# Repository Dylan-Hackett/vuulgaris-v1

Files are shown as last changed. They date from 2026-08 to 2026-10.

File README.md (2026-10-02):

# Vuulgaris V1

A 4-channel sample-scrubbing instrument. Long capacitive copper pads on a PCB faceplate
represent the length of a waveform; dragging a finger along a pad scrubs through the sample.
Each track carries a swappable machine that is either a sampler or a synth, with Plaits as
the synth engine.

```
[ FACEPLATE PCB ]
  4x capacitive pads, ~216mm (length follows the inter-pad gap, Q17)
  MSP430FR2675TPTR (CapTIvate touch MCU) on the back side
        |
        |  UART (primary) or I2C (fallback), + IRQ, + BSL entry lines
        v
[ MAIN PCB ]
  Daisy Patch SM (STM32H750) - audio engine, sample playback, UI
  microSD socket
  2.42" SSD1309 OLED (SPI)
  Rotary encoder
  Stereo Buchla-style low pass gate (analog)
```

## Layout

| Folder | Contents |
|---|---|
| [`docs/`](docs/) | `design-state.md` (source of truth), ADRs, open questions, pin allocation, panel budget |
| [`mockups/`](mockups/) | Parametric comb pad generator, Salamis faceplate reference + dimensioned |
| [`datasheets/`](datasheets/) | Manifest, fetch script and the datasheet PDFs. |
| [`hardware/`](hardware/) | Faceplate and main PCB, gerbers, BOM spreadsheet |
| [`fw-daisy/`](fw-daisy/) | Daisy Patch SM firmware. libDaisy + DaisySP as submodules. |
| [`fw-touch/`](fw-touch/) | MSP430FR2675 firmware. CCS + CapTIvate Design Center. |

## Start here

1. **[docs/design-state.md](docs/design-state.md)** is authoritative. Everything else is
   derived from it.
2. **[docs/notes/next-steps.md](docs/notes/next-steps.md)** step 0 is the thing to do first,
   and it is deliberately cheap: one 2-layer board with **two pads in final tooth geometry**,
   roughly $50 and 2 weeks. It answers whether a moving finger reads and repeats cleanly, and
   the second pad settles the inter-pad gap, which sets the size of the whole instrument.
3. **[docs/pin-allocation.md](docs/pin-allocation.md)** is resolved and safe to lay out
   against. Zero spare bidirectional GPIO, so any addition means a removal.
4. **[docs/panel-budget.md](docs/panel-budget.md)** is **not** settled, and it hinges on one
   measurement. The Salamis composition locks `pad length = 12 x pad pitch`, so the inter-pad
   gap ([Q17](docs/notes/open-questions.md)) sets the size of the whole instrument: a 6mm gap
   gives a 298 x 154mm panel with 216mm pads, a 10mm gap gives 365 x 189mm with 264mm pads.
5. **[docs/notes/open-questions.md](docs/notes/open-questions.md)** lists what is still
   unverified. Only one is a real design risk: **Q1**, whether a moving finger on bare copper
   reads and repeats cleanly. **Q10, Q13, Q15, Q18** are bench or datasheet checks. **Q17**
   (inter-pad gap) sets the instrument size. **Q7** is a cash decision.

## Setup

```bash
# Firmware submodules
git -C fw-daisy submodule update --init --recursive
cd fw-daisy && make libs && make

# Datasheets are committed; this re-fetches any that are missing
cd datasheets && ./fetch-datasheets.sh
```

## The three facts that shape everything else

**The MCU is on the faceplate, not the main board.** TI's design guide says keep
MCU-to-electrode traces as short as possible and explicitly warns against routing capacitive
sensing lines through board-to-board connectors or cables. That is what forces the two-board
split, and only ~8-10 digital pins cross between them.

**Accuracy is not the requirement. Monotonicity and continuity are.** You scrub by listening
and adjusting, so the loop closes through your ears and absolute position error is inaudible.
A bent curve is a lookup table. What cannot be fixed downstream is a **momentary reversal**
(sample stutters backward) or a **dropout** (click). Scan rate and jitter at rest are both
settled, see [Q1](docs/notes/open-questions.md). This is where the Trautonium pivot changed
the requirements: there, position was pitch and a 2% error was a wrong note.

**Electrode order is generated first, then laid out.** `RX0->E00, RX1->E01, RX2->E02,
RX3->E03`, produced in Design Center **before** the PCB. A swapped pair gives garbage
interpolation on a board that passes every electrical check.

**Every pot past the eighth costs a bidirectional GPIO.** CV_1-CV_8 are input-only pins that
can do nothing else, so the first 8 are free. Pots 9-12, the envelope attack and release for
each stereo side, take A2, A3, D8 and D9, and that consumes all 16 bidirectional GPIO exactly.
A 13th is impossible.

**Patch SM has two USB ports, and only one of them is on the header.** DFU flashing and USB
MIDI run on the module's own onboard Micro USB (PA11/PA12). **A8/A9 are a separate USB host
port**, spent here on IO. The cost is that USB access means unscrewing the module from the
rack; firmware ships via SD card instead.

## Decisions already made

| # | Decision |
|---|---|
| [0001](docs/decisions/0001-pivot-to-capacitive-scrubbing.md) | Pivot from Trautonium analog to capacitive sample-scrubbing |
| [0002](docs/decisions/0002-msp430fr2675-for-touch.md) | MSP430FR2675 (CapTIvate) for touch sensing |
| [0003](docs/decisions/0003-comb-pad-rx0-wraparound.md) | Comb-tooth pads with RX0 wraparound |
| [0004](docs/decisions/0004-no-overlay-exposed-copper.md) | Exposed copper, no overlay, ENIG |
| [0005](docs/decisions/0005-bsl-over-daisy-uart.md) | Daisy flashes the MSP430 over BSL |
| [0006](docs/decisions/0006-ssd1309-oled.md) | 2.42" SSD1309 over SPI |
| [0007](docs/decisions/0007-buchla-lpg-over-serge-vcfq.md) | Buchla-style LPG, not Serge VCFQ |
| [0008](docs/decisions/0008-boot-sram-not-qspi.md) | BOOT_SRAM, QSPI reserved for samples |
| [0009](docs/decisions/0009-io-plan-12-adc.md) | IO plan: 12 ADC, no mux, 1-bit SD, no panel USB |

## Cost

**$162.40 at qty 1** per [the BOM](hardware/bom/vuulgaris-v1-bom.xlsx), of which **$48.76 is
confirmed** against real listings and the rest is estimated. Inside the $125-200 range in
design-state section 10.

**The enclosure is not in that number.** The prior design was CNC walnut. It is cost lever
number 3 and currently unbounded.

Stock warnings that matter: **MSP430FR2675 has 10 units at LCSC**, and the **SSD1309 has 27**.
Both are prototype quantities.

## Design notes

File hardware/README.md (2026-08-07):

# Hardware

```
faceplate/   Faceplate PCB: 4x capacitive pads + MSP430FR2675 on the back
main/        Main PCB: Patch SM, microSD, OLED, encoder, stereo LPG
gerbers/     Fab outputs, one dated subfolder per order
bom/         vuulgaris-v1-bom.xlsx
```

## Two boards, and why

The MSP430 lives on the **faceplate**, not the main board. This is not a packaging
preference. TI's design guide says keep MCU-to-electrode traces as short as possible, and
explicitly warns against routing capacitive sensing lines through board-to-board connectors
or cables, which are significant noise receptors. Only ~8-10 digital pins cross between
boards. See [ADR 0002](../docs/decisions/0002-msp430fr2675-for-touch.md).

## Before you draw anything

1. **Generate the slider electrode assignment in CapTIvate Design Center first**, then lay
   out the PCB to match. `RX0->E00, RX1->E01, RX2->E02, RX3->E03`. Swapped pins produce
   garbage interpolation and the board will look fine.
2. **Cross-check the pad geometry against SLAA891's OpenSCAD output** before committing copper.
3. **Verify the LCSC C2052972 footprint against the datasheet PT package drawing.**

Q2 and Q3 are closed. [../docs/pin-allocation.md](../docs/pin-allocation.md) is resolved and
safe to build against.

**UART and I2C do not share pins on the PT package**, so route both and select in software. Two
mappings are traps: **UCA1 UART (pins 30/29)** and **default UCB1 I2C (pins 38/39)** both land
on CapTIvate electrode pins, which are all in use.

## Faceplate rules that are easy to violate silently

- **Do not ground-pour under electrodes or their traces.** Parallel-plate capacitance to a
  nearby pour is the dominant parasitic contributor. Hatched ground at a distance if needed.
- **RX0 is one net.** Both end groups connected, return routed on the layer below, never
  under the electrodes.
- **MCU at the centre of the pad group** so trace lengths are equal across all four pads.
  Unequal lengths give unequal baselines.
- **No electrodes at PCB edges.** Weakens ground shielding.
- **Route digital lines away from electrodes**, ideally exiting the opposite edge.
- ESD parts and decoupling caps right at the MCU, low-impedance ground path.
- **Minimum copper 0.15mm, enforced.** Where a ramp would go thinner, drop the bar and give
  its height to the surviving bar. Never draw a sliver.

Suggested stackup: **L1 electrodes, L2 traces, L3 hatched ground, L4 MCU + components.**

## Fab notes

- **ENIG, not HASL.** HASL leaves uneven solder that feels wrong under a sliding finger and
  will not wear well. [ADR 0004](../docs/decisions/0004-no-overlay-exposed-copper.md)
- **Faceplate size is not settled, and it follows from one measurement.** The Salamis
  composition locks `pad length = 12 x pad pitch`, so the inter-pad gap sets the whole
  instrument: 6mm gives **298 x 154mm with 216mm pads**, 10mm gives 365 x 189mm with 264mm
  pads. Settle [Q17](../docs/notes/open-questions.md) before drawing an outline. See
  [../docs/panel-budget.md](../docs/panel-budget.md).
- Exposed copper on the pads: no soldermask over the electrodes. Decoration and instructions
  in silkscreen.
- JLCPCB **does not do overlay lamination**, which is fine given the no-overlay decision.
- microSD sockets need an **assembly fixture** at JLC for support during placement. Not a
  trivial placement, flag it on the order.

## Things to put on the board even though they seem optional

| Item | Why |
|---|---|
| **CAPTIVATE-PGMR connector** (faceplate) | Design Center cannot talk to an MSP-FET or eZ-FET. No PGMR means no live sensor data, which means no real tuning. DNP on production units. |
| **4 SBW test pads** (TEST, RST, 3V3, GND) | Free, and it is the recovery path. A $12 LaunchPad eZ-FET flashes through them. |
| **Both UART and I2C to the faceplate** | Separate pins on the PT package, so both are free to route. Populate one. |
| **Dividers on BSL RST/TEST** | Gate outs are 0-5V, MSP430 max is 3.6V. Four resistors. |
| **VREG decoupling cap, MSP430 pin 31** | CapTIvate regulator output, not a supply input. Easy to miss, and it will not work without it. |
| **Test points on all 4 inter-board signals** | When BSL does not work first time you want a scope probe point that is not an LQFP pin. |

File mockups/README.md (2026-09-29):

# Mockups

## comb-pad-generator.html

**Superseded as the source of the copper by `generate-faceplate.py` below**, which draws the
pads in place on the panel. Kept for single-pad experiments. Open in any browser, no build
step; live-checks against fab limits and exports SVG at true mm scale, one `<g>` per net.

**Its defaults are the old 175mm / 12mm pad.** The settled geometry (2026-09-27,
[ADR 0003](../docs/decisions/0003-comb-pad-rx0-wraparound.md)) is 216mm long, 10mm wide, 8mm
gap, 100 teeth; the `12 x pad pitch` length lock it was built around turned out to be an
artefact of the reference sketch.

> **Cross-check its output against TI's SLAA891 OpenSCAD scripts before committing copper.**
> Those generate TI's own validated pattern and export DXF. Two independent generators
> agreeing is worth the hour it costs.

## salamis-faceplate-reference.svg

**The agreed layout as supplied**, 2026-08-06. Full Salamis Tablet composition: an irregular
crack line dividing a five-rule control group above from four scrub pads below, vertical dividers, semicircles,
eleven tick divisions per pad with crosses at the third, sixth and ninth, Greek acrophonic
numerals in the left, right and bottom margins.

Measured proportions, which now drive the panel size:

| Element | Units | Ratio |
|---|---|---|
| Panel | 580 x 300 | 1.933 : 1 |
| Pad length | 420 | **12.0 x pad pitch** |
| Pad pitch | 35 | |

**`pad length = 12 x pad pitch` is the load-bearing relationship.** Pitch is 12mm of copper plus
the inter-pad gap, so the gap sets the size of the whole instrument. See
[../docs/panel-budget.md](../docs/panel-budget.md).

## generate-faceplate.py  <-  the one to use

**Parametric, true-scale faceplate generator.** Emits SVG in **real millimetres** (1 user unit
= 1mm), including the actual comb-tooth electrode geometry.

```bash
python3 generate-faceplate.py                          > faceplate-v1.svg
python3 generate-faceplate.py --fab                    > faceplate-v1-FAB.svg
python3 generate-faceplate.py --placement              > ../hardware/placement-panel-facing.txt
python3 generate-faceplate.py --check                  # verification report, no SVG
python3 generate-faceplate.py --set pad_length_mm=264  # one-off override
```

### How to change the layout

**Edit the `CFG` dict at the top of the file. That is the whole interface.** Every dimension,
every position and both placement flags live there. Nothing in the drawing code needs touching.

| Want to change | Edit |
|---|---|
| Panel width | `pad_length_mm` (panel derives from it) |
| Panel depth | `panel_top_extra_mm` / `panel_bottom_extra_mm` — pure extensions. **Not** `composition_h_mm`, which re-flows every panel part |
| Pad spacing | `pad_gap_mm` |
| Tick count, cross positions | `n_ticks`, `cross_at` |
| How far the scale stops inside the copper | `scale_inset_mm` (ink only: the copper never moves) |
| The gap between each pad and the gold face | `pad_frame_mm` (ADR 0013; the scale hangs from it) |
| The mask block's fillets | `mask_fillet_mm` (outer), `mask_fillet_inner_mm` (where the gaps meet the via patch) |
| Knob size or spacing | `knob_r_mm`, `knob_pitch_mm`, `offset_knob_r_mm` |
| Switch openings | `switch_w_mm`, `switch_h_mm` |
| Encoder position | `encoder_lower_right` (True = beside pads, False = upper strip) |
| Divider style | `straight_divider` (False restores the irregular crack) |
| Tooth density | `teeth_per_zone` |
| Inscription | `inscription`, `inscription_h_mm`, `salamis_marks` |

### Always run `--check` after a change

It re-derives and asserts **14 properties**, each of which has gone wrong at least once during
design:

```
  OK  pads centred on panel width          margins 41.143 / 41.143mm
  OK  centre tick == pad divider           149.143 vs 149.143
  OK  tick spacing even                    [17.0] mm
  OK  crosses on clean fractions of the scale [0.25, 0.5, 0.75]
  OK  scale inside the copper (endpoint trim) 6.00 / 6.00mm, scale 204.0mm
  OK  pad block fits lower region          75.0 in 75.2mm
  OK  min copper bar >= fab floor          0.2360 vs 0.15mm
  OK  every tooth pair sums to pad width   11.80mm
  OK  upper assembly centred               content 266.00, margins 16.14mm
  OK  encoder clears pads / centred / within OLED span
  OK  switch slots vertical
  OK  OLED inside panel
```

Exit code is non-zero on failure, so it can gate a build.

### The copper it generates

Per [ADR 0003](../docs/decisions/0003-comb-pad-rx0-wraparound.md): **100 teeth per pad**
(25 per zone x 4 zones), 2.16mm pitch, 1.95mm tooth width. Each tooth splits into a top and a
bottom bar whose heights ramp complementarily from the presence functions, so **total copper per
tooth is constant along the pad**.

Output is grouped **one `<g>` per net** (`RX0`, `RX1`, `RX2`, `RX3`) for import as separate
copper zones.

**Minimum bar drawn is 0.236mm against the 0.15mm fab floor**, so no sliver ever needs dropping
at 100 teeth. Sampling at tooth centres rather than edges is what avoids it.

### The Salamis inscription

**Plain single letters, left margin only, below the divider rule.**

```
T P X F H F A N G F C T X
```

Codes in `CFG["inscription"]`: `T` tau, `P` rho, `X` chi, `F` digamma-like, `H` eta,
`A` alpha, `N` pi, `G` gamma, `C` lunate sigma.

### Two wrong turns, recorded so they are not repeated

**First pass** read the photo correctly as plain letters but drew them alongside an invented
Χ/Η/Δ/Π/Ι denomination ladder and a row of compound glyphs along the bottom.

**Second pass over-reasoned.** It theorised the F-like and gamma-like shapes were **compound
Attic numerals**, a Π nesting a smaller Χ, Η or Δ. That produced visually busy glyphs that did
not match the photo. The theory was plausible from the numeral system, but the photo shows a
few clean incised strokes per character, not nested forms. **Direct observation should have
outranked the theory.**

**Current version returns to the plain letters** and draws them with fewer, cleaner strokes.

**Still uncertain:** the F-shapes could be digamma, heta or a damaged gamma. All are drawn the
same rather than inventing a distinction the scan cannot support. Worth checking against a
high-resolution photograph before copper. `CFG["inscription"]` is a plain string.

**Drawn as strokes, not typeset.** The Ancient Greek codepoints have unreliable font coverage
and this file goes to a fab, where font substitution is a real risk.

**Placement.** `inscription_left_only` suppresses the right column. `inscription_below_divider`
keeps every letter under the divider rule. Both asserted in `--check`.

### Departures from the reference

- **The divider rule is straight**, not the irregular crack of the original tablet.
  `straight_divider = False` restores it.
- **The pads are centred.** The reference had 90 units of left margin against 70 of right.
- **The encoder sits in the lower region**, right margin beside the pads, below the OLED.
- **The two switch openings are vertical** (9 x 20mm), crossing rules 2 to 4.
- **13 tick divisions**, crosses at 4/7/10 rather than 3/6/9 of 11. Numerals are **generated
  from `cross_at`** by `numeral_strokes(n)`, so labels cannot drift out of sync with marks.
- **Everything printed is strokes, not text** (2026-09-29): `scale_marks()` and `panel_art()`
  hold every printed mark, the numerals drawn as monoline Ι / Π / Δ rather than typeset. The
  SVG draws them, and the faceplate prints the same strokes in black soldermask on its gold
  face (`hardware/faceplate/design/mkface.py`, ADR 0013). Knob, button and screw outlines are
  drawings of parts, not art, and are not printed.

### What it is NOT, yet

**Do not send this to a fab as-is.** Three things stand between it and copper:

1. **Pad length is provisional** until [Q17](../docs/notes/open-questions.md) settles the gap.
2. **Cross-check against SLAA891.** TI's OpenSCAD scripts export DXF; two independent
   generators agreeing is the real validation.
3. **Electrode-to-pin assignment comes from Design Center first**, then the PCB is laid out to
   match. This file draws geometry, not net assignment.

No drill file, no board outline layer, no soldermask openings, no copper pour.

## salamis-faceplate-dimensioned.svg## salamis-faceplate-dimensioned.svg

**Schematic view**, pads drawn as plain bands rather than teeth. Easier to read for composition
review than the full generated file. Same 298 x 154mm working proposal.

**Control layout, decided 2026-08-06:** OLED at the right end, all 12 knobs grouped together
**standing on rules 2 and 4** of the five-rule group. The **vertical divider separates the 8
channel pots (left) from the 4 envelope pots (right)**, with the downward semicircle at its
foot as drawn.

Knobs on the rules is faithful rather than convenient: the Salamis Tablet is a counting board
and the rules are where the pebbles sat.

**Channel numerals I, II, III, IIII are printed above the four knob columns**, matching the
pad numerals in the margins. Channels run as columns in the knob block but as rows in the pad
group, so without the numerals the mapping is not legible.

## faceplate-mockup.html

Faceplate rendering: the **Salamis Tablet** layout, drawn at 219 x 110mm.

> **Superseded** by `salamis-faceplate-reference.svg` above. This one draws the 3-zone /
> no-wraparound electrode ramp and a 219 x 110mm board, neither of which is current.

Four parallel pads as the line group, with the tablet's vertical divider, semicircles,
crosses at divisions 3/6/9, and Greek acrophonic numerals in the margins. Above an irregular
crack line sits a five-rule group with a vertical divider and downward semicircle for the
screen, encoder and switches. Below, four scrub pads with a vertical divider crossing all
four, capped by an upward semicircle.

> **This is out of date and must not drive layout.** It still draws the **3-zone /
> no-wraparound** electrode ramp (E1->E4, 60 teeth). It needs the **4-zone RX0-wraparound**
> pattern from [ADR 0003](../docs/decisions/0003-comb-pad-rx0-wraparound.md) first.
> Tracked as step 5 in [next-steps.md](../docs/notes/next-steps.md).

**Note:** this file is an HTML *fragment* (a `<div>` with inline SVG), not a full document.
Browsers render it fine on open. Wrap it in `<html><body>` if you need it to validate.

## Superseded layout, for the record

Two pads each side, two diagonal one way and two the other, forming a separated triangle in
the middle of a rectangular enclosure. If it is ever revisited:

- A 216mm pad at 45 degrees needs **~153mm per axis**, so the enclosure would need roughly
  300mm in the diagonal-spanning direction.
- Convergence points create **worst-case crosstalk exactly where RX0 sits on both pads.**
  Keep closest approach >=10mm with a grounded strip between.

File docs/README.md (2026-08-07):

# Docs

- **[design-state.md](design-state.md)** - the handoff document. The single source of truth
  for the whole project. Everything else in this folder is derived from it.
- **[pin-allocation.md](pin-allocation.md)** - **resolved.** Safe to lay out against.
- **[panel-budget.md](panel-budget.md)** - faceplate area arithmetic. **Working, not decided.**
  The 219 x 110mm in design-state section 11 does not fit the current design.
- **[workflow.md](workflow.md)** - how the instrument is actually played: four synced loopers,
  resampled through the analog LPG. **Working, not decided.** Recorded because it constrains
  hardware still being locked.
- **[decisions/](decisions/)** - ADRs for choices already made and expensive to revisit.
- **[notes/](notes/)** - open questions and the worklist. Expected to change.

## How these relate

`design-state.md` is authoritative and should be updated as things change. The ADRs pull
the *decided* parts out of it into one-file-per-decision form so that a decision and its
reasoning can be cited from a schematic comment or a commit message. The notes pull the
*undecided* parts out into a worklist.

If a fact appears in both design-state.md and an ADR and they disagree, design-state.md
wins and the ADR needs updating.

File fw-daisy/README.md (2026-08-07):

# fw-daisy

Firmware for the Daisy Patch SM: audio engine, sample playback, UI, and the link to the
touch MCU on the faceplate.

## Setup

```bash
git clone --recurse-submodules <this repo>
# or, if already cloned:
git submodule update --init --recursive

make libs     # build libDaisy + DaisySP, once
make          # build the application
make program-dfu   # flash over USB DFU
```

Requires `arm-none-eabi-gcc` and `dfu-util`.

## Submodules

| Path | Repo | Pinned at |
|---|---|---|
| `libDaisy/` | electro-smith/libDaisy | `c02245d` |
| `DaisySP/` | electro-smith/DaisySP | see `git submodule status` |

Both are shallow clones. To move to a newer libDaisy:
`cd libDaisy && git fetch --unshallow && git checkout <ref>`, then commit the pointer.

## Build type is not the default

`APP_TYPE = BOOT_SRAM`, deliberately. `BOOT_QSPI` runs the program from QSPI and can grow
to ~7.75MB, which eats the sample space. SRAM execution is also faster, with a ceiling of
roughly 480-512KB using a custom linker script.

See [ADR 0008](../docs/decisions/0008-boot-sram-not-qspi.md).

## Memory model

| Tier | Size | Volatile | Use |
|---|---|---|---|
| SDRAM | 64MB | yes | **Playback buffer.** Scrubbing is arbitrary random access, so samples must be resident. |
| QSPI | 7936 KB | no | Firmware (256KB offset) + factory samples |
| SD | unlimited | no | User samples |

SDRAM buffers are declared with `DSY_SDRAM_BSS` at global scope and cannot have meaningful
constructors. They are plain static arrays in `src/main.cpp`.

## Rules that will bite you

- **Display refreshes stay out of the audio callback.** CV output timing is documented as
  degradable by OLED and MIDI activity. No full-frame redraws during timing-sensitive CV.
- **DMA buffers must be in the DMA memory section and at global scope.**
- **Do not use B9/B10 for the encoder.** They are Input Only, and libDaisy defaults `GateIn`
  to inverted because of the suggested BJT input circuit.
- **ADC_9-ADC_12 pots wire to 3V3 (A10), CV_1-CV_8 pots wire to 5V (A6).** Different groups,
  different reference.

## Findings from the submodule source

Two open questions from `docs/notes/open-questions.md` were closed by reading the pinned
source. Recorded here because the design state still carries the old concern.

### Q4: the bootloader uses 1-bit SD, not 4-bit

`DaisyBootloader/shared/bootloader.cpp:164` (HEAD `8b279a8`):

```cpp
SdmmcHandler::Config sd_cfg;
sd_cfg.Defaults();
sd_cfg.speed = SdmmcHandler::Speed::MEDIUM_SLOW;
sd_cfg.width = SdmmcHandler::BusWidth::BITS_1;
```

So SD-card firmware drops work on 3-pin wiring. The worry was backwards: it is `libDaisy`'s
`Config::Defaults()` that is 4-bit @ 50MHz, and the bootloader explicitly overrides it.
**Route all 6 pins anyway** and pick the width in software.

### Q9: the SSD130x DMA path is live

`libDaisy/src/dev/oled_ssd130x.h`. `Update()` branches on `useDma_` and calls
`TransferPageDma(0)`, which calls `transport_.SendDataDma(...)` at line 646 with
`SpiPageCompleteCallback` chaining page to page. The commented-out line at 650 is a leftover
debug variant, not the real call.

The design state's concern that `SendDataDma` "appears commented out" is stale for this
revision. At 1KB per frame it barely mattered either way.

## TODO

- Touch link over UART/I2C + IRQ, and the BSL flashing path over RST + TEST
- Sampler engine: interpolated read from SDRAM at the finger position
- Plaits synth machine
- Position smoothing, tuned against **measured** jitter, not guessed
- SSD1309 UI
- Sample loading from QSPI and SD into SDRAM at boot

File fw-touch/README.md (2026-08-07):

# fw-touch

Firmware for the **MSP430FR2675TPTR** on the faceplate. Reads four capacitive scrub pads and
reports position to the Daisy over UART (or I2C).

## Toolchain

| Tool | Version | Note |
|---|---|---|
| Code Composer Studio | current | The IDE and compiler |
| **CapTIvate Design Center** | **1.83.00.08 (May 2020)** | Generates the sensor config. Stale, and its release notes say to re-create projects made in earlier versions. |
| **CAPTIVATE-PGMR** | hardware | **Required.** Not optional, see below. |

### The PGMR is not optional

The Design Center **cannot talk to an MSP-FET or a LaunchPad eZ-FET.** The PGMR carries a
separate MSP430F5528 running HID Bridge firmware that streams live sensor data to the PC as
a USB HID device. That live view is the entire point: jitter, scan time, linearity, trim.

There is **no FR2675 dev board.** TI's own evaluation recommendation is
**CAPTIVATE-FR2676 + CAPTIVATE-PGMR**, plus **CAPTIVATE-BSWP** which is listed as required
for self-cap designs and gives a reference slider baseline. FR2676 is the same silicon for
touch purposes, just 64KB/8KB against the FR2675's 32KB/6KB. The FR2676 board has a 48-pin
sensor panel connector for plugging in your own test pad.

**Migration note:** Design Center projects target a specific device. Regenerate for
**FR2675 (PT/LQFP-48)** when moving to your own board. CAP pin *naming* carries over;
physical pins do not.

## Layout

```
ccs/vuulgaris-touch/   CCS project
design-center/         .captivate project files
captivate/generated/   Design Center output, REGENERATED not hand-edited
tuning/                Measurement logs: scan time, jitter, linearity, trim values
docs/                  pin-assignment.md, bsl-protocol.md
```

## Order of operations, and it matters

1. **Generate the slider electrode assignment in Design Center FIRST.**
2. **Then lay out the PCB to match.**

`RX0->E00, RX1->E01, RX2->E02, RX3->E03`. Swapped pins produce garbage interpolation on a
board that passes every electrical check. See [docs/pin-assignment.md](docs/pin-assignment.md).

## Sensor configuration

Four sliders, four electrodes each, 5 segments / 4 interpolation zones with **RX0 appearing
at both ends** as a single net. Full geometry in
[ADR 0003](../docs/decisions/0003-comb-pad-rx0-wraparound.md).

**No overlay.** Direct finger-to-copper contact, which is outside TI's design assumptions
since all their tuning guidance assumes 1.5-4mm of plastic. Expect a **larger signal delta**
than the reference designs and **retune for lower conversion counts.** That is a gain, not a
problem: it buys margin on latency and filtering. See SLAA843.

### What to measure first

| Measurement | Where | Why |
|---|---|---|
| **Scan time across 4 sliders** | Design Center reports it directly | 4 blocks x 4 pins means each slider's elements scan in parallel, but the four sliders scan in **four sequential cycles**. Effective per-pad rate is 1/4 of a single-slider design. No published number exists for this config. |
| **Jitter at rest, in counts** | Design Center live view | Usable resolution is `configured_resolution / jitter_counts`. Set 1000 and measure N; the answer is 1000/N. **This is the number that decides whether scrubbing sounds like an instrument.** |
| **Linearity** | drag a finger, log position | Validates the ratio-encoded comb geometry. |
| **Lower_Trim / Upper_Trim** | touch each end, observe | A finger's centroid does not align with the slider endpoint, so most layouts cannot reach 0 and max. Plan for a few dead millimetres at each end. |

Log results in `tuning/`, dated, with the board revision noted.

### Noise immunity is a trade, not a free win

Enabling it turns on frequency hopping, aggregating four conversion frequencies. That
multiplies scan time **x4 on top of** the four sequential sliders. It is the first knob to
trade if latency is tight, weighed against sitting next to switching supplies and audio
circuitry.

## Do not touch the security settings

BSL code is in secure ROM and cannot be overwritten. Even with JTAG disabled, the BSL still
works. **The one permanent brick is deliberately disabling BSL *and* locking JTAG.**

**Rule: leave JTAG/SBW unlocked and BSL enabled.**

The 4 SBW test pads on the faceplate (TEST, RST, 3V3, GND) are the recovery path. A $12
MSP430 LaunchPad's eZ-FET flashes through them.

See [docs/bsl-protocol.md](docs/bsl-protocol.md) and
[ADR 0005](../docs/decisions/0005-bsl-over-daisy-uart.md).

## Bench stand-in

A SoftPot is a bad product part (needs pressure, +/-3% linearity, $9-27 each, finite cycle
life) and a fine **development** stand-in. Use one to settle firmware and scrubbing feel on
the Daisy side before cap-touch hardware exists.

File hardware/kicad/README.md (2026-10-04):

# Vuulgaris V1 — KiCad project (main PCB)

**Migrated from EasyEDA 2026-08-16.** Schematic connectivity is generated from a
declarative netlist and verified against KiCad's own netlister. Requires KiCad 7.

```
vuulgaris.kicad_sch   69 components, 217 connections, 66 nets — VERIFIED 217/217
vuulgaris.kicad_pcb   284.3 x 125.0mm on Edge.Cuts
lib/                  symbols + footprints (see below)
tools/                the generator and the netlist it generates from
```

## Why this exists

The EasyEDA version was abandoned after its API repeatedly reported success for
writes it had not performed — `deleteBoard` returning true having deleted nothing,
`importChanges` returning true and doing nothing, wires created at exact pin
coordinates that the netlister then refused to bind. It produced a board where
**`P3V3_DAISY` was shorted to `I2C_SDA` across 9 pads** and both LDO outputs sat on
GND, and no ERC would flag any of it, because every one of those is an electrically
legal connection. It was only ever caught by diffing pad nets against an explicit
intended map.

KiCad's design is a text file. A write either happens or raises. That is the whole
reason for the move.

## The verification loop

This is the thing worth preserving. `tools/netmap.json` is the **intent**: every
pin that carries a net, taken from `docs/pin-allocation.md`. The check is:

```bash
python3 tools/mksch.py && python3 tools/netcheck.py
```

`mksch.py` is the drawing engine; the design it draws — which symbol each ref uses,
where it sits on the sheet, which footprint it gets — is `tools/design.py`. They were
one file until 2026-09-27, when the faceplate needed the same engine. The loop tools
(`mksch`, `netcheck`, `drc`, `boardcheck`, `ksym`) all take `--project faceplate`;
`tools/proj.py` says where each project keeps what.

`netcheck.py` exports the netlist with `kicad-cli` — KiCad's own code, not a
reimplementation — and diffs every `(ref, pin) -> net` both ways. The reverse
direction is the one that matters: a pin KiCad bound to a net that `netmap.json`
never asked for is exactly the `P3V3_DAISY`-shorted-to-`I2C_SDA` failure above,
and no ERC will ever flag it. **Re-run it after any change.**

Then, before plotting fab files:

```bash
python3 tools/place.py --check && python3 tools/gerbercheck.py
```

And the one that has the last word on clearance:

```
python3 tools/drc.py
```

`drc.py` runs **KiCad's own DRC** through `pcbnew.WriteDRCReport`, because
`kicad-cli` in 7.0.8 cannot. It fails on anything the project settings call an
ERROR and merely counts WARNINGs, of which this board has ~270 silkscreen ones
that JLC clips at plot time.

`boardcheck.py` is still worth running — it is fast and it checks parity
against `netmap.json`, which DRC knows nothing about — but it is no longer the
authority on clearance. It reimplemented the geometry and got the X-crossing
case wrong, so two tracks lying on top of each other on `/LPG_LED` and
`/LPG_LEDK` measured 0.6mm apart and it reported the board clean for days.
Pcbnew found them in a second.
```

## Libraries

| Library | Source | Notes |
|---|---|---|
| `lib/vuulgaris.kicad_sym` + `.pretty` | `easyeda2kicad` from LCSC part numbers | Same geometry as the EasyEDA parts, not a reinterpretation |
| `lib/daisy_es.kicad_sym` | [GregBurns/sm_kicad](https://github.com/GregBurns/sm_kicad) | Daisy Patch SM **plus** a Eurorack kit — jacks, toggles, pots, LEDs, power symbols |

Adding a part:

```bash
easyeda2kicad --full --output lib/vuulgaris --lcsc_id CXXXXXXX
```

**The Daisy symbol here has all 40 pins including A7 (GND).** The EasyEDA community
symbol was missing A7 entirely, which passes ERC silently — a pin that does not
exist cannot be reported unconnected. That defect does not exist in this project.

**Footprint format caveat:** easyeda2kicad writes the legacy `(module ...)` form.
KiCad converts it correctly when loading from the library, but it cannot be pasted
raw into a `.kicad_pcb`. Pull footprints in via Update PCB from Schematic, not by
editing the board file.

## Placement

Two kinds of position, governed differently:

| | Governed by | Move it in Pcbnew? |
|---|---|---|
| **Panel parts** (20) | the faceplate artwork | reverted, and reported — a knob has to come through its hole |
| **Free parts** (23) | you | kept. `place.py` re-reads them every run |

So: **drag the free parts around in Pcbnew, save, and they stay put.** Their
positions are recorded in `tools/free-placement.json` so the layout shows up in a
diff. A part missing from that file is new — it just arrived via F8 — and gets
seeded once from `FREE_SEED`, then the board owns it. `--reset` throws away free
moves and goes back to the seed.

Panel-facing parts are **derived, not chosen** — their coordinates come from
`hardware/placement-panel-facing.txt`, itself generated by
`mockups/generate-faceplate.py --placement`. KiCad PCB space is Y-down and native
millimetres, the same convention as that file, so the only transform is the origin
shift:

```
pcb_mm = panel_mm - (6.995, 7.000)
```

**Footprint origin is not the shaft.** What must line up with a faceplate hole is
the shaft axis, and for three of these parts that sits away from the origin:

| Part | Footprint | Shaft / centre at | Evidence |
|---|---|---|---|
| ENC1-ENC10 | `SW-TH_EC12EXXXX` | `(0, -3.75)` | silk body centre **and** both mounting lugs |
| ENC0 | `SW-TH_ALPS_EC11L1525G01` | `(0, -0.20)` | bushing circle r 4.00 |
| RV1-RV6 | `RES-ADJ-TH_RK09L1240A12` (dual-gang, Alpha `RD902F` fitted) | `(0, -5.00)` — but **placed** at `(0, -4.83)`, see `place.py` | on the tab-slot line: the ALPS RK09L and Alpha RD902F drawings |
| SW4-SW9 | `KEY-TH_4P-L12.0-W12.0-P5.00-LS12.5` (12x12 tactile) | `(0, 0)` | pads symmetric about the origin |
| DS1 | `LCD-TH_HS242L01W4S01` | header, mid of the left edge | (folded into `PANEL`) |

Placing those by origin puts the knob 4-5mm off its hole, which nothing downstream
would flag. `ORIGIN_OFFSET` in `place.py` carries the correction.

**Only ENC0 and the pots have a bushing circle to key off.** The EC12 has none —
its only circles are four r=0.9 pad drill markers, and treating the largest of
those as a shaft puts the part 4.1 x 5.1mm out. Infer the shaft from the largest
circle *above r 1.5*, the silk body centre, and the largest pad, and accept the
part if **any** of them lands on the hole. That is what `place.py` does.

Because `ORIGIN_OFFSET` is an input, checking board positions back against the
panel file cannot validate it -- both sides use the same table, so a wrong value
passes in both directions. `place.py` therefore re-derives each shaft from the
footprint's own geometry and reports disagreement. That check is what caught
ENC1-ENC10 sitting 3.75mm high after they had already been committed and pushed.

`place.py` also reports **footprint overlaps**, bounding each part by its own pad
and outline geometry. No ERC or DRC catches a part sitting on another at this
stage, and it already caught U5 landing on ENC6.

## Editing protocol

> **This has now cost real work four times.** Pcbnew's in-memory snapshot has
> overwritten placement twice, the whole headphone block once, and -- worst --
> silently restored a **damaged board outline** after it had been repaired on
> disk. Close it.

KiCad holds the design in memory and both **F8 and Save read from that snapshot,
not from disk.** An Eeschema window left open while these tools run will silently
overwrite them on its next save, and F8 from a stale window reports "no changes"
for edits that are sitting on disk. **Close Eeschema and Pcbnew between hand-offs.**

### pose.py -- F8 does not remember which SIDE a part is on

`place.py` owns X/Y. It does **not** own layer or rotation, because those live only
in the board file. So every F8 that re-imports a footprint drops it back on `F.Cu`
at 0 degrees, and the work of flipping a block to the back is gone. **This has
happened three times:** the bypass caps, then the entire headphone block, twice.

`pose.py` is the other half. It snapshots layer+rotation for all 295 parts (160 of
which are not `F.Cu`/0) and puts them back:

```
python3 tools/pose.py --save     snapshot what the board currently is
python3 tools/pose.py --check    report what drifted, write nothing
python3 tools/pose.py            put it back
```

**Order after an F8:** `place.py` -> `pose.py` -> `place.py --check`.

A pad's angle in the file is **absolute** -- the footprint rotation is already
folded in -- so turning a footprint means rewriting every pad angle. `pose.py`
recovers the relative angle from the board's own current pose rather than from the
library, because the library lookup is keyed on pad coordinates that do not always
match, and a miss there invents a rotation out of nothing. That is what put 270 on
J9's oval pads, which carry none. Verified by clobbering all 160 posed parts to
`F.Cu`/0 and restoring: byte-identical except for the silkscreen note below.

> **That silkscreen note was the tip of a real bug.** Back-side text missing
> `(justify mirror)` turned out to correlate perfectly with footprints that had
> been moved to `B.Cu` by rewriting layer names and nothing else. See below.

## A B.Cu footprint has to be MIRRORED, not just relabelled

**KiCad applies no implicit mirror.** Proven 2026-09-09 with `kicad-cli pcb export
svg`: a pad at footprint-local `(0, +3)` plots to the *same absolute place* whether
its footprint sits on `F.Cu` or `B.Cu`. Front and back render identically.

So the flip has to be **baked into the stored coordinates**. A part on the back
carries negated local Y; a part whose coordinates still match the library is not
flipped, it is the **front land pattern printed on the back layer** -- pin 1 where
pin 8 belongs, chip soldered mirror-image.

**Thirteen parts were in that state**, and they were not minor ones:

`Q1`, `Q2`, `U101`, `U102`, `U103`, `U104`, `U106`, `U201`, `U202`, `U203`,
`U204`, `U206` -- both V3205SD bucket brigades, both CD4046 clocks, five of the
six TL072s, and both transistors. Effectively the whole analogue block. That board
would not have worked.

### Why nothing caught it

`place.py` was computing every back-side part's geometry with an extra mirror of
its own (`mir = -1.0 if side != F.Cu`), so a half-flipped part came out looking
right: two errors that cancelled inside the checks. The old comment on that line
claimed Gerber verification against J7 and J11 -- but **J7 is correctly mirrored
and J11 is on the front**, so the check compared a double mirror against a single
one and read the agreement as proof.

The tell was sitting in the same file the whole time. `place.py`'s pad-**angle**
check already assumed baked-in mirroring (`rel = -lib_angle` when on the back).
The position maths and the angle maths had contradicted each other for months.

### The guard

`place.py` now fails loudly on any `B.Cu` footprint whose asymmetric pads still
match the library. Symmetric parts (every 0603) are skipped, because for them a
Y-mirror is a no-op. Verified by deliberately half-flipping `U102` and confirming
it is named.

> Do not "flip" a footprint by editing layer strings. Use `pose.py`, which mirrors
> geometry, swaps the layer names, and mirrors the text justification together.

### The bug that pass shipped, and how it showed up

Splitting a board file into footprints by "start of one to start of the next,
with end-of-file as the last boundary" makes the **last footprint's block swallow
everything after it** -- `Edge.Cuts`, the zone, all of it. The mirror transform
then negated Y on the board outline, and the faceplate connector cutout came
apart.

The four `gr_arc` corners survived, because the negation regex wanted
`(start ...) (end ...)` adjacent and an arc carries a `(mid ...)` between them.
So the cutout lost its four straight edges and kept its four rounded corners --
which is the sort of luck that hides a bug instead of revealing it. It took
someone looking at the board to notice.

`place.py`'s `fp_blocks` had always done this correctly, walking to the balanced
closing paren. `pose.py` rolled its own and got it wrong.

**And then it came back.** The outline was repaired on disk and committed, but
Pcbnew still held the pre-fix board in memory; the next save wrote its snapshot
straight over the repair. What that looks like from the outside is an outline
that "needs to be moved" -- the parts sit at y 50-167 and the outline at y -50 to
-167, so it is drawn nowhere near the board. `place.py` now checks the outline
**before** it measures anything against it, because "pads inside the outline"
passes trivially when the outline is somewhere else entirely. **Every tool that slices
this file now ends a block at its balanced paren**, and the same bug was silently
dropping `pose.py`'s writes on three parts, which is why C505 and C511 kept
reverting to a rotation nobody asked for.

## place.py checks the board is actually THERE, and that the chip is not

Two placement mistakes got past the checks in one day, both the same shape: the
search enforced **pad**-to-pad clearance and nothing else.

**1. The board has a hole in it.** The faceplate-header cutout is 24 x 12mm at
board (210, 97.5)-(234, 109.5). "Bodies/pads inside the outline" only bounds the
board RECTANGLE, so two test points placed in the slot passed every check and were
caught by eye. `place.py` now reads interior `Edge.Cuts` loops and reports
`clear of all N board cutout(s)`.

**2. A pad can sit under a chip without touching a pad.** `V3205SD` is a DIP-14
land pattern with the middle three pins omitted on each side, so there is a wide
pad-free gap down the centre of a package that is physically still there. Two test
points landed in that gap: 2mm from any pad, and underneath the plastic. The
`body overlaps, SAME face` list already caught it -- the placement search did not,
because it only looked at pads. Searches now check **body separation as well as pad
clearance**.

The general lesson, twice over: *pads are not the part, and the outline is not the
board.*

## The courtyards in this library are FAKE -- do not trust a courtyard DRC

Every `easyeda2kicad` footprint here has its courtyard drawn as the **plastic body
outline**, which is *smaller than its own pads*:

| footprint | courtyard | pads actually reach |
|---|---|---|
| `C0603` | +/-0.80 x +/-0.40 | **+/-1.10 x +/-0.45** |
| `SOIC-8_L4.9-W3.9-P1.27-LS6.1-BL` | +/-2.50 x +/-2.00 | **+/-3.05** |

IPC says a courtyard is pads + body + margin. These are body-only. A courtyard
overlap check -- **including KiCad's own DRC** -- therefore passes a board whose
parts physically collide, and this board reports **0 courtyard overlaps** while
having had parts 0.64mm apart. That is why nothing ever complained.

**So clearance here is checked pad-to-pad in `place.py`, not by courtyard.** If you
ever run KiCad's DRC, its courtyard result means nothing until the library is
fixed.

## Crowding: overlap is not the only failure

`place.py` reports the **tightest pad-to-pad clearance on the board** and lists
everything under 1.0mm. Being on the same net earns a part nothing here — the
connection is made by copper, not by proximity, and a 0603 sitting 0.3mm off a
SOIC pin passes every overlap check while still being impossible to rework.

JLC's assembly floor is ~0.2mm, but that is a *fabrication* limit, not a working
clearance, so the check warns at **1.0mm** and only fails under **0.45mm**.

Current tightest, all understood:

| gap | pair | why |
|---|---|---|
| 0.80mm | SW4/5, SW6/7, SW8/9 | the button column pitch. 14.7mm shorts outright, 15.5mm leaves 0.8mm — a deliberate floor, and they are through-hole so hand-solderable |
| 0.82mm | DS1 x J1 | pre-existing, OLED header against the SD socket |
| 0.95mm | TP8/10/11/12 | test points, placed to 0.4mm search clearance |

The 24 bypass caps used to sit at **0.64mm** — I put them there chasing short
decoupling paths and it was too tight to get an iron in. Re-placed against a
**1.0mm pad-to-pad floor**; the cost was almost nothing, 2.1-3.1mm from the power
pin became 2.4-3.2mm.

## The LPG trimmers are SMD and live on the BACK

`RT301`/`RT401` are **3224W-1-203E**, LCSC **C55071** -- the SMD sibling of the
Bourns 3266W they replaced: same 4mm square multiturn cermet, **12 turns**,
top-adjust. Footprint pulled with `easyeda2kicad`, same as every other part here.

**Multiturn is not optional.** These set the vactrol LED drive depth, which is
adjusted by ear against a scope at bring-up. The 3x3mm single-turn parts on LCSC
are cheaper and better stocked, but they put the whole 20k into 270 degrees.

**They sit on `B.Cu` while the rest of the LPG is on `F.Cu`.** The front is under
the faceplate, so a top-adjust trimmer there is only reachable with the panel off.
Vactrols age -- and these are the Xvive reissue with known batch spread -- so
re-trimming is a real event, not a one-off.

Swapping this also took two parts off the hand-solder list. What is left there is
genuinely unsourceable rather than merely inconvenient: `V3205SD` x2, `VTL5C3` x4,
the DW3 switches x2, and the Daisy module.

> **Changing a footprint needs more than F8.** "Update PCB from Schematic" only
> syncs nets and adds/removes parts by default; a footprint swap on an
> already-placed component is opt-in. Tick **"Replace footprints with those
> specified in the schematic"** or nothing happens -- silently, with the dialog
> reporting success.

## Input level: the 1/4" jacks are a LINE input, and were wired at unity

`J7`/`J8` fed `U1.B3/B4` through nothing but a coupling cap. The Patch SM's full
scale is Eurorack 9.5Vpp = 3.36Vrms, so a normal source lands well short:

| source | nominal | at unity |
|---|---|---|
| receiver / RCA line out | 0.32Vrms | **-20.5dBFS** |
| phone or laptop headphone out, full | ~1.0Vrms | **-10.5dBFS** |
| pro +4dBu | 1.23Vrms | -8.7dBFS |

**Software gain does not fix this.** Digital gain lifts the converter's own noise
floor with the signal; 20dB below full scale is 20dB of ADC dynamic range already
gone. Only analogue gain ahead of the ADC gets it back.

Worth being explicit about why this is a line input and not a Eurorack one: **audio
I/O is PJ-603 (1/4"), CV is PJ-376 (3.5mm).** Nothing Eurorack arrives at J7/J8
without an adapter, so there was never a reason to calibrate them for 9.5Vpp.

### U10, and where it sits

```
J7 tip --R517 1k-- C511 1uF --+-- U10A +        gain = 1 + RT503/R521
                            R519 100k                = 1x to 10.1x  (0 to +20dB)
                              GND
                   U10A - --+-- R521 2k2 -- GND
                            +-- RT503 20k rheostat -- U10A out
                   U10A out -+-- C501 1uF -- SW2.1
                              +-- R302 10k -- LPG input mix (C306)     since 2026-09-25
```

**U10 also drives the LPG directly** (ADR 0011): its output is mixed with the Daisy's into
the LPG input through `R302`/`R402`, so external audio reaches the analog chain with no
conversion and can be resampled after the effects in one pass. `C306`/`C406` block its DC
there, as `C501` does on the way to the Daisy.

**Before SW2, on the EXT branch only** -- the resample path is already at Eurorack
level and must not be gained.

- `U10` is a second **OPA1688**, the same part and footprint as U9. No new library work.
- `RT503`/`RT504` are the same **3224W** 12-turn as every other trim here, on `B.Cu`.
  Wiper tied to one end, as `RT301` is: a wiper fault then gives maximum resistance
  rather than an open feedback loop.
- At minimum the trimmer is 0R and the stage is a unity follower, so a hot source
  is still safe.
- `C501` already blocks DC into SW2, so U10's offset never reaches the Patch SM and
  the feedback leg needs no cap of its own.
- `R519` 100k sets the input impedance -- a proper bridging load -- and gives 1.6Hz
  with `C511`.
- `R517`/`R518` 1k are series protection. There was none: `C501` went straight onto
  a module pin, and a source peaking at +18dBu is 17.4Vpp against a +/-4.75V input.
  Against 100k the 1k costs under 0.1dB.

## The audio coupling caps are 0805, and they were never going to be film

Fourteen caps carried the value **"1uF film" in an 0603 footprint**. That is not a
part anyone can ship. SMD film tops out around **0.1uF** (PPS, Panasonic ECHU) in
1210; 1uF film means a leaded box cap about 7x7mm on a 5mm pitch -- through-hole,
hand-soldered, on a board whose hand-solder list was deliberately cut down to four
genuinely unsourceable parts. Whatever got assembled was always going to be a
Class II MLCC, and the value string was describing a wish.

`C113 C120 C213 C220 C306 C406 C501 C502 C503 C504 C505 C506 C511 C512`
-> **1uF X7R 50V, C0805.**

**Why 0805 and 50V rather than just renaming them.** Class II voltage-coefficient
distortion scales with the field across the dielectric. A 1uF 50V part in 0805 has
more and thicker layers than a 1uF 16V part in 0603, so on a **+/-4.75V Eurorack
signal** -- nearly a third of a 16V part's rating -- it distorts substantially
less for the same job. Same money, same reel, same pick-and-place.

**1uF C0G would be genuinely linear and is not an option**: it does not exist below
2220, runs a few dollars each, and fourteen of them would cost more than the rest
of the passives put together and swallow the board.

Eleven of the fourteen took the bigger footprint where they stood. `C505` turns 90
degrees to clear J6's body, `C511` moves 3.4mm, `C512` 0.25mm.

> **This one needs the checkbox.** A footprint swap on an already-placed part is
> opt-in: tick **"Replace footprints with those specified in the schematic"** in
> the F8 dialog or nothing happens, silently, with the dialog reporting success.

## Output levels: three different jobs, three different levels

Everything inside the instrument runs at **Eurorack level, 9.5Vpp (+/-4.75V)** --
verified from the Patch SM datasheet v1.0.5, which benchmarks SNR against exactly
that reference sine. Bergman's LPG expects the same, so `AUDIO_OUT -> LPG ->
AUDIO_IN` is level-matched end to end. See `docs/design-state.md` section 6.

`BBD_OUT_L/R` is that node. **Three things hang off it, and only one of them wants
Eurorack level:**

```
U103 --470R(R131)-- BBD_OUT_L --+-- C503 1u ---- SW2 -- AUDIO_IN_L    9.5Vpp, internal
                                |
                                +-- C505 1u -- R509 100k -+- RT501 20k -- GND
                                |                    wiper |
                                |                          U9 (unity) --4R7-- J6 tip
                                |
                                +-- R513 1k2 --+-- J9 tip   (1/4" line out)
                                              R514 1k
                                               GND
```

**The attenuators sit DOWNSTREAM of the C503 and C505 taps.** That is the whole
trick, and it is the reason nothing internal had to change: the resample loop and
the headphone feed still see the Eurorack level they were designed around, while
the jack sees whatever the divider gives it.

*Nearly* that level: the taps are on the far side of `R131`, and the line-out
divider loads that node with 2.2k, so `BBD_OUT` sits at 2200/2670 = 0.82 of
U103's swing, **-1.7dB**. The resample path reaches the Patch SM about 2dB under
full scale instead of at it. Harmless, but it is not the unloaded buffer level.

### 1/4" line out (J9/J10) -- +4.2dBu full scale

`R131` 470R is already in series, so the divider is **(470 + 1200) : 1000**.
(`R513`/`R515` are 1k2 on the board. This section was written for 1k3; the
numbers below are for 1k2, 0.3dB hotter.)

| | |
|---|---|
| ratio | 1000/2670 = 0.375, **-8.53dB** |
| full scale | 3.359Vrms -> **1.258Vrms = +4.2dBu** |
| output impedance | 1670 \|\| 1000 = **625R** |
| load on U103 | 2670R -- a TL072 is rated to 2k, so this is inside spec |

It was **+12.7dBu** before, straight off the buffer. That survives a pro interface
(+18 to +24dBu max) but clips consumer -10dBV gear and anything with an instrument
input. +4.2dBu is safe everywhere and still hot enough to ignore the noise floor:
625R of thermal noise is 3.2nV/sqrt(Hz), about **-125dBu** over 20kHz.

Passive is the right answer here -- U103 already buffers the node, so a divider
costs two 0603s and no active parts. Into a 10k line input you lose another 0.5dB.
Into a 600R vintage input you lose 6.2dB, which is the one case worth knowing about.

### Headphones (J6) -- set once, on the back

`RT501`/`RT502` are the same **3224W** 12-turn cermet as the LPG trimmers, on
`B.Cu` for the same reason. Max attenuation is 20k/120k = 1/6, giving **0.56Vrms**
at the buffer output.

> **U9's own bypass caps were 15mm away, and nothing was checking.** `C507`/`C508`
> were never in `place.py`'s `BYPASS` table, so the headphone driver shipped with
> decoupling that was decoration -- the trace inductance in series with a 100nF at
> that distance undoes most of what it is for. Adding U9 and U10 to the table
> caught it immediately; `RT502` had to move 7.5mm off pin 8 to free the pocket.
> **Every chip with a bypass cap belongs in that table**, or the check is only
> auditing the parts that were already right.

`R511`/`R512` are **4R7, not 22R.** They sit OUTSIDE the feedback loop -- U9's
feedback comes off `HP_BUF_L`, before them -- so they set output impedance directly:

| load | with 22R | with 4R7 |
|---|---|---|
| 32R | 0.332Vrms, 3.4mW | **0.488Vrms, 7.4mW** |
| 250R | 0.550Vrms, 1.21mW | 0.550Vrms, 1.21mW |
| 600R | 0.556Vrms, 0.51mW | 0.556Vrms, 0.51mW |

22R cost 4.6dB into 32R cans, but the real problem was **damping factor 1.5.**
The rule of thumb is Zout <= 1/8 of the load; dynamic headphones have a bass
impedance resonance peaking at 2-4x nominal, so 22R bumps the low end by a
different amount for every pair you plug in. 4R7 is 1/6.8 of 32R -- close enough
to the rule, and flat.

The OPA1688 does not need the isolation: it is a purpose-built headphone driver,
internally short-circuit protected, +/-75mA, unity-gain stable. At 0.488Vrms into
32R it sources 22mA peak. TI's own headphone circuits use 10R or nothing.

**No output coupling cap, deliberately.** `RT501`'s bottom end grounds the divider,
so the wiper sits at 0V DC and U9 contributes only its own offset (+/-0.5mV typ).
A few mV across 32R is 0.1mA -- inaudible, and better than the electrolytic every
cheap headphone amp puts there. The input highpass is C505 1uF into the full 120k:
**1.33Hz**, and it does not move with the trimmer, because the wiper position does
not change the end-to-end resistance.

## Net classes and trace widths

Set 2026-09-09, from IPC-2221 against the real stackup: **1oz outer (35um),
0.5oz inner (15.2um)**, 10C rise. `I = 0.048 * dT^0.44 * A^0.725`, A in mil^2.

| width (1oz outer) | carries at 10C rise |
|---|---|
| 0.25mm | 0.88 A |
| 0.50mm | 1.45 A |
| 0.60mm | 1.65 A |
| 1.50mm | 3.21 A |

| class | nets | track | clearance | via |
|---|---|---|---|---|
| `Power_5V_IN` | `VBUS`, `VBUS_F` | **1.5mm** | 0.20mm | 1.0/0.5 |
| `Rails_12V` | `POS12V`, `NEG12V`, and both `_RAW` | **0.6mm** | 0.20mm | 0.8/0.4 |
| `Power_5V` | `P5V`, `P5V_OLED`, `P5V_MSP`, `P5V_BBD` | 0.5mm | 0.20mm | 0.8/0.4 |
| `Power_3V3` | `P3V3_DAISY`, `P3V3_MSP430`, `P3V3_OLED` | 0.5mm | 0.20mm | 0.8/0.4 |
| `GND` | `GND` | 0.5mm | 0.20mm | 0.8/0.4 |
| `Default` | everything else, audio included | 0.25mm | 0.20mm | 0.8/0.4 |

Clearance is 0.20mm in every class (commit `5141496` relaxed the two that were
wider). Eleven vias are **0.6/0.3**, not the class size: ten on `ENC4_A/B`,
`ENC8_A/B` and `BTN4`, where U4's pins would not escape with 0.8/0.4 (2026-10-03,
`docs/review/recheck/fix-mcp23017-gpa7-gpb7.md`), and the one that feeds `C44`
from U4.9's track, between the two legs of `ENC8_B`. The board minimum is 0.5/0.3.

**`VBUS` is the only rail ampacity actually constrains.** It feeds the DKM10E-12
through a 2.0A PTC, and IPC wants **0.78mm** for that. 1.5mm carries 3.21A at 10C
and is still only about 20C at the PTC's **4.0A trip** -- a fault condition, not a
duty cycle.

**The 12V rails are wide for impedance, not for heat.** The DKM is 10W across both,
so roughly 420mA each, and IPC wants **0.09mm**. That is a hair, and a hair is a
bad idea on a rail feeding eleven op-amps: 0.6mm is about 4x the requirement and
is chosen so the rail is stiff and reworkable.

> **Keep power on F.Cu / B.Cu.** The inner layers are 0.5oz, and IPC-2221 uses a
> halved constant for internal traces. Carrying `VBUS`'s 2A on In1.Cu would need
> **4.7mm**; even the 12V rails would want 0.54mm rather than 0.09mm. In2.Cu is
> the ground plane and In1.Cu is for signals.

Net-to-class assignment lives in `vuulgaris.kicad_pro` under
`net_settings.netclass_patterns`, keyed on the board's net names, which carry a
leading `/` (`/POS12V`, not `POS12V`).

## Autorouting, with GND left alone

KiCad 7 has no autorouter and `kicad-cli` cannot export DSN, so routing goes out
to **Freerouting** and comes back as a Specctra session.

**Installed 2026-09-09:** `~/tools/freerouting/freerouting-2.4.1.jar`, 64,076,787
bytes, sha256 `251101c3eeac22d7e7dfcf6796603279e5d1000283eb82d8f093780f7afc6aa9`,
from the project's own GitHub release v2.4.1 (2026-09-03). Its manifest is built
by GitHub Actions with Adoptium 25 and its classes are major 69, so it wants
**JRE 25 or newer**; this machine has openjdk 26.0.2.1.

Only the export and import steps need the GUI. **The routing itself is headless**,
which means it can run unattended and be repeated:

```
# 1. Pcbnew:  File > Export > Specctra DSN   ->  vuulgaris.dsn
python3 tools/dsnfilter.py vuulgaris.dsn

# 2. route -- no GUI, no clicking
java -Djava.awt.headless=true -jar ~/tools/freerouting/freerouting-2.4.1.jar \
     -de vuulgaris-noGND.dsn \
     -do vuulgaris.ses \
     -mp 100

# 3. Pcbnew:  File > Import > Specctra Session
# 4. fill the In2.Cu GND zone, then place stitching vias by hand
```

`-mp` is the pass count, `-mt` the thread pool (defaults to one fewer than the
logical processors). Because it is scriptable, a bad result costs one command,
not an afternoon -- change the rules or the filter and run it again.

### What dsnfilter.py takes out, and why

**`/GND`.** Its `(net ...)` block goes, and its name is scrubbed out of every
`(class ...)` member list -- a KiCad DSN names each net twice, and deleting only
the block leaves the class quoting a net that no longer exists. Ground pads then
carry no net, so Freerouting treats them as plain obstacles to keep clear of and
never wires them. Ground comes from the plane plus hand-placed stitching vias.

**`In2.Cu`.** It is the ground plane, typed `power` in the board. Leave it in the
DSN's layer list and the router will put signal traces on it and turn the plane
into swiss cheese -- the return path under every sensitive trace, gone. Routing
stays on `F.Cu`, `In1.Cu`, `B.Cu`.

Parsing is balanced-paren, not regex, because a nested `(pins ...)` inside
`(net ...)` is exactly the shape that makes a naive split eat the rest of the
file. Verified against a fixture with nested pin lists and two classes.

### Do not autoroute this board wholesale

It is a bucket-brigade delay with vactrol gates, a capacitive touch interface and
a switching supply, all on one card. An autorouter optimises for completion, not
for keeping the CD4046 clock away from `BBD_SIGIN`, and it has no idea that
`AUDIO_OUT_L` and `BBD_CLK_L` should never run parallel.

Hand-route first, in this order, then **lock** those tracks before exporting DSN:

| | why |
|---|---|
| `VBUS`/`VBUS_F`, then +/-12V | 1.5mm and 0.6mm, and they set where everything else can go |
| BBD clock -- `BBD_CLK_L/R`, `BBD_CLKN_L/R`, the CD4046 nets | the loudest aggressor on the board; keep it short and away from audio |
| audio -- `AUDIO_*`, `BBD_*` signal, `LPG_*`, `HP_*`, `EXT_*` | short, direct, never parallel to the clock |
| `P5V` from U1.A6 | star out to FB1 and FB2, not daisy-chained |

Then let Freerouting have the digital remainder: I2C, SPI to the OLED, the SD
lines, the encoder matrix. Those tolerate meandering; the analog does not.

## Test points

Fifteen, all `TestPoint_TH_D1.0mm` (1.0mm drill / 2.0mm pad -- a probe hooks it or
a wire loop solders in). The silk carries the **value, not the reference**: `TP8`
tells you nothing at a bench, `SIGIN L` does.

### Signal (TP6-TP15) -- beside the node they probe, not in a row

| ref | net | silk | why it exists |
|---|---|---|---|
| TP6/TP7 | `BBD_DRY_L/R` | DRY L/R | the mki manual's **TP1**. `R104` is 0R and its value is a bring-up decision -- these let you choose it with a scope instead of by ear |
| TP8/TP9 | `BBD_SIGIN_L/R` | SIGIN L/R | the manual's **TP3**. Watch for clipping onset while setting the above |
| TP10/TP11 | `LPG_LED_L/R` | LED L/R | `RT301`/`RT401` are trimmed **by hand** -- you cannot set a trimmer you cannot measure |
| TP12/TP13 | `BBD_CLK_L/R` | CLK L/R | the two 4046 clocks. Their mistracking **is** the stereo width, and this separates a dead VCO from a dead BBD |
| TP14/TP15 | `TIME_CV`, `LPG_ENV` | TIME CV / LPG ENV | the two DAC outputs. Splits any fault into firmware or analog in one probe |

**TP6-TP15 are on `B.Cu` and their labels print on `B.SilkS`** -- the front is under
the faceplate, so the back is where you actually probe. TP1-TP5 stay on the front:
they sit in an empty corner and are fine there.

**Eight of them sit in one row at y=104, 8mm pitch** (`DRY L`, `SIGIN L`, `DRY R`,
`SIGIN R`, `LED L`, `LED R`, `TIME CV`, `LPG ENV`). Scattered singletons wedged
into gaps were hard to find and worse to look at, and the **label** is what makes a
test point findable, not proximity -- so a labelled row costs nothing.

**TP12/TP13 (`CLK L`/`CLK R`) deliberately stay beside their own 4046.** They carry
the BBD clock, and dragging a 100kHz square wave 100mm across the board to a probe
pad is a noise injector sitting next to the audio, not a debugging aid. Everything
in the row is a driven, slow node that does not care about the stub.

## Power test points

`TP1`-`TP5` in the top-left corner, 4.5mm pitch, footprint `TestPoint_TH_D1.0mm`
(1.0mm drill / 2.0mm pad -- a probe hooks it or a wire loop solders into it).

| ref | net | silk |
|---|---|---|
| TP1 | `POS12V` | **+12V** |
| TP2 | `NEG12V` | **-12V** |
| TP3 | `P5V` | **+5V** — the Daisy's 5V, feeding the OLED and MSP430 regulators |
| TP4 | `P5V_BBD` | **+5V BBD** — the AMS1117 output; **this is the unmeasured one** |
| TP5 | `GND` | **GND** |

Three deliberate choices: the silk carries the **value, not the reference** (`TP3`
tells you nothing at a bench, `+5V` does); they are **through-hole** so they can be
probed from either face, which matters because the front is under the faceplate;
and they sit at the **far end from the power stage** on purpose, because what you
want at bring-up is what the far end of the board receives, not what the regulator
makes. GND is in the row so probe loops stay short.

## Chassis lugs are grounded, deliberately

All 30 mounting tabs go to GND: `ENC0` pins 6/7, `ENC1`-`ENC8` pins D/E, `RV1`-`RV6`
pins 7/8. In each footprint these are the large slotted ovals set apart from the
signal pads, not signal pins -- note that on the EC11 (`ENC0`) it is **6 and 7**
that are the lugs, because **D and E there are the push switch**.

They are grounded rather than left open because this instrument reads
capacitance. A floating metal shell directly behind the touch panel is an
antenna. The solder joints also take the mechanical load off the signal pins.

**Consequence to watch at assembly:** the shells are bonded to the bushings, which
the nuts clamp to the faceplate. If the faceplate ever gets a ground pour near
those holes, main-board GND and faceplate GND are joined through the panel
hardware in parallel with J12's ground wires. That is usually fine and often
desirable, but it is a second path and worth knowing about before chasing a hum.

## kpins.json is generated, untracked, and easy to generate WRONG

`tools/kpins.json` is the pin-geometry cache `mksch.py` reads. It is not in git.
Rebuild it with the exact argument list in `ksym.py`'s docstring -- **project
libraries last, and never `lib/*.kicad_sym`**.

**Why the list is explicit rather than a glob:** `lib/daisy_patch_sm.kicad_sym`
was never in `sym-lib-table` but held a second, different
`ES_DAISY_PATCH_SM_REV1` -- A6 at x -5.08 instead of -1.27, A10 at -7.62 instead
of -6.35. Including it made mksch.py draw the power stubs in the wrong place;
`U1.A6` and `U1.A10` silently stopped connecting on a schematic that looked
correct, and netcheck caught it as `unconnected-(U1-+5V-PadA6)`. **That file is
deleted as of 2026-09-07** (committed in 398a1f2, referenced by nothing), but
any duplicate symbol name will do the same thing, so keep the argument list
explicit.

Running `ksym.py` with no arguments writes an empty cache and mksch.py dies on a
KeyError.

## Still open (unchanged by the migration)

- ~~**The LPG.**~~ **DONE 2026-09-06** — stereo Bergman LPG is in `netmap.json` and on the board. See [lpg-bergman.md](../../docs/lpg-bergman.md).
- **Jack pinout.** `PJ-603` (J7-J10) **RESOLVED 2026-09-06** from the Legion/Haoyu
  drawing behind LCSC C41409498: **2 = sleeve, 4 = tip, 3 = normalling switch onto
  the tip, 5 = ring.** The drawing's SCHEMATIC box settles it -- the mono variant
  `PJ-603-3` keeps 2/3/4 and drops 5, so 5 is the ring -- and the footprint agrees,
  its pads 3 and 4 sharing y = +2.50 as the switch pair with 5 opposite.
  **`PJ-376` (J2-J5) RESOLVED the same day** from LCSC C22355746's drawing:
  **1 = sleeve, 2 = ring, 3 = tip, and no switch contact** -- its CIRCUIT DIAGRAM
  shows three independent contacts, where `PJ-603` has a fourth riding on the tip.
  The plug drawing numbers the segments 1/2/3 sleeve-to-tip and the PCB layout puts
  pin 1 nearest the barrel; the footprint agrees, pad 1 at x -3.50 on the bushing
  side. **All eight jacks are now wired.**
- ~~**470uF bulk cap** at the OLED rail~~ — **STRUCK 2026-09-08, it was never a
  requirement.** Traced to commit 600efda: the 470uF was `25YXJ470M10X12.5`
  (C88740), the **input bulk cap for the rejected barrel-jack power scheme**
  (12V barrel + B1212S, decided 2026-08-20 and replaced by USB-C + DKM10E-12).
  Nothing to do with the OLED rail, and `design-state` §5.5 no longer exists.
  Current input bulk is `C29`, 22uF/50V. The OLED rail has `C24` 10uF in, `C20`
  10uF + `C21` 100nF out, which is normal for an AMS1117 feeding a 40mA panel.
- ~~**main PCB mounting holes**~~ — **there are none, by decision.** `design-state`
  "Panel mounting" (2026-09-05): the board has no standoffs of its own and hangs off
  the panel hardware. Load path is enclosure -> faceplate -> nuts -> bushings -> part
  bodies -> **solder joints** -> main PCB.
- **Jack panel positions.** J2-J5 and J7-J10 have board positions in
  `free-placement.json` and the counterbore geometry is in `design-state` §11, but
  nothing states where they land on the **enclosure wall**, which is a different part
  from the faceplate.

### The board is located by two different parts at once

With no mounting holes, the main PCB's position is set entirely by parts soldered to
it, and those parts reference **two different things**:

| | clamped to | sets |
|---|---|---|
| 6 pot bushings, nutted | the **faceplate** | height below the panel (10mm) |
| 8 jack barrels, nutted | the **enclosure wall** | position along the top edge |

The faceplate screws to the enclosure at the cheeks, so these are one rigid
assembly rather than two floating parts — which makes this a **tolerance stack, not
a mechanism**. But the board still has to satisfy both references simultaneously,
and it has no compliance: any disagreement is taken up by bending FR4 and loading
the solder joints that `design-state` already names as the load path.

**This shows up at first fit-up, not on screen.** The thing to check on the first
enclosure is whether the wall's jack holes and the faceplate's bushing holes agree
on where the board sits, to better than the boards can flex. If they do not, the
cheap fix is to stop nutting the jacks and let them float in oversized wall
holes — accepting that a hard cable pull then loads solder joints, which is the
trade `design-state` §11 was already weighing for a different reason.

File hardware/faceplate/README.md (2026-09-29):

# Faceplate PCB

4-layer, **ENIG**. Carries the four capacitive scrub pads on L1 and the MSP430FR2675 on
the back. **The front is exposed gold on ground, and every printed mark is black soldermask**
([ADR 0013](../../docs/decisions/0013-gold-face-mask-ink.md)): order black mask, white silk,
ENIG, via covering "Plugged" (JLC's default; they do not offer tented on 4 layers, and POFV
would cap the pads' vias). 5 boards $79.80 on JLC's instant quote, 2026-09-29. Panel geometry comes from `../../mockups/generate-faceplate.py` — see the
handoff below for the size, which is not what older docs say.

## Status — 2026-09-29: placed, routed, gold face (ADR 0013); DRC clean

**Schematic done**, `mksch → netcheck` 145/145 over 41 nets, every block traced to a TI or
manufacturer figure in `design/design.py`. 54 parts: `U1` MSP430FR2675TPT; `C1`/`C2`
10µF + 100nF on DVCC, `C3` 1µF on VREG, `R1`/`C4` 47k + 1nF on RST (SLASEO5D Figures
10-1, 10-4); `R2`/`R3` 47k on P1.4/P1.5 (SLAU550 §3.3.2.1); `Y1` FC-135 + `C5`/`C6` 22pF
(Figure 10-2); the sixteen CapTIvate lines, **one pin from each block per pad**, each
through a TPD1E10B06 to GND on the electrode side and a 470R series resistor (`D11`–`D44`,
`R11`–`R44`, CapTIvate design guide); `E1`–`E4` the pads as symbols (RX0 on pins 1 and 5,
one net); `TP1`–`TP6` SBW and UART pads; `J1`.

**Pad copper is on the board** (2026-09-28): `E1`–`E4` are generated footprints, one via
per bar (763 vias, 37 bridges), from `design/mkpads.py`; ADR 0003, "Connecting the bars".
boardcheck parity is 0 over 145. **Placed and routed** — every piece of copper from a script,
rebuildable from zero ("Layout" below); DRC 0 errors, nothing unconnected; nothing on the top
layer but the pads, nothing under a pad but its own nets.

**`J1` is the hanxia HX JN2.54-2x5P TP H8.9, LCSC C41376028** (chosen 2026-09-28).
It has to be SMD: `J12`'s through-hole C5665 here would put ten pins through the **front
face**, in the 8mm gap between pads 3 and 4. It is Extended: JLC's Basic filter returns no
SMD 2x5 box header at all. Footprint `IDC-SMD_10P-P2.54_C41376028` is from hanxia's
drawing (`datasheets/hanxia-HX-JN2.54-2x5P-TP-H8.9.pdf`): pads 1.02 x 4.65 on 2.54mm,
11.50 overall; body 20.30 x 8.90, **9.60mm seated**, under the 10mm gap. The runner-up,
XFCN BH254VS-10P (C492446), is 10.5mm tall. The drawing marks pin 1 only by a triangle
on the key wall, so the footprint puts pin 1 on the key-side row at that end, as KiCad's
DIN 41651 footprint and `J12` both do. **Pin 1 and the key are settled from both
manufacturer drawings** (2026-09-28, §5).

## The loop

Same tools as the main board, with `--project faceplate` (`../kicad/tools/proj.py`).
From `hardware/kicad/`, with `set -o pipefail` whenever output is piped:

```bash
python3 tools/mksch.py --project faceplate && python3 tools/netcheck.py --project faceplate
python3 tools/boardcheck.py --project faceplate   # board pads vs netmap parity
python3 tools/drc.py --project faceplate          # KiCad's own DRC -- the clearance authority
python3 tools/drc.py --project faceplate --unrouted   # while placed but not routed: the ratsnest is not a failure
python3 tools/panelcheck.py --project faceplate   # outline, holes, OLED window, J1, the cable, pad copper, vias, walls
```

**Pad copper** is regenerated, never hand-edited: change `mockups/generate-faceplate.py`
(its `--check` must pass), then, under KiCad's Python,
`hardware/faceplate/design/mkpads.py` rewrites the four `SCRUB_PAD_216x10_Pn` footprints
and replaces `E1`–`E4` and every via on a `PADp_RXn` net. panelcheck fails if the board's
pads or vias differ from `copper()` by more than 1µm, or if the generator's via keepouts are
not exactly `J1`'s pad rows.

- **Intent** is `design/netmap.json`; **symbols, sheet positions, footprints** are
  `design/design.py`; values `design/values.json`. Never hand-edit the `.kicad_sch`.
  `J1`'s netmap was derived from the main board's `J12`, pin for pin — the ribbon is
  straight through — and `panelcheck` fails if the two ever disagree.
- **`panelcheck`** is this board's `place.py --check`. It derives everything from the
  generator, the placement file, and the main board itself (its `J12` and the Edge.Cuts
  cutout). Parts not placed or not yet sized are **TODO**, not failures; run it with
  `--strict` before plotting a fab package and every TODO fails.
- **Pin cache:** `design/kpins.json` is untracked. Rebuild it, from the repo root, with
  exactly this argument list (stock libraries first, the shared project library last):

  ```bash
  python3 hardware/kicad/tools/ksym.py --project faceplate /Applications/KiCad/KiCad.app/Contents/SharedSupport/symbols/*.kicad_sym hardware/kicad/lib/vuulgaris.kicad_sym
  ```
- **The board** was bootstrapped once by `design/mkboard.py` (KiCad's Python; it refuses
  to overwrite). From here it is edited like the main board's: scripted through pcbnew,
  or by hand in Pcbnew — and after a script writes, **File → Revert** before touching it.
- **Coordinates:** the faceplate board is drawn in panel coordinates, sheet = panel +
  (100, 50) (`panelgeo.FACE_ORG`). Panel y runs from the jack edge.
- The library is **shared** with the main board (`../kicad/lib/`, via this project's
  `sym-lib-table` / `fp-lib-table`). Footprints named `lib:name` in `design.py` come
  from elsewhere; a bare name means `vuulgaris.pretty`.
- DRC ran with one warning while `J1` was KiCad's stock footprint, which does not
  resolve in headless pcbnew. With the real part in the project library it is 0 and 0.
- Every check has been watched failing: a swapped netmap pin (netcheck, panelcheck), a
  track shorting pins 1 and 3 (DRC, boardcheck), `J1` moved 0.5mm or turned 180°, a pot
  hole 0.5mm undersize or 0.3mm off (panelcheck).

## Handoff from the main board — 2026-09-24

The main board is finished: DRC clean, fab package at `../vuulgaris-v1-fab.zip`. What
follows is fixed by it. The faceplate works around these, not the other way round.

### 1. Size: the generator is the source of truth — DONE 2026-09-27, 298.286 x 137.81mm

`generate-faceplate.py` gives **298.286 x 137.81mm**: the 130.81mm composition frame
(`composition_h_mm`, "board + 14" as of 2026-08-26) plus `panel_top_extra_mm` 2.0 and
`panel_bottom_extra_mm` 5.0, both pure extensions. `--check` re-derives with the extras
zeroed and fails if any placement row moves other than y += 2, and asserts the cavity is
1 + 118.81 + 6. Numbers still in circulation that are **superseded**: 130.81, "~285 x 155",
"298 x 154" (`panel-budget.md`). The mockup SVGs are now `mockups/faceplate-v1.svg` and
`faceplate-v1-FAB.svg`; they were `-298x139`, which was never their size.

- **+2mm at the top (jack) edge — DONE 2026-09-27.** Every one of the 24 rows in
  `../placement-panel-facing.txt` moved +2.000 in y and nothing else (compared in integer
  thousandths), `OY` went 7.000 → 9.000 in the same commit, and `place.py --check` reports
  all 24 on their holes with output identical to before; with the old `OY` it reports all
  24 off by 2.0. What the requirement was: The main board's top edge moved out 2mm on
  2026-09-23 so every edge connector ends flush with the wall (`design-state.md`, "Top
  edge extended 2mm"); the board is now 118.81mm. The knobs did not move, so **every
  panel y grows by exactly 2.000 and nothing may re-flow.** The generator centres and
  scales parts of the composition, so do not just raise `panel_h_mm`: add a pure offset,
  regenerate `../placement-panel-facing.txt`, and diff it against the old one — every
  row +2.000 in y, nothing else. In the **same commit** set `OY` in
  `../kicad/tools/place.py` from 7.000 to 9.000 (the comment above `ORG` explains), and
  `place.py --check` must still report all 24 panel parts on their holes. Get this wrong
  and `place.py` moves 24 parts on a routed board.
- **+5mm more at the bottom (back) edge — DECIDED 2026-09-27: yes, 137.81mm.** "Board +
  14" leaves 1mm behind the board, but the board slides in along y and needs 6mm of
  travel to clear the jacks (`design-state.md`, "Assembly": cavity 125.81 = 1 + 118.81 +
  6), so the box is 137.81 outside. A 132.81 panel on that box stops 5mm short of the
  back wall's outer face: its back screws (3mm in) would land over the cavity, and pad 4
  would end 0.36mm from the wall's inner face. The 5mm goes on below pad 4 and **moves no
  coordinates**. The cost is look: the pad block now sits 6.36mm below the divider and
  11.36mm above the bottom edge. Re-centring it would move ENC0 and SW4–SW9, which are
  centred on the pad block, so it stays.

Pads — **RECONCILED 2026-09-27: the generator's geometry, 10mm wide, 8mm gap, 18mm
pitch, 100 teeth.** See "Pad geometry" below and ADR 0003. Both candidates sat on the
same 18mm pitch, so the pad centres (and ENC0, centred on them) come out identical
either way; this was a sensing decision, not a placement one.

### 2. Stack-up: the pots are the datum, and the faceplate is structural

- Faceplate underside **10.0mm** above the main board (the pots' mounting surface),
  **1.6mm** thick, outer face at 11.6mm.
- **Do not go thicker.** The pots (Alpha RD902F) have 3.4mm of M7x0.75 thread above the
  outer face, for a 1.8mm nut plus washer.
- The six pot nuts are the **only** clamp. Encoders (EC12, 0.9mm of bushing through),
  toggles, buttons and the OLED locate but carry nothing. The whole main board hangs off
  the faceplate through those six nuts (`design-state.md`, "Panel mounting").
- **The 10mm gap is shared.** Anything on the faceplate's back (the MSP430, the ESD network,
  LEDs, the connector) sits in the same 10mm as the main board's top-side parts beneath it.
  The tall ones, board coordinates (panel = board + (6.995, 9.000) once §1's offset is in):

  | main-board part | height | board bbox x0,y0 – x1,y1 | faceplate room above |
  |---|---|---|---|
  | `C36`, `C37` electrolytics | 7.8mm | 190–200, 72.8–90.9 | ~2.2mm |
  | `C32`, `C33` electrolytics | 5.4mm | 190–201, 50.1–68.3 | ~4.6mm |
  | `U1` Daisy Patch SM | ~7mm soldered direct (no 3D model) | 243.8–283.9, 47.2–115.4 | ~3mm |
  | `VT301`/`302`/`401`/`402` vactrols | unknown (no 3D model) | 132.6–165.3, 58.0–67.8 and 134.9–167.5, 91.1–100.9 | read the Xvive drawing |

  Everything else on the main board's top is under 3.5mm apart from the panel parts, which
  pass through. Keep faceplate back-side parts low over those areas, or put them elsewhere.
  **The Daisy must be soldered in or on low-profile sockets** — standard 8.5mm sockets put
  it near 13mm and into the faceplate.

### 3. Holes

| part | hole | source |
|---|---|---|
| pots `RV1`–`RV6` | **7.5mm**, centred **0.17mm toward the top edge** of the panel coordinate | M7x0.75, washer ID 7.2 (Alpha drawing); true shaft is (0, −5.00) from the footprint origin, placed at −4.83 — `place.py` |
| buttons `SW4`–`SW9` | **7.2mm** | TS1103S drawing: plunger 6.2 ±0.2 at 14mm height; 0.4 a side at the largest, over the faceplate's ±0.25 float. Generator `mx_cut_d_mm` (the layout keeps `mx_hole_r_mm` = 3.3: changing that re-flows the column). Was 6.6 — 0.1 a side, a sticky button |
| toggles `SW1`/`SW2` | **5.6mm** | Dailywell drawing: 10-48 UNS bushing, 4.83 over the thread. Its 4.95 hole is for a switch hung from the panel by its nut; ours is soldered to the main board too, so the hole takes the bushing's ±0.25 and the faceplate's float. Generator `switch_hole_d_mm` |
| encoders `ENC1`–`ENC8` (EC12E) | **9.5mm** | ALPS EC12E2430803 drawing: body 5.5, then 7mm of M9x0.75 -- the static thread passes the faceplate; M9 + 0.5, the pots' margin |
| encoder `ENC0` (EC11L) | **10.0mm** | ALPS EC11L1525G01 drawing (LE2115L02G): **no thread** -- a 7mm bushing ends 9.5mm up, then a knurled 9.03mm shaft that turns and pushes 1.5mm passes the faceplate. Running clearance |
| OLED `DS1` | **window, 60.09 × 33.90mm**, r 1.0 corners, panel (208.50, 15.15)–(268.59, 49.05) | §4; the generator's `oled_window()` |

**Corners — filleted 2026-09-28, r 6mm** (generator `panel_corner_r_mm`), the wall
thickness. **The enclosure's outer corners take the same radius**; at 6 the cavity keeps
square inside corners, so the main board's outline is untouched. The cost: a panel screw
can no longer sit in the corner — at 3mm in, its head has to clear the arc, so corner
screws go **at least 9mm along the edge** (`panel_screw_corner_min_mm`, checked).

**Panel screws — 2026-09-28:** four M3, 3.4mm clearance holes, one at each corner: on the
long edges 9mm from the corner (x 9.00 / 289.29) and 3mm in (y 3.00 / 134.81), as close as
the r6 corner lets an M3 pan head sit. (Ten, along the edges, until the same day.) Generator
`panel_screws()`; the enclosure's threaded inserts go under them. The mockup draws the
heads; the board does not print them.
panelcheck checks all four corners.

The generator draws **no pot or encoder holes at all** — the r=8 and r=9.2 circles in the FAB
SVG are knob outlines, not cuts. The board's holes are drawn by `design/mkholes.py` from
`panelgeo.holes()`, and the OLED window from `panelgeo.oled_window()` (2026-09-28).
panelcheck `--strict` has no TODO left.

### 4. OLED

The module is **68 x 43mm on its own PCB, 4.2mm tall**, active area 55.01 x 27.49mm. It will
be raised **3–5mm** on a 1x9 socket plus four M3 standoffs in the corner holes already on
the main board. **Nylon standoffs, not metal:** the lower-left hole (297.55, 94.05) has a
`POS12V` trace on F.Cu 2.2mm from its centre, under the standoff's hex base, and a metal
one would put +12V a scratch of soldermask away from the module's mounting hole. The
other three holes have no copper within 3mm on either side. Its face then sits about **2.4–4.4mm** behind the
outer surface; at 5.8mm of lift it hits the faceplate. This answers Q18.

**The window — sized 2026-09-28** by the generator's `oled_window()`, from the HS242L01
drawing (datasheets/, section 1.4: PCB **72** × 43 — the spec table's "68 × 43" is the hole
pitch; AA 55.01 × 27.49 centred along the long axis, **5.11mm below the top edge and 10.4mm
above the bottom**; glass 62.1 × 39.85) and the stack-up. The lift is not chosen, so it is
sized at the **deepest**, 3mm: face 4.4mm below the outer surface.

| | |
|---|---|
| active area, panel | x 211.04–266.05, y 17.16–44.65 |
| window | x 208.50–268.59, y 15.15–49.05 (60.09 × 33.90), r 1.0 |
| AA in view, at 4.4mm deep | 45° from the player's side, 30° from the sides, 25° from the back |
| never nearer the glass edge than | 1.0mm, so past the pixels you see black glass, not the module PCB |

It is lopsided on purpose: the wide black band on the glass, where the flex bonds, is on
the player's side, which is the side that needs the margin. panelcheck checks the drawn
window against the generator, and the generator's module centre against the main board's
four `DS1` holes. **No chamfer:** JLC cannot bevel an internal cutout in FR4; the walls are
straight 1.6mm, and a hand bevel is optional.

### 5. The connector

Main board `J12`: 2x5 2.54mm box header (LCSC C5665), **on the BACK of the main board,
facing down** (moved 2026-09-25), ribbon to the faceplate.

**The route.** The main board has a **24 x 12mm cutout** directly beside `J12`, at board
(210, 97.5)–(234, 109.5) — sheet (310, 147.5)–(334, 159.5) — made for exactly this. The
faceplate's connector sits **over that cutout, facing down**; its ribbon plug hangs through
the hole in the main board, and the ribbon runs underneath to `J12`. That is what makes the
10mm faceplate gap workable: neither mated plug has to fit inside it. So:

- **Put the faceplate header over the cutout, centred on board (222.0, 103.5)** — panel
  (228.995, 112.5) once §1's offset is in. A 2x5 IDC plug is about 20.3 x 9mm; the hole is
  24 x 12, so 1.5–2mm clear per side. Checked 2026-09-26: `J12` is centred on the cutout
  in x (0.00mm), its body 1.44mm from the cutout's edge, nothing sits in the cutout, and
  nothing else is on the main board's back in the ribbon's path.
- **`J12`'s pin 1 is at its +x end (right, viewed from the top), on the row nearest the
  cutout.** Orient the faceplate header so the ribbon takes pin 1 to pin 1 — the two plugs
  sit at different depths, so it is easy to get backwards on paper. Done below.

  **Paper mock-up, 2026-09-28** (both boards read through pcbnew, panel coordinates):

  | | centre | pin 1 | odd row | key (slot) | faces |
  |---|---|---|---|---|---|
  | main `J12` (C5665) | (228.995, 100.5) | +x end | +y | +y wall (footprint silk) | down, from the main board's back |
  | faceplate `J1` (hanxia) | (228.995, 112.5) | +x end | +y | +y wall (hanxia drawing) | down, from the faceplate's back |

  The two headers are the **same orientation**, 12mm apart in y and at different heights;
  the cutout is on `J12`'s +y side, `U7` on its −y side (y 82). So the cable is a plain
  straight 10-way IDC ribbon, both sockets pressed on the **same face**, red stripe at the
  triangle on both. It leaves `J12`'s socket toward +y (the cutout, away from `U7`), sags
  under the main board, and rises into `J1`'s socket from its −y side: no fold, no twist.
  Pin mapping then does not depend on the sockets at all -- each is keyed into an
  identically oriented header, so wire n lands on pin n at both ends, whatever the socket's
  own convention.

  That argument needs both headers to carry the key on the same side of pin 1 -- were
  C5665's on the other wall, a keyed socket would sit 180° round at `J12` and the cable would
  map pin n to 11−n, `P3V3_MSP430` onto `GND`. **Closed from both manufacturer drawings,
  2026-09-28:** hanxia's (`datasheets/hanxia-HX-JN2.54-2x5P-TP-H8.9.pdf`) and BOOMELE's for
  C5665 (`datasheets/BOOMELE-C5665-2x5-box-header.pdf`, from JLC's part page -- LCSC's link
  is dead) both mould the pin-1 triangle on the **keyed wall**, at one end. So the key is on
  the pin-1 row on both parts, which is what both footprints assume (`J12`'s silkscreen,
  `J1`'s Fab notch). C5665's drawing also confirms `J12`'s 1.0mm holes on the 2.54 grid.
  What is left is assembly, not design: use a straight cable, both sockets on the same face,
  red stripe to the triangle. Plugging in the first real cable is still a free sanity check.
- **`U7` (the DKM10, ~10mm tall, on the back) is 1.03mm from `J12`'s far side.** A plug
  sits inside the header's shroud, so it fits; run the ribbon out toward the cutout, not
  toward `U7`.
- **Leave the ribbon slack.** The faceplate end is plugged in with the faceplate lifted and
  then lowered onto the pots, so the cable folds under the main board rather than spanning
  the 12mm between the plugs taut.
- **The case floor needs about 15mm below the main board** around `J12` and the cutout: a
  9.2mm header plus the mated plug and the ribbon's fold.

| pin | net | |
|---|---|---|
| 1 | `MSP_TEST` | |
| 3 | `MSP_RST` | driven by MCP23017 `U4` |
| 5 | `MSP430_RXD` | Daisy A3 (UART4 TX) → MSP430 |
| 7 | `MSP430_TXD` | MSP430 **drives** → Daisy A2 (UART4 RX) |
| 9 | `P3V3_MSP430` | its own AMS1117 (`U6`) on the main board |
| 2,4,6,8,10 | GND | |

The order runs backwards from the original (pin 1 was 3V3) because flipping the header to
the back mirrors it; every net kept its hole and its routing. **Pin 1 is the ribbon's red
stripe** — check it end to end with the faceplate header's orientation before ordering
that board.

**No I2C and no IRQ cross the cable** (`pin-allocation.md`, superseding design-state §9).
There is **no 5V** on it, by decision (ADR 0012).

### 6. MSP430

- UART on UCA0 at its **default** pins (P1.4 TXD / P1.5 RXD, pins 4/5), per
  `pin-allocation.md`. UART and I2C do not share pins (Q2, resolved).
- **Q21 CLOSED 2026-09-27.** SLAU550 §3.1 defers the BSL pins to the device datasheet;
  SLASEO5D Table 9-4 gives the UART BSL as **P1.4 transmit / P1.5 receive**, PT pins 4/5
  (Figure 7-1). The runtime UART and the BSL are the same two wires. The remapped
  P5.1/P5.2 (44/45) fallback is **dropped**: it only ever covered the BSL being elsewhere,
  and `J12` has no free position to carry it.
- **47k pull-ups on P1.4 and P1.5.** They are also TCK/TMS, and SLAU550 §3.3.2.1 warns that
  floating TCK/TMS raise the odds of landing in JTAG mode; the pull-ups also stop RXD
  floating while the Daisy boots. SLAU550's 1nF pull-downs are left off: they target the
  hardware entry sequence, which production never uses (blank-device detection, then
  software invocation).
- Q22: plan the crystal. SBW pads (TEST, RST, 3V3, GND) and test points on TX/RX/RST/TEST.

### 7. LEDs — DECIDED 2026-09-27: none. See ADR 0012.

No LEDs on this faceplate, and no 5V on `J12`. The main board orders as it is. What was on
the table (2026-09-23): one LED per zone, 16 in all, red/amber on 3.3V or white/RGB on a
new 5V pin, driven from the MSP430 through shift registers, lit beside the zones through
small windows and never PWM'd during a touch scan.

## Contents

```
vuulgaris-faceplate.kicad_pro / .kicad_sch / .kicad_pcb
sym-lib-table, fp-lib-table   point at ../kicad/lib, shared with the main board
design/netmap.json            the intent
design/design.py              symbols, sheet positions, footprints (read by mksch.py)
design/values.json            Value fields
design/mkboard.py             the one-shot board bootstrap
design/mkpads.py              pad footprints + E1-E4 + their vias, from the generator's copper()
design/mkplace.py             the one-shot placement of everything else (the table above)
design/mkholes.py             the whole Edge.Cuts layer: outline (r 6 corners), panel holes, screws, OLED window
design/mkbuses.py             the pad buses: every bar's via joined, each net out to the margin (deterministic)
design/mkcells.py             the network grid's cell vias, TVS/R stubs and TVS grounds (deterministic)
design/mkescape.py            J1 out along the pad 3-4 corridor to the test pads, R2, R3 and U1 (deterministic)
design/mkfanin.py             the L2 fan-in: every bus exit to its cell via, crossing-free (deterministic)
design/mkface.py              the front (ADR 0013): the GND gold on F.Cu, the art as black mask, the via patch and dots, the silk
design/mkzones.py             the L3 GND plane: solid, in the margin and the pad 3-4 corridor, never under a pad
design/mkroute.py             everything else, by Freerouting, fenced: no F.Cu, nothing under or between the pads
design/mklib_faceplate.py     the faceplate's own library parts (U1, Y1, the TVS, the pad symbol);
                              the pin table twice (Figure 7-1, Table 7-1), checked equal
DRC.rpt                       from tools/drc.py --project faceplate
fab/                          the fab outputs ("Fab package"); zipped to ../vuulgaris-faceplate-fab.zip
```

The SLAA891 cross-check came back as a connectivity finding, not a geometry one: TI's
elements are single bodies and ours are ratio-encoded islands, so there is no TI pattern to
diff against (ADR 0003, "Connecting the bars").

## Pad geometry

Authoritative spec is [ADR 0003](../../docs/decisions/0003-comb-pad-rx0-wraparound.md).
Summary: 4 channels, 5 segments, 4 zones, order `RX0 RX1 RX2 RX3 RX0`.

**Settled 2026-09-27**, and what `../../mockups/generate-faceplate.py` draws:

| | |
|---|---|
| Pad length | 216mm, independent of the gap (the "12 x pitch" lock was an artefact — Q17) |
| Pad width | **10mm** |
| Gap / pitch | **8mm / 18mm** |
| Teeth | **100** (25 per zone), 2.160mm pitch, 1.950mm wide, 0.21mm apart |
| Top-to-bottom gap | 0.20mm |
| Tooth fillet | 0.6mm, with the bar heights area-compensated so it does not bend the position curve |
| Min copper | 0.15mm enforced; the thinnest bar drawn is 0.197mm |

Why 10/8 rather than the old 12/6: the gap is the untested crosstalk variable (Q17) and
wants to be as wide as the pitch allows; bare copper already gives more signal than TI's
overlay designs, so 12mm buys sensitivity that is not needed at the cost of base
capacitance; and ratio encoding reads a finger that rides high or low across the pad as a
position error (top bars are RX0/RX2, bottom RX1/RX3), which a pad closer to a fingertip's
width keeps smaller. The old "80 teeth at 2.19mm" was the 175mm pad's number; at 216mm, 80
teeth would be 2.70mm.

The copper comes from `generate-faceplate.py`, not `comb-pad-generator.html`, whose
defaults are the superseded 175mm / 12mm pad. Its SVG is true mm scale with one `<g>` per
net.

**Cross-check against TI's own SLAA891 OpenSCAD output before committing copper.**

## Layout — placed and routed 2026-09-28

Settled with Dylan, in order: (a) one open via per bar (ADR 0003, "Connecting the bars");
(b) `U1` and its networks in the **right margin**, not the centre (ADR 0003, layout rules);
(c) the UART, 3V3, RST and TEST from `J1` along the **gap between pads 3 and 4**. Then:
route everything, **nothing on the top layer** (it is the scrub pads and nothing else).

All parts on B.Cu. The margin strip is panel x 277.14 (copper ends) to 292.29 (the wall's
inner face, where the faceplate rests on the wall top — panelcheck fails any back-side part
past it), over the Daisy (~3mm clear; nothing here is over 1.6mm).

| where (panel) | what |
|---|---|
| `U1` (284.45, 104.0) | CAP pins 23–39 face **up**, digital corner (46–5) down-right. Pins 1–5 run right to left along the bottom, 46–48 up the right side |
| the 4 × 4 grid over the CAP pins, rows y 77.15 / 83.15 / 89.15 / 95.15 (6mm apart) | the 16 networks. **Column = CapTIvate block** (RX0–RX3 at x 280.30 / 283.50 / 288.00 / 290.92, each over its own pins: CAP0 = 23–26 … CAP3 = 36–39), **row = pad** (1 at the top). Each cell: its via, the TVS on top of its 470R (pin 1 over pin 1, ground to the right; ADR 0004: the order and a short ground are what count) |
| middle channel, over pin 31 | `C3` 1µF VREG |
| across the corner by pins 1 / 48 | `C2` 100nF |
| right edge, y ~112–116 | `Y1` stood on end, `C5` (XIN) / `C6` (XOUT) beside its two pads |
| above the corridor's mouth, (278.3, 106.2) | `C1` 10µF 3V3 bulk — in the mouth it blocked RST, TXD and RXD in turn |
| under `U1`'s bottom-left | `C4` / `R1` (RST RC), `R3` (RXD pull-up, beside pin 5) |
| the corridor, x 240–262 | `TP1`–`TP6`, each ON its own line, staggered; `R2` (TXD pull-up) across the 3V3 and TXD lines; `TP4` (SBW GND) by `J1`'s GND via |

Pitches come from the silk (R0603's box is 1.47 × 2.93), not the library's small courtyards:
0 silk overlaps. The 31 silk-over-copper warnings are the library's R/C pin-1 dots, clipped
by the mask, as on the main board. The 470Rs' references stand on end beside them; the TVS
and test pad references are on B.Fab.

### How it is routed — rebuildable from zero

Every piece of copper comes from a script, in this order (KiCad's Python, from the repo root):

```bash
KPY=/Applications/KiCad/KiCad.app/Contents/Frameworks/Python.framework/Versions/3.9/bin/python3
$KPY hardware/faceplate/design/mkroute.py --unroute    # every track and via off
$KPY hardware/faceplate/design/mkplace.py --force      # the parts (the table above)
$KPY hardware/faceplate/design/mkholes.py              # Edge.Cuts: outline, holes, screws, OLED window
for s in mkpads mkbuses mkcells mkescape mkfanin mkzones; do $KPY hardware/faceplate/design/$s.py; done
$KPY hardware/faceplate/design/mkroute.py              # the rest, by Freerouting; re-run until DRC is clean
$KPY hardware/faceplate/design/mkface.py               # the front: gold, mask art, silk -- last, it clears the vias
```

**The corridor's right end is Dylan's hand reroute** (2026-09-29), now carried by the scripts.
The TXD and RXD hops and C4's GND via sit under the via patch. `mkescape.py` draws TXD, RXD,
RST and TEST end to end from its `TAIL` table, including the router's old runs past C4,
which the reroute kept, so the router finds those four nets complete. `mkfanin.py` jogs pad
4's RX0 exit to y 117.15.

| script | draws | how |
|---|---|---|
| `mkpads` | the pad copper, one via per bar | the generator's `copper()` |
| `mkbuses` | the buses: every bar's via joined, each net out to the margin | exact, L2 (RX0's join on L3); every via on a segment end |
| `mkcells` | each cell's via and B.Cu down to TVS pin 1 and R pin 1; each TVS's GND via; `C3`'s ground | exact; the vias staggered in height (below) |
| `mkescape` | `J1`'s escape, the corridor, its taps; RXD and TXD's hops to `U1`; `J1`'s GND | exact, B.Cu (hops on L2) |
| `mkfanin` | all 16 electrode lines, bus exit to cell via | exact, L2 |
| `mkzones` | the L3 GND plane: **solid**, margin + corridor, never under a pad | exact |
| `mkroute` | everything else: the B.Cu fan-out into `U1`, power, the last grounds, crystal | Freerouting, fenced (the gold is dropped from its DSN); then prunes dangling copper and stitches any GND pad with no path to the plane |
| `mkface` | the front: one GND zone on F.Cu less each pad's 2mm frame; F.Mask openings = the gold less the mask block (frames + via patch as one filleted outline), a dot over every other via outside the pads, and every art stroke; the right-hand numerals in silk on the patch | the generator's `face()`, `mask_block()`, `scale_marks()`, `panel_art()` (ADR 0013) |

**The electrode fan-in (`mkfanin`).** Each pad's lines leave its bus as RX0, RX2, RX1, RX3
(top to bottom) but the columns run RX0, RX1, RX2, RX3. Each cell's via sits at its own height
in the cell band, 0.5 apart, in the order the lines arrive, so each line runs level to its own
column and passes the others' vias at ≥ 0.5 — never another line. Pads 1–3 come in from the
strip left of the grid (column 0's via steps 0.4 right to open a fourth slot); pad 4's would
jam it, so they run under the corner group, up a strip at the right edge, and in from the
right, its via order reversed.

**The corridor (`mkescape`).** `J1`'s inner four signals climb into the 2.2mm channel between
its rows in pin order; past `J1` all five fan out to 1.3mm (RXD straight, the rest diverging
from it — fanned about a common point, the lines' corners came 0.197 apart) and run to the
margin. `J1`'s pins read TEST, RST, RXD, TXD, 3V3 but `U1`'s read DVCC, RST, TEST, TXD, RXD,
so RXD and TXD hop on L2 under the `C4`/`R1` group, TXD's under RXD's.

**The router's fences (`mkroute`).** F.Cu and In2.Cu are declared power layers, so it lays no
trace on either (a keepout over F.Cu also banned every via); no copper left of the margin
but the corridor, and there B.Cu only; everything already drawn locked; the buses handed over
only as a stub at each exit (it merges collinear locked segments and loses the vias between).
Its results vary run to run: re-run it (it is incremental -- what is routed stays) until DRC
shows nothing unconnected. With everything above scripted, the last rebuilds closed on the
first pass.

**Grounds.** Each TVS's ground pin gets a via beside it at its own height, where L2 is clear
of the fan-in lanes; in row 4 column 2 it goes up into the gap between rows 3 and 4, and
`C3` ties to column 1's. The router grounds the last few (row 4, columns 0 and 3; `C1`...),
and `mkroute` then stitches any GND pad still without a path to the plane: the nearest
spot where a via and a straight stub clear every other net (pcbnew's own shapes), never in
a pad. **The plane is solid**, not hatched: a via in a hatch hole touches nothing, and the
router takes the plane for solid; L2 is ~1.1mm above L3, so solid adds under 1pF to a
fan-in line.

**Netclass `CapTIvate`** (`/PAD*`, `/CAP*`): 0.15mm track, 0.15mm clearance (0.2 to anything
in GND or Default), vias 0.5 / 0.3 — TI wants sensor traces thin anyway. GND and Power 0.3mm,
all other vias 0.6 / 0.3: every net fits `U1`'s 0.5mm pitch.

panelcheck proves the fences held: nothing routed on F.Cu, and nothing — track, via or zone —
under a pad but that pad's own nets.

## Pin order is load-bearing

`RX0->E00, RX1->E01, RX2->E02, RX3->E03`. Generate the assignment in Design Center **first**,
then lay out to match. A swapped pair produces garbage interpolation on a board that passes
every electrical check.

## Per-electrode ESD network

4 CapTIvate lines x 4 pads = **16 of each** (settled 2026-09-28; was 20, see ADR 0004):
- RX0's two end groups join on the electrode side, first
- TPD1E10B06 TVS between that electrode net and ground
- 470R-1k series resistor from there to the CapTIvate pin

Place near the MCU with a low-impedance ground path.

Each pad takes **one pin from each CapTIvate block** (`RXn` of pad `p` to `CAPn.(p-1)`), not
one block; `../../docs/pin-allocation.md` has the table and TI's source.
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

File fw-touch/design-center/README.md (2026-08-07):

# CapTIvate Design Center project

Design Center **1.83.00.08 (May 2020)**. Its release notes say to re-create projects made in
earlier versions, so do not carry one forward from an older install.

## Device targeting

Design Center projects target a **specific device**. When moving from the FR2676 eval board
to our own FR2675 board, **regenerate for FR2675 (PT/LQFP-48)**. CAP pin *naming* carries
over; physical pins do not.

## Sensor definition

Four sliders. Each: **4 electrodes**, order `E00 E01 E02 E03` mapped to `RX0 RX1 RX2 RX3`.
Geometry is 5 segments / 4 interpolation zones with **RX0 at both ends as a single net**.

Put each slider's four elements in **one measurement block** so they are measured in
parallel. The part has four blocks, which is exactly one per slider.

## Workflow

1. Define sensors here.
2. **Generate.** Output lands in `../captivate/generated/`.
3. Note the electrode-to-pin assignment. **The PCB is laid out to match this**, not the
   reverse.
4. Connect the CAPTIVATE-PGMR to the target board and open the live data view.
5. Tune against **real hardware in the real enclosure next to the real switching supply.**
   Anything else is not tuning.
6. Log results in `../tuning/`.

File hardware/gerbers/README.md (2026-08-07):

# Gerbers

One dated subfolder per fab order, so an order can always be reproduced exactly:

```
2026-08-05-faceplate-test-pad-v1/
  gerbers.zip
  bom.csv
  cpl.csv
  ORDER.md      fab, options chosen, price, lead time, what changed since last time
```

Never overwrite a folder that has been ordered. Make a new one.

## Standing fab options

| Option | Value | Why |
|---|---|---|
| Surface finish | **ENIG** | HASL feels wrong under a sliding finger and will not wear. Non-negotiable on the faceplate. |
| Layers | 4 (faceplate) | L1 electrodes / L2 traces / L3 hatched ground / L4 components |
| Min trace/space | 0.15mm enforced | Pad generator checks against this. Sub-0.127mm copper etches away. |

Flag on any order containing the microSD socket: **JLC needs an assembly fixture** to
support it during placement.

## First thing to order

Not the faceplate. **One cheap 2-layer board with two pads in final tooth geometry, ~216mm**,
roughly $50 and 2 weeks. Measures monotonicity, continuity and repeatability before the
faceplate exists, and the second pad answers the inter-pad gap question that gates the panel.
See [next-steps.md](../../docs/notes/next-steps.md) step 0.

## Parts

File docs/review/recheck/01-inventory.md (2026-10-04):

# 01: Inventory and chain integrity

Recheck of 2026-10-02, section 1 of `docs/notes/recheck-prompts.md`. Report only:
nothing in netmap, values, design.py, the KiCad files or the fab packages was touched.

## Method

No KiCad in this container, so the repo's own checkers (`netcheck.py`,
`boardcheck.py`) were not run. Instead, a fresh reader was written outside the
repo (scratch dir, never committed) that parses the files directly:

- **Schematic.** Reads the embedded `lib_symbols` for every pin's number, name,
  type and position per unit, applies each instance's position, rotation and
  mirror, then joins wire endpoints, labels (same name = same net) and
  `no_connect` markers by coordinate. Self-test: every one of the 944 wire
  endpoints on the main sheet and 145 on the faceplate sheet lands exactly on a
  pin or a label, every `no_connect` sits on a pin, and no point lies in the
  middle of a wire (there are no junctions to honour). A wrong transform would
  have left endpoints hanging, so the geometry is proven, not assumed.
- **Board.** Reads every footprint's pads with their net, converts pad
  positions to board coordinates. Self-test: 982 track ends fall on a pad
  centre and all 982 carry that pad's net.
- **Pin-name layer.** `tools/kpins.json` is absent, as expected. The pin
  number to pin name map was rebuilt from the schematic's own `lib_symbols`.

## Result: the gate holds, but the number it was gated on is stale

| check | main board | faceplate |
|---|---|---|
| netmap refs / connections / nets | 316 / **944** / 223 | 54 / 145 / 41 |
| netmap vs schematic, both directions | 944 / 944, 0 extra | 145 / 145, 0 extra |
| netmap vs board pad nets, both directions | 944 / 944, 0 extra | 145 / 145, 0 extra |
| schematic pins with `no_connect` | 63 | 23 |
| board pads outside netmap | 66 = the 63 NC pins + 3 unnumbered mechanical pads | 23 = the 23 NC pins |
| refs on board vs netmap | identical sets, no duplicates | identical sets |

The runbook, `review-packet.md`, `REVIEW-INDEX.md` and `tools/blockview.py`
expect **942 connections, 309 refs, 219 nets**. That figure is from
`87e5df6` (2026-09-10). netmap history since:

| commit | date | refs / conns / nets | change |
|---|---|---|---|
| `87e5df6` | 09-10 | 309 / 942 / 219 | D3 TVS added (the quoted figure) |
| `30da82a` | 09-16 | 309 / 942 / 221 | LPG LED drive fix |
| `b6f0c0a` | 09-18 | 310 / 944 / 221 | C29 to ceramic, 100nF added at the connector |
| `cf63396` | 09-22 | 310 / 932 / 221 | SW4-SW9 un-shorted, one diagonal per switch net-less |
| `9aa2c7b` | 09-25 | 316 / 944 / 223 | ADR 0011 EXT feed into the LPG |

So 944 is the right number for today's intent, and an independent parse
reproduces it three ways with zero disagreement. The gate is treated as passed.

## Inventory

Every fitted ref with its BOM line. TP1-TP15 (main) and TP1-TP6, E1-E4
(faceplate) are bare copper and correctly absent from both BOMs. BOM ref sets
equal netmap ref sets minus those.

### Main board

| refs | part (BOM comment) | LCSC | footprint | datasheet |
|---|---|---|---|---|
| R20, R21 | 0402WGF2201TCE | C25879 | R0402 | none: fine (R/C) |
| R104, R204 | 0R  (IN GAIN -- OPEN, see docs/bbd-mki.md) | C21189 | R0603 | none: fine (R/C) |
| R106, R115, R116, R117, R122, R124, R125, R128, R130, R206, R215, R216, R217, R222, R224, R225, R228, R230, R305, R309, R310, R317, R318, R320, R323, R328, R330, R331, R333, R405, R409, R410, R417, R418, R420, R423, R428, R430, R431, R433, R509, R510, R519, R520 | 100k | C25803 | R0603 | none: fine (R/C) |
| C31, C34, C35, C38, C39, C40, C41, C43, C105, C106, C107, C108, C109, C111, C121, C122, C205, C206, C207, C208, C209, C211, C221, C222, C301, C302, C303, C304, C401, C402, C403, C404, C507, C508, C509, C510 | 100nF / CC0603JRX7R8BB104 | C14663 | C0603 | none: fine (R/C) |
| R118, R126, R218, R226, R301, R302, R308, R314, R401, R402, R408, R414, R505 | 10k | C25804 | R0603 | none: fine (R/C) |
| C119, C219 | 10nF C0G 0805 | C237168 | C0805 | none: fine (R/C) |
| C20, C22, C24, C25, C29, C42, C110, C210 | 10uF / CL21A106KAYNNNE | C15850 | C0805 | none: fine (R/C) |
| SW4, SW5, SW6, SW7, SW8, SW9 | 12x12 tactile | C54573007 | KEY-TH_4P-L12.0-W12.0-P5.00-LS12.5 | `TS1103S-12x12-tactile.pdf` |
| R303, R403 | 150k | C22807 | R0603 | none: fine (R/C) |
| R311, R312, R411, R412 | 15k | C22809 | R0603 | none: fine (R/C) |
| R501, R502 | 1M | C22935 | R0603 | none: fine (R/C) |
| D103, D104, D105, D106, D107, D203, D204, D205, D206, D207 | 1N4148W | C81598 | SOD-123_L2.8-W1.8-LS3.7-RD | `1N4148W.pdf` |
| R107, R207, R315, R415, R503, R504, R514, R516, R517, R518 | 1k | C21190 | R0603 | none: fine (R/C) |
| R513, R515 | 1k2 | C22765 | R0603 | none: fine (R/C) |
| C114, C214, C309, C409 | 1nF C0G | C163508 | C0603 | none: fine (R/C) |
| C30, C113, C120, C213, C220, C306, C406, C501, C502, C503, C504, C505, C506, C511, C512 | 1uF X7R 50V / CC0805KKX7R9BB105 | C28323 | C0805 | none: fine (R/C) |
| R121, R221 | 2.2M | C22938 | R0603 | none: fine (R/C) |
| RT301, RT401, RT501, RT502, RT503, RT504 | 20k trim | C55071 | RES-ADJ-SMD_3224W | `Bourns-3224W-trimmer.pdf` |
| C116, C216, C307, C407 | 220pF C0G | C27675 | C0603 | none: fine (R/C) |
| R110, R111, R129, R210, R211, R229 | 22k | C31850 | R0603 | none: fine (R/C) |
| C310, C410 | 22pF C0G | C1653 | C0603 | none: fine (R/C) |
| R521, R522 | 2k2 | C4190 | R0603 | none: fine (R/C) |
| C305, C405 | 2nF C0G | C296055 | C0603 | none: fine (R/C) |
| R307, R407 | 33k | C4216 | R0603 | none: fine (R/C) |
| R123, R223 | 39k | C23153 | R0603 | none: fine (R/C) |
| D301, D401 | 3V9 zener | C213113 | SOD-123_L2.7-W1.6-LS3.7-RD-1 | `BZT52C3V9-zener.pdf` |
| R119, R219 | 4.7k | C23162 | R0603 | none: fine (R/C) |
| C308, C408 | 4.7nF C0G | C576818 | C0603 | none: fine (R/C) |
| R131, R132, R231, R232, R306, R406 | 470R | C23179 | R0603 | none: fine (R/C) |
| R304, R404 | 470k | C23178 | R0603 | none: fine (R/C) |
| R113, R213, R506, R507, R508 | 47k | C25819 | R0603 | none: fine (R/C) |
| R313, R413 | 4M7 | C23163 | R0603 | none: fine (R/C) |
| R511, R512 | 4R7 | C23164 | R0603 | none: fine (R/C) |
| R114, R214 | 51k | C23196 | R0603 | none: fine (R/C) |
| R127, R227 | 6.2k | C4260 | R0603 | none: fine (R/C) |
| R120, R220 | 62k | C23221 | R0603 | none: fine (R/C) |
| R112, R212 | 82k | C23254 | R0603 | none: fine (R/C) |
| U5, U6 | AMS1117-3.3 | C6186 | SOT-223-3_L6.5-W3.4-P2.30-LS7.0-BR | `AMS1117-datasheet.pdf` |
| U8 | AMS1117-5.0 | C6187 | SOT-223-3_L6.5-W3.4-P2.30-LS7.0-BR | `AMS1117-datasheet.pdf` |
| F1 | ASMD1812-300 | C135366 | F1812 | none: GAP for section 2: PTC, no pin semantics, but hold/trip numbers needed and no sheet in repo |
| FB1, FB2 | BEAD0805S601A20T | C1017 | R0805 | none: fine (2-pin bead, no polarity) |
| L1, L2 | BLM18PG121SN1D_C14709 | C14709 | L0603 | none: fine (2-pin bead) |
| C28 | CC0603JRNPO9BN103 | C57112 | C0603 | none: fine (R/C) |
| U104, U204 | CD4046B | C2651237 | SO-16_L10.3-W5.3-P1.27-LS7.8-BL | `TI-CD4046B-datasheet.pdf` |
| C21, C23, C26, C27 | CL05B104KO5NNNC | C1525 | C0402 | none: fine (R/C) |
| RV1, RV2, RV3, RV4, RV6 | CUTOFF / FILTER CV AMT / RESONANCE / TIME / WET/DRY | (blank, hand-fit) | RES-ADJ-TH_RK09L1240A12 | `Alpha-RD902F-40-15R1-dual-9mm-pot.pdf` |
| U7 | DKM10E-12 | C6934792 | PWRM-TH_DKMW30F-12 | `MeanWell-SKM10-DKM10-spec.pdf` |
| ENC0 | EC11L1525G01 | C2991196 | SW-TH_ALPS_EC11L1525G01 | `ALPS-EC11L1525G01.pdf` |
| ENC1, ENC2, ENC3, ENC4, ENC5, ENC6, ENC7, ENC8 | EC12E2430803 | C470684 | SW-TH_EC12EXXXX | `ALPS-EC12E2430803.pdf` |
| U1 | ES_DAISY_PATCH_SM_REV1 | (blank, hand-fit) | DAISY_PATCH_SM | `Electrosmith-Patch-SM-v1.0.5.pdf` |
| J12 | FACEPLATE 2x5 IDC | C5665 | IDC-TH_10P-P2.54_C5665 | `BOOMELE-C5665-2x5-box-header.pdf` |
| RV5 | FEEDBACK | (blank, hand-fit) | RES-ADJ-TH_RK09L1240A12 | `Alpha-RD902F-40-15R1-dual-9mm-pot.pdf` |
| DS1 | HS242L01W4S01 | C5139768 | LCD-TH_HS242L01W4S01 | `HS242L01W4S01-OLED.pdf` |
| Q1, Q2 | J113 / MMBFJ113 | C891686 | SOT-23-3_L2.9-W1.3-P1.90-LS2.4-BR | `onsemi-MMBFJ113-datasheet.pdf` |
| U3, U4 | MCP23017-E_SO | C47023 | SOIC-28_L18.0-W7.5-P1.27-LS10.3-BL | `Microchip-MCP23017-datasheet.pdf` |
| U9, U10 | OPA1688_FLAT | C206212 | SOP-8_L4.9-W3.9-P1.27-LS6.0-BL | `TI-OPA1688-datasheet.pdf` |
| J2, J3, J4, J5, J6 | PJ-376 | C22355746 | AUDIO-TH_PJ-376 | `PJ-376-jack.pdf` |
| J7, J8, J9, J10 | PJ-603_C41409498 | C41409498 | AUDIO-TH_PJ-603 | `PJ-603-jack.pdf` |
| R24, R25 | RT0603BRD072K2L | C861295 | R0603 | none: fine (R/C) |
| R22, R23 | RT0603BRD075K1L | C122969 | R0603 | none: fine (R/C) |
| C32, C33 | RVT1E470M0505_C2977553 | C2977553 | CAP-SMD_BD5.0-L5.3-W5.3-LS6.3-FD | `Lelon-RVT-electrolytic.pdf` |
| C36, C37 | RVT1H220M0605 | C72505 | CAP-SMD_BD6.3-L6.6-W6.6-FD | `Lelon-RVT-electrolytic.pdf` |
| D3 | SMAJ6.0A | C223993 | SMA_L4.3-W2.6-LS5.2-RD | `SMAJ6.0A-TVS.pdf` |
| SW1, SW2 | SW_DPDT_FLAT | (blank, hand-fit) | SW-TH_DW3_DPDT_2MD1T1B1M2QES | `Dailywell-2MD1T1B1M2QES-DPDT.pdf` |
| J1 | TFPUSH | C393941 | TF-SMD_TF-PUSH | `TF-PUSH-microSD.pdf` |
| U102, U103, U106, U202, U203, U206 | TL072_FLAT | C67473 | SOIC-8_L4.9-W3.9-P1.27-LS6.1-BL | `TI-TL072-datasheet.pdf` |
| U302, U402 | TL074 | C12594 | SOIC-14_3.9x8.7mm_P1.27mm | `TI-TL074-datasheet.pdf` |
| U301, U401 | TL084 | C8956 | SOIC-14_3.9x8.7mm_P1.27mm | `TI-TL084-datasheet.pdf` |
| J11 | TYPE-C-31-M-12 | C165948 | USB-C_SMD-TYPE-C-31-M-12_1 | `Korean-Hroparts-TYPE-C-31-M-12.pdf` |
| U101, U201 | V3205SD | (blank, hand-fit) | DIP-8_SPECIAL_V3205SD | `Panasonic-MN3205-datasheet.pdf` (+ BBD manual p25) |
| VT301, VT302, VT401, VT402 | VTL5C3 | (blank, hand-fit) | VACTROL-TH_VTL5C3 | `Xvive-VTL5C3-datasheet.pdf` |
| D1, D2 | YLED0402Y | C20608782 | LED0402-R-RD | `YLED0402Y.pdf` |

### Faceplate

| refs | part (BOM comment) | LCSC | footprint | datasheet |
|---|---|---|---|---|
| C2 | 100nF | C14663 | C0603 | none: fine (R/C) |
| C1 | 10uF | C15850 | C0805 | none: fine (R/C) |
| C4 | 1nF C0G | C163508 | C0603 | none: fine (R/C) |
| C3 | 1uF | C28323 | C0805 | none: fine (R/C) |
| C5, C6 | 22pF C0G | C1653 | C0603 | none: fine (R/C) |
| Y1 | 32.768kHz FC-135 12.5pF | C32346 | XTAL-SMD_FC-135_3.2x1.5mm | `Epson-FC-135-32.768kHz.pdf` |
| R11, R12, R13, R14, R21, R22, R23, R24, R31, R32, R33, R34, R41, R42, R43, R44 | 470 | C23179 | R0603 | none: fine (R/C) |
| R1, R2, R3 | 47k | C25819 | R0603 | none: fine (R/C) |
| J1 | HX JN2.54-2x5P TP H8.9 | C41376028 | IDC-SMD_10P-P2.54_C41376028 | `hanxia-HX-JN2.54-2x5P-TP-H8.9.pdf` |
| U1 | MSP430FR2675TPT | C2052972 | LQFP-48_7x7mm_P0.5mm_PT0048A | `TI-MSP430FR2675-datasheet.pdf` |
| D11, D12, D13, D14, D21, D22, D23, D24, D31, D32, D33, D34, D41, D42, D43, D44 | TPD1E10B06DPYR | C48260 | X1SON-2_DPY0002A | `TI-TPD1E10B06-datasheet.pdf` |

**Refs with no datasheet:**

- R, C, FB1/FB2, L1/L2: fine, no pin semantics.
- **F1 (ASMD1812-300): gap.** No pin semantics, so no wiring risk, but section 2
  needs its hold and trip current and there is no sheet in the repo.
- **MCP23017: revision gap.** The committed sheet is **DS20001952C (July 2016)**,
  whose Table 2-1 calls GPA7 and GPB7 "Bidirectional I/O". The runbook itself
  refers to an output-only caveat on GPA7/GPB7 "in the current datasheet
  revision"; that revision is not in the repo. Three inputs sit on those pins
  (section 4 takes this up). **Closed 2026-10-04:** the committed sheet is now
  DS20001952E (July 2026), which says output only for both.
- CoolAudio V3205SD: never obtained, known; MN3205 original plus manual p25.

**Doc drift found here:** `REVIEW-INDEX.md` maps `C29` to the Lelon RVT
electrolytic (it is a 10uF 0805 MLCC, CL21A106KAYNNNE, since `b6f0c0a`) and `RV1`-`RV6`
to the ALPS RK09L sheet (the fitted part is the Alpha RD902F; the RK09L sheet
now only documents the footprint's origin). The BOM footprint name
`PWRM-TH_DKMW30F-12` on U7 names a different Mean Well module (DKMW30F); a
footprint name is not evidence either way, so section 8 checks the pads.

## Pins whose name implies a function

Every symbol pin named as a supply, ground, reset or control pin, both boards,
against the net it sits on. "CLEAN" here means name and net agree; whether the
**name** is right for that pin number is each block's datasheet check.

| board | ref.pin | pin name | net | name implies | verdict |
|---|---|---|---|---|---|
| main | DS1.1 | GND | GND | GND | CLEAN |
| main | DS1.2 | VCC | P3V3_OLED | +supply | CLEAN |
| main | ENC0.6 | EH | GND | GND | CLEAN |
| main | ENC0.7 | EH | GND | GND | CLEAN |
| main | J1.4 | VDD | P3V3_DAISY | +supply | CLEAN |
| main | J1.6 | VSS | GND | GND | CLEAN |
| main | J11.1 | EH | GND | GND | CLEAN |
| main | J11.2 | EH | GND | GND | CLEAN |
| main | J11.3 | EH | GND | GND | CLEAN |
| main | J11.4 | EH | GND | GND | CLEAN |
| main | J11.A1B12 | GND | GND | GND | CLEAN |
| main | J11.A4B9 | VBUS | VBUS | +supply | CLEAN |
| main | J11.B1A12 | GND | GND | GND | CLEAN |
| main | J11.B4A9 | VBUS | VBUS | +supply | CLEAN |
| main | U1.A1 | -12V | NEG12V | -supply | CLEAN |
| main | U1.A10 | +3V3 | P3V3_DAISY | +supply | CLEAN |
| main | U1.A4 | GND | GND | GND | CLEAN |
| main | U1.A5 | +12V | POS12V | +supply | CLEAN |
| main | U1.A6 | +5V | P5V | +supply | CLEAN |
| main | U1.A7 | GND | GND | GND | CLEAN |
| main | U10.4 | V- | NEG12V | -supply | CLEAN |
| main | U10.8 | V+ | POS12V | +supply | CLEAN |
| main | U101.1 | GND | GND | GND | CLEAN |
| main | U101.5 | VDD | P5V_BBD | +supply | CLEAN |
| main | U102.4 | V- | NEG12V | -supply | CLEAN |
| main | U102.8 | V+ | POS12V | +supply | CLEAN |
| main | U103.4 | V- | NEG12V | -supply | CLEAN |
| main | U103.8 | V+ | POS12V | +supply | CLEAN |
| main | U104.16 | VDD | P5V_BBD | +supply | CLEAN |
| main | U104.8 | VSS | GND | GND | CLEAN |
| main | U106.4 | V- | NEG12V | -supply | CLEAN |
| main | U106.8 | V+ | POS12V | +supply | CLEAN |
| main | U201.1 | GND | GND | GND | CLEAN |
| main | U201.5 | VDD | P5V_BBD | +supply | CLEAN |
| main | U202.4 | V- | NEG12V | -supply | CLEAN |
| main | U202.8 | V+ | POS12V | +supply | CLEAN |
| main | U203.4 | V- | NEG12V | -supply | CLEAN |
| main | U203.8 | V+ | POS12V | +supply | CLEAN |
| main | U204.16 | VDD | P5V_BBD | +supply | CLEAN |
| main | U204.8 | VSS | GND | GND | CLEAN |
| main | U206.4 | V- | NEG12V | -supply | CLEAN |
| main | U206.8 | V+ | POS12V | +supply | CLEAN |
| main | U3.10 | VSS | GND | GND | CLEAN |
| main | U3.18 | ~{RESET} | P3V3_DAISY | reset (pulled/driven) | CHECK |
| main | U3.9 | VDD | P3V3_DAISY | +supply | CLEAN |
| main | U301.11 | V- | NEG12V | -supply | CLEAN |
| main | U301.4 | V+ | POS12V | +supply | CLEAN |
| main | U302.11 | V- | NEG12V | -supply | CLEAN |
| main | U302.4 | V+ | POS12V | +supply | CLEAN |
| main | U4.10 | VSS | GND | GND | CLEAN |
| main | U4.18 | ~{RESET} | P3V3_DAISY | reset (pulled/driven) | CHECK |
| main | U4.9 | VDD | P3V3_DAISY | +supply | CLEAN |
| main | U401.11 | V- | NEG12V | -supply | CLEAN |
| main | U401.4 | V+ | POS12V | +supply | CLEAN |
| main | U402.11 | V- | NEG12V | -supply | CLEAN |
| main | U402.4 | V+ | POS12V | +supply | CLEAN |
| main | U5.1 | GND | GND | GND | CLEAN |
| main | U5.2 | VOUT | P3V3_OLED | +supply (driven) | CLEAN |
| main | U5.3 | VIN | P5V_OLED | +supply | CLEAN |
| main | U5.4 | VOUT | P3V3_OLED | +supply (driven) | CLEAN |
| main | U6.1 | GND | GND | GND | CLEAN |
| main | U6.2 | VOUT | P3V3_MSP430 | +supply (driven) | CLEAN |
| main | U6.3 | VIN | P5V_MSP | +supply | CLEAN |
| main | U6.4 | VOUT | P3V3_MSP430 | +supply (driven) | CLEAN |
| main | U7.1 | +Vin | VBUS_F | +supply | CLEAN |
| main | U7.2 | -Vin | GND | GND | CLEAN |
| main | U7.3 | +Vout | POS12V_RAW | +supply (driven) | CLEAN |
| main | U7.4 | Common | GND | GND | CLEAN |
| main | U7.5 | -Vout | NEG12V_RAW | -supply | CLEAN |
| main | U7.6 | R.C. | None | control | CHECK |
| main | U8.1 | GND | GND | GND | CLEAN |
| main | U8.2 | VOUT | P5V_BBD | +supply (driven) | CLEAN |
| main | U8.3 | VIN | POS12V | +supply | CLEAN |
| main | U8.4 | VOUT | P5V_BBD | +supply (driven) | CLEAN |
| main | U9.4 | V- | NEG12V | -supply | CLEAN |
| main | U9.8 | V+ | POS12V | +supply | CLEAN |
| face | U1.1 | DVCC | P3V3_MSP430 | +supply | CLEAN |
| face | U1.2 | ~{RST}/NMI/SBWTDIO | MSP_RST | reset (pulled/driven) | CHECK |
| face | U1.3 | TEST/SBWTCK | MSP_TEST | control | CHECK |
| face | U1.48 | DVSS | GND | GND | CLEAN |

The five `CHECK` rows, resolved:

- `U3.18`, `U4.18` `~RESET` on `P3V3_DAISY`: DS20001952C Table 2-1, RESET
  "Hardware reset. Must be externally biased." Held inactive-high. CLEAN.
- `U7.6` R.C. open: section 2 reads the Mean Well spec.
- Faceplate `U1.2` RST/NMI and `U1.3` TEST: section 10 (Table 7-4 of SLASEO5D
  wants RST/NMI pulled up with a 47k and 1.1nF-to-10nF; TEST may be left open,
  it has an internal pulldown).

No supply pin on a signal net, no ground pin on a supply, and no net with two
pins named as outputs (op-amp `OUT`, regulator `VOUT` excepted as one source).

## Single-pin nets and unconnected pins

### Single-pin nets (main board 3, faceplate 0)

| net | pin | justification | verdict |
|---|---|---|---|
| `MSP_TEST` | `J12.1` | ADR 0005 (superseded 2026-09-06): blank FR26xx devices enter BSL without the TEST/RST sequence (SLAU550 3.3.3 quoted there), so nothing on the main board drives TEST. The pin exists for the CAPTIVATE-PGMR / SBW path with the ribbon pulled (ADR 0005, 2026-09-28 revision). The faceplate side has TEST's internal pulldown. | CLEAN, by decision; section 9 checks the BSL claim against SLAU550 |
| `BBD_WETOUT_L` | `R132.2` | `bbd-mki.md` XS4, closed 2026-09-08: R132 taps `BBD_WETAC` in parallel with R131 and ends on nothing. A 470R with one end open draws no current and loads nothing. | CLEAN, by decision (a part that does nothing, costs one placement) |
| `BBD_WETOUT_R` | `R232.2` | as above | CLEAN, by decision |

### Unconnected pins, main board (63 `no_connect` + 3 unnumbered pads)

| ref.pin | name | may it float? source | verdict |
|---|---|---|---|
| `U1.A8` | USB_DM (PB14) | Patch SM Table 2: plain GPIO. A floating STM32 pin left in its reset state is harmless. | CLEAN |
| `U1.B9` | GATE_IN_2 | Table 2 "Input Only", Fig 1.4: 100k input network on the module. | CLEAN |
| `U1.C2`-`C8` | CV_1..CV_7 | Table 2 "Input Only", Fig 1.3: 100k input impedance on the module, biased there. | CLEAN |
| `U1.D3`, `U1.D4` | SDMMC1_D2, D1 (PC10, PC9) | GPIO; D3 carries a module 47k pullup (Table 2 footnote), D4 does not. Unused in 1-bit SD. | CLEAN |
| `U1.D8` | ADC_12 / SPI2_MISO | GPIO; display is write-only. | CLEAN |
| `U3.11`, `U3.14`, `U4.11`, `U4.14` | NC | DS20001952C Table 2-1: NC on MCP23017. | CLEAN |
| `U3.19`/`20`, `U4.19`/`20` | INTB, INTA | outputs (Table 2-1). Float allowed. Consequence: no interrupt, the Daisy must poll; section 4. | CLEAN |
| `U4.5`-`8`, `U4.23`, `U4.24` | GPB4-GPB7, GPA2, GPA3 | inputs at power-on (IODIR resets to all-input) with no external bias. Rev C gives no unused-pin rule. A floating CMOS input is legal but can draw shoot-through current; firmware should enable GPPU or set them as outputs. fw-daisy is a skeleton with no MCP23017 code yet. | QUESTION (firmware requirement) |
| `DS1.8` | FS0 | font-ROM data output (module sheet, ADR 0006). | CLEAN |
| `J1.1`, `J1.8` | DAT2, DAT1 | unused in 1-bit mode. No host pullup on either. Patch SM Fig 1.7 says "No pullup resistors necessary" but that refers to its own SDMMC pins, and DAT2/DAT1 are not connected to the module at all here. The SD Physical Layer spec (not in repo) is the authority on floating card DAT lines. | QUESTION, section 4 |
| `J1.CD` | card detect | switch contact, unused. | CLEAN |
| `J11.A6`/`A7`/`B6`/`B7` | D+/D- | power-only sink, ADR 0010. | CLEAN |
| `J11.A8`, `J11.B8` | SBU1/2 | unused sideband, power-only sink. | CLEAN |
| `SW1.3`, `SW1.6` | A_NO, B_NO | VCF switch uses one throw; open throw is the off position. Section 5/6. | CLEAN |
| `SW4`-`SW6`, `SW8` pads 1, 4; `SW7`, `SW9` pads 2, 3 | tactile | the un-shorting fix of 2026-09-22 leaves one terminal per internal bar unconnected. Floating is correct **if** the pairs are as claimed; section 4 re-reads the TS1103S drawing. | CLEAN pending 4 |
| `U104`/`U204` pins 1, 13 | phase pulses, PC II out | outputs (CD4046B p1 terminal assignment and Fig 1). | CLEAN |
| `U104`/`U204` pin 10 | demodulator out | CD4046B p1: "If unused this terminal should be left open." | CLEAN |
| `U104`/`U204` pin 15 | zener | an optional regulator zener to VSS (Fig 1). Open is unused. | CLEAN |
| `U101.3`, `U201.3` | OUT1 | review-packet item 2: the manual's module uses one output. Section 5 re-reads it. | CLEAN pending 5 |
| `U7.6` | R.C. | section 2 | pending 2 |
| `J9.3`, `J10.3` | tip switch | outputs; the normalling contact is unused. Section 7. | CLEAN pending 7 |
| `DS1`, `J1`, `J11` unnumbered pads | mounting pegs | no electrical function. | CLEAN |

### Unconnected pins, faceplate (23)

`U1` pins 6-22 and 40-45: all are Px.y GPIO (pin names list `P1.6` ... `P6.2`).
SLASEO5D section 7.6, Table 7-4: unused Px.0-Px.7 are left **open** and
"switched to port function, output direction (PxDIR.n = 1)". Open is correct
in hardware; the firmware half goes to section 10. **CLEAN** (firmware
requirement noted).

## Symbol pins vs footprint pads vs datasheet pin count

Symbol pin set equals footprint pad set, with no duplicate numbering, on every
part except these, all explained:

| ref | symbol pins | pads | difference |
|---|---|---|---|
| `DS1` | 9 | 13 | 4 unnumbered mounting pads |
| `J1` | 13 | 15 | 2 unnumbered locating pegs. Note **no pin 9**: pads are 1-8, 10-13 and `CD`. Section 4 checks that against the TF-PUSH drawing. |
| `J11` | 16 | 18 | 2 unnumbered locating pegs |
| faceplate `E1`-`E4` | 5 | 208-213 | the comb electrodes: many copper pads per element number, by design |

Datasheet pin counts, per block section, as each part is derived from its
drawing.

## Verdicts

| ref.pin | net | source says | ours | verdict |
|---|---|---|---|---|
| all 944 main-board connections | | netmap | schematic and board agree | CLEAN |
| all 145 faceplate connections | | netmap | schematic and board agree | CLEAN |
| connection count | | runbook/docs: 942 | 944 | DEFECT (doc) |
| `U3.28`, `U3.8`, `U4.28` | ENC4_B, ENC8_B, BTN4 | current MCP23017 revision (not in repo) | inputs on GPA7/GPB7 | BLOCKED |
| `U4` GPB4-7, GPA2-3 | none | no rule in Rev C | floating inputs | QUESTION |
| `J1.1`, `J1.8` | none | SD spec (not in repo) | floating DAT2/DAT1 | QUESTION |
| `F1` | VBUS/VBUS_F | needs its own sheet | none in repo | BLOCKED |
| `REVIEW-INDEX.md` rows for C29 and RV1-RV6 | | BOM | stale part mapping | DEFECT (doc) |

## Defects, ranked

Nothing in section 1 would kill the board. The bookkeeping chain from netmap
through the schematic to the copper is intact on both boards.

1. **Doc (cosmetic):** the 942/309/219 figure is stale in the runbook,
   `docs/review-packet.md`, `datasheets/REVIEW-INDEX.md` and the
   `tools/blockview.py` docstring. Today: 944/316/223.
2. **Doc (cosmetic):** `REVIEW-INDEX.md` datasheet mapping for `C29` and
   `RV1`-`RV6` predates the C29 and pot changes.

Carried forward: GPA7/GPB7 (section 4, potentially a functional defect on two
encoders and one button), F1's ratings (section 2), floating SD DAT1/DAT2
(section 4), firmware termination of unused MCP23017 and MSP430 pins.

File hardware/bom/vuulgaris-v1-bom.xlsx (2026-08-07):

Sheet: BOM
Vuulgaris V1 - Bill of Materials
Prototype quantity (qty 1) pricing. Blue = confirmed price from a real listing. Black = estimate, not verified.
Source: docs/design-state.md section 10. Update Qty and Unit Price; Ext Price and all totals are formulas.
Ref | Category | Part / Description | MPN or Part # | Source | Part Link / Notes | Qty | Unit Price | Ext Price | Confirmed? | Stock | Notes
U1 | Core | Daisy Patch SM (STM32H750 audio engine) | Patch SM | Electrosmith direct | electro-smith.com - buy direct, resellers ~$51 | 1 | $31.99 | $31.99 | Yes |  | Biggest single line. ADR 0008.
U2 | Touch | MSP430FR2675TPTR CapTIvate MCU, LQFP-48 (PT) | MSP430FR2675TPTR | LCSC | C2052972 | 1 | $4.49 | $4.49 | Yes | 10 | PROTO QTY ONLY. Reels of 1000 available. ADR 0002.
DS1 | Display | 2.42" SSD1309 OLED 128x64 SPI, bare panel + FPC | HS242L01W4S01 | LCSC | C5139768 | 1 | $12.22 | $12.22 | Yes | 27 | PROTO QTY ONLY. Second-source for production. ADR 0006.
J1 | Storage | microSD socket, vertical | PJS008U-3000-0 (ref) | LCSC | C393941 | 1 | $0.06 | $0.06 | Yes | 205170 | JLC flags: needs an assembly fixture for placement.
VT1-4 | Analog | Vactrol, VTL5C3 or VTL5C3/2 dual | VTL5C3 | Xvive reissue | Excelitas line discontinued. Duals give a matched stereo pair per package. | 4 | $6.50 | $26.00 | No |  | COST LEVER #1. $5-8 ea. RoHS/cadmium UNVERIFIED - Q5. ADR 0007.
U3-6 | Analog | Op amps for LPG (TL07x class) | TL074 / TL072 | LCSC | Count depends on final Bergman redraw | 4 | $1.10 | $4.40 | No |  | Est $3-6 total.
D1-20 | ESD | TVS diode, ESD clamp, one per electrode | TPD1E10B06 | LCSC | TI-named part in the no-overlay fallback | 20 | $0.08 | $1.60 | No |  | 5 electrodes x 4 pads. ADR 0004.
R1-20 | ESD | Series resistor 470R-1k, one per electrode | 470R-1k 0402/0603 | LCSC | On the MCU side of the TVS | 20 | $0.01 | $0.20 | No |  | 5 electrodes x 4 pads. ADR 0004.
R21-24 | BSL | Resistor pair, 5V to 3.3V divider on BSL RST + TEST | 1.8k / 3.3k 0603 | LCSC | Gate outs are 0-5V; MSP430 I/O abs max is DVCC+0.3 = 3.6V | 4 | $0.01 | $0.04 | No |  | 2 per line, 2 lines (B5, B6). Scope the edges before writing BSL code. Q13.
RV1-12 | Controls | Potentiometer, 9mm linear 10K - channel (2 per ch) | RD901F-40-15F-B10K-00D70 | Alpha / Thonk | CV_1-CV_8 (C2-C9). Wire top of pot to 5V OUT (A6). | 8 | $0.70 | $5.60 | No |  | ADR 0009. Input-only pins, zero GPIO cost.
RV9-10 | Controls | Potentiometer, 9mm linear 10K - env A/R + CV amt L/R | RD901F-40-15F-B10K-00D70 | Alpha / Thonk | A2 attack, A3 release, D9 CV amt L, D8 CV amt R. Wire to 3V3 OUT (A10). | 4 | $0.70 | $2.80 | No |  | One envelope shared; per-side CV amount. ADR 0009.
RV13 | Analog | Potentiometer, DUAL-GANG (stereo) 10K - LPG offset | dual-gang 10K | LCSC / Thonk | NOT on the Daisy. Sums into both L and R LPG control inputs on the analog board. | 1 | $1.60 | $1.60 | No |  | 0 ADC pins. Cannot be preset-saved: Daisy never reads it. ADR 0007.
ENC1 | Controls | Rotary encoder with push |  | LCSC | Main PCB per IO plan B | 1 | $0.80 | $0.80 | No
SW1 | Controls | Mode switch: stereo VCF or stereo VCA (2-position) |  | TBD | DPDT, one pole per stereo side. Commodity part. | 1 | $1.50 | $1.50 | No |  | Was 4P3T. Two positions now, so no availability risk. Closes Q6. ADR 0007.
SW2 | Controls | Source switch, DPDT break-before-make |  | TBD | Non-shorting. 100k-1M to gnd on common + DC blocking caps | 1 | $1.50 | $1.50 | No |  | ADR 0007.
U7 | Controls | CD4051 analog mux - NOT USED | CD4051 | LCSC | Would spend 3 GPIO on select lines to save 2. Wrong tool here. | 0 | $0.35 | $0.00 | No |  | REMOVED per ADR 0009. Zero spare GPIO for select lines anyway.
J2-9 | IO | 3.5mm jack: audio out L/R + external in L/R | WQP-WQP518MA | Thonk | No CV or gate jacks (ADR 0009). Stereo out + stereo external in for the source switch. | 4 | $1.10 | $4.40 | No |  | Was 8. Revise if a headphone out or mono sum is added.
J10 | IO | Board-to-board connector, faceplate <-> main |  | TBD | ~8-10 pins: 3V3, GND, UART, I2C, IRQ, RST, TEST | 2 | $1.50 | $3.00 | No |  | Test points on all four signals.
J11 | IO | CAPTIVATE-PGMR connector (faceplate, DNP on production) |  | TI | Required for Design Center live tuning | 1 | $0.80 | $0.80 | No |  | Leave unpopulated on production. ADR 0005.
PCB1 | PCB | Faceplate PCB, 4-layer, ENIG, ~219 x 110mm |  | JLCPCB | L1 electrodes / L2 traces / L3 hatched gnd / L4 MCU | 1 | $25.00 | $25.00 | No |  | ENIG NOT HASL. ADR 0004. Est $20-50 for both boards.
PCB2 | PCB | Main PCB |  | JLCPCB |  | 1 | $15.00 | $15.00 | No
PWR1 | Power | 3V3 regulator + local filtering at MSP430 |  | LCSC | Do NOT share the rail with audio circuitry | 1 | $2.00 | $2.00 | No |  | LPG is on +/-12V.
MISC | Passives | Discretes and passives, whole board |  | LCSC | Decoupling at the MCU, LPG passives, charge-pump caps + IREF for the OLED | 1 | $19.00 | $19.00 | No |  | Est $14-24.
 |  | CONFIRMED SUBTOTAL (blue prices only) |  |  |  |  |  | $48.76
 |  | ESTIMATED SUBTOTAL (unverified) |  |  |  |  |  | $115.24
 |  | TOTAL, qty 1 |  |  |  |  |  | $164.00
 |  | Design-state section 10 sanity range: $125-200 at prototype quantity.
 |  | ENCLOSURE IS NOT IN THIS LIST. Prior design was CNC walnut. Cost lever #3 and currently unbounded.
 |  | Green rows changed 2026-08-06 with the resolved IO plan (ADR 0009): 10 pots not 12, DPDT mode switch, no mux, BSL dividers added.

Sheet: Cost levers
Cost levers, in priority order
From docs/design-state.md section 10.
# | Lever | Current cost | Alternative | Saving | Trade-off
1 | Vactrols (4x) | $26.00 | Match cheaper LDR+LED cells by measurement, or accept 2 and go mono LPG | $13.00 | Hand-matching labour per unit, or losing stereo. Also the RoHS/cadmium exposure sits here.
2 | Display 2.42" -> 1.54" | $12.22 | LCSC C5139767, 1.54" SPI, 49 in stock | $5.01 | 2.42" is 2.5x the diagonal at the same pixel count. Real loss in legibility.
3 | Enclosure | $0.00 | Not costed at all. Prior design was CNC walnut. | $0.00 | Unbounded. This is the largest unknown in the whole BOM.

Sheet: Stock watch
Stock watch
Parts where availability, not price, is the risk. Re-check before every order.
Part | LCSC # | Stock at last check | Production path | Risk
MSP430FR2675TPTR | C2052972 | 10 | LCSC-Reels, 1000 pcs | HIGH. Prototype quantity only. Reel is a real cash commitment and there is no second source for CapTIvate.
2.42" SSD1309 SPI | C5139768 | 27 | Second-source outside LCSC | MEDIUM. Commodity format, widely available elsewhere. C5139769 has 8. I2C versions stock better but I2C is the interference-worst choice.
microSD socket | C393941 | 205,170 | LCSC, plus 600k at 6-8 day lead | LOW. But JLC needs an assembly fixture to place it.
Vactrols (VTL5C3) | n/a | n/a | Xvive reissue | MEDIUM. Excelitas discontinued the line. Xvive LED is brighter, giving longer release, so drive current needs trimming. RoHS status UNVERIFIED.

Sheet: Legend
How to use this workbook
Edit these columns only | Qty (G) and Unit Price (H) on the BOM sheet. Ext Price, subtotals and the total are formulas and will update.
Blue price text | Confirmed against a real listing at qty 1. Trust these.
Black price text | Estimate from design-state section 10. Not verified. Confirmed? column reads No.
Amber Confirmed? cell | Price is an estimate. Replace with a real quote before this number is used for anything.
Amber Stock cell | Fewer than 100 units available. Prototype quantity, not a production quantity.
Example row format | U2 / Touch / MSP430FR2675TPTR CapTIvate MCU, LQFP-48 (PT) / MSP430FR2675TPTR / LCSC / C2052972 / 1 / $4.49 / Yes / 10
Assumption: vactrol unit price | $6.50 taken as the midpoint of the $5-8 range in design-state section 6. Not a quote.
Assumption: PCB split | $25 faceplate + $15 main, inside the $20-50 combined estimate in design-state section 10. 4-layer ENIG at low qty.
Assumption: pot count | 12, per IO plan A. Plan B also lands on 12 but allocates them differently. Unresolved: docs/notes/open-questions.md Q3.
Assumption: jack count | 8. Not yet fixed. IO plan B has no CV jacks into the Daisy, which would reduce this.
Assumption: op amp count | 4 packages. Depends on the final Bergman redraw and is a placeholder.
Not included | Enclosure. CAPTIVATE-PGMR + FR2676 + BSWP dev kit (one-off tooling, roughly $50-150, not per-unit). Shipping, tax, assembly labour, JLC setup fees.
Source of all confirmed prices | docs/design-state.md section 10, LCSC and Electrosmith listings at qty 1.

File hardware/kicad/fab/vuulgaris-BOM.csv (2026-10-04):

Comment | Designator | Footprint | LCSC Part # | Qty | Note
0402WGF2201TCE | R20,R21 | R0402 | C25879 | 2
0R (IN GAIN -- OPEN, see docs/bbd-mki.md) | R104,R204 | R0603 | C21189 | 2
100k | R106,R115,R116,R117,R122,R124,R125,R128,R130,R206,R215,R216,R217,R222,R224,R225,R228,R230,R305,R309,R310,R317,R318,R320,R323,R328,R330,R331,R333,R405,R409,R410,R417,R418,R420,R423,R428,R430,R431,R433,R509,R510,R519,R520 | R0603 | C25803 | 44
100nF / CC0603JRX7R8BB104 | C31,C34,C35,C38,C39,C40,C41,C43,C105,C106,C107,C108,C109,C111,C121,C122,C205,C206,C207,C208,C209,C211,C221,C222,C301,C302,C303,C304,C401,C402,C403,C404,C507,C508,C509,C510 | C0603 | C14663 | 36
10k | R118,R126,R218,R226,R301,R302,R308,R314,R401,R402,R408,R414,R505 | R0603 | C25804 | 13
10nF C0G 0805 | C119,C219 | C0805 | C237168 | 2
10uF / CL21A106KAYNNNE | C20,C22,C24,C25,C29,C42,C110,C210 | C0805 | C15850 | 8
12x12 tactile | SW4,SW5,SW6,SW7,SW8,SW9 | KEY-TH_4P-L12.0-W12.0-P5.00-LS12.5 | C54573007 | 6
150k | R303,R403 | R0603 | C22807 | 2
15k | R311,R312,R411,R412 | R0603 | C22809 | 4
1M | R501,R502 | R0603 | C22935 | 2
1N4148W | D103,D104,D105,D106,D107,D203,D204,D205,D206,D207,D302,D402 | SOD-123_L2.8-W1.8-LS3.7-RD | C81598 | 12
1k | R107,R207,R315,R415,R503,R504,R514,R516,R517,R518 | R0603 | C21190 | 10
1k2 | R513,R515 | R0603 | C22765 | 2
1nF C0G | C114,C214,C309,C409 | C0603 | C163508 | 4
1uF X7R 50V / CC0805KKX7R9BB105 | C30,C113,C120,C213,C220,C306,C406,C501,C502,C503,C504,C505,C506,C511,C512 | C0805 | C28323 | 15
2.2M | R121,R221,R334,R434 | R0603 | C22938 | 4
20k trim | RT301,RT401,RT501,RT502,RT503,RT504 | RES-ADJ-SMD_3224W | C55071 | 6
220pF C0G | C116,C216,C307,C407 | C0603 | C27675 | 4
22k | R110,R111,R129,R210,R211,R229 | R0603 | C31850 | 6
22pF C0G | C310,C410 | C0603 | C1653 | 2
2k2 | R521,R522 | R0603 | C4190 | 2
2nF C0G | C305,C405 | C0603 | C296055 | 2
33k | R307,R407 | R0603 | C4216 | 2
39k | R123,R223 | R0603 | C23153 | 2
3V9 zener | D301,D401 | SOD-123_L2.7-W1.6-LS3.7-RD-1 | C213113 | 2
4.7k | R119,R219 | R0603 | C23162 | 2
4.7nF C0G | C308,C408 | C0603 | C576818 | 2
470R | R131,R132,R231,R232,R306,R406 | R0603 | C23179 | 6
470k | R304,R404 | R0603 | C23178 | 2
47k | R113,R213,R506,R507,R508 | R0603 | C25819 | 5
4M7 | R313,R413 | R0603 | C23163 | 2
4R7 | R511,R512 | R0603 | C23164 | 2
51k | R114,R214 | R0603 | C23196 | 2
6.2k | R127,R227 | R0603 | C4260 | 2
62k | R120,R220 | R0603 | C23221 | 2
82k | R112,R212 | R0603 | C23254 | 2
AMS1117-3.3 | U5,U6 | SOT-223-3_L6.5-W3.4-P2.30-LS7.0-BR | C6186 | 2
AMS1117-5.0 | U8 | SOT-223-3_L6.5-W3.4-P2.30-LS7.0-BR | C6187 | 1
ASMD1812-300 | F1 | F1812 | C135366 | 1
BEAD0805S601A20T | FB1,FB2 | R0805 | C1017 | 2
BLM18PG121SN1D_C14709 | L1,L2 | L0603 | C14709 | 2
CC0603JRNPO9BN103 | C28 | C0603 | C57112 | 1
CD4046B | U104,U204 | SO-16_L10.3-W5.3-P1.27-LS7.8-BL | C2651237 | 2
CL05B104KO5NNNC | C21,C23,C26,C27,C44 | C0402 | C1525 | 5
CUTOFF / FILTER CV AMT / RESONANCE / TIME / WET/DRY | RV1,RV2,RV3,RV4,RV6 | RES-ADJ-TH_RK09L1240A12 |  | 5 | NOT FROM JLC -- FIT BY HAND. Alpha RD902F-40-15R1-B100K, dual B100K 9mm vertical, Tayda A-5440. Pad-for-pad with the RK09L footprint per Alpha's drawing RD902F-40-(L)R1-XXX-00D70. M7x0.75 bushing, 6.35mm round shaft. Do not substitute C380211 -- that is the 10k ALPS this replaced.
DKM10E-12 | U7 | PWRM-TH_DKMW30F-12 |  | 1 | NOT PLACEABLE -- PRE-ORDER ONLY. JLC returns 'No Result Found' for C6934792 in the in-stock library: 0 stock, pre-order at $15.10, MOQ 1. This is the power converter for the entire board, so it is the one shortage that stops a build. Source it outside LCSC (Mouser/Digi-Key/Arrow all list it) and hand-fit -- it is a through-hole 1x1in module, trivial to solder.
EC11L1525G01 | ENC0 | SW-TH_ALPS_EC11L1525G01 | C2991196 | 1
EC12E2430803 | ENC1,ENC2,ENC3,ENC4,ENC5,ENC6,ENC7,ENC8 | SW-TH_EC12EXXXX | C470684 | 8
ES_DAISY_PATCH_SM_REV1 | U1 | DAISY_PATCH_SM |  | 1 | module, socketed or hand soldered
FACEPLATE 2x5 IDC | J12 | IDC-TH_10P-P2.54_C5665 | C5665 | 1
FEEDBACK | RV5 | RES-ADJ-TH_RK09L1240A12 |  | 1 | NOT FROM JLC -- FIT BY HAND. Alpha RD902F-40-15R1-B10K, dual B10K 9mm vertical, Tayda A-6433. Pad-for-pad with the RK09L footprint per Alpha's drawing RD902F-40-(L)R1-XXX-00D70. M7x0.75 bushing, 6.35mm round shaft. Do not substitute C380211 -- that is the 10k ALPS this replaced.
HS242L01W4S01 | DS1 | LCD-TH_HS242L01W4S01 |  | 1 | BUY FROM LCSC, FIT BY HAND -- C5139768, 27 in stock at $12.22. Not in JLC's assembly library, and it is a display module on its own 68x43mm PCB with a glass panel: do not reflow or wave solder it
J113 / MMBFJ113 | Q1,Q2 | SOT-23-3_L2.9-W1.3-P1.90-LS2.4-BR | C891686 | 2
MCP23017-E_SO | U3,U4 | SOIC-28_L18.0-W7.5-P1.27-LS10.3-BL | C47023 | 2
OPA1688_FLAT | U9,U10 | SOP-8_L4.9-W3.9-P1.27-LS6.0-BL | C206212 | 2
PJ-376 | J2,J3,J4,J5,J6 | AUDIO-TH_PJ-376 | C22355746 | 5
PJ-603_C41409498 | J7,J8,J9,J10 | AUDIO-TH_PJ-603 | C41409498 | 4
RT0603BRD072K2L | R24,R25 | R0603 | C861295 | 2
RT0603BRD075K1L | R22,R23 | R0603 | C122969 | 2
RVT1E470M0505_C2977553 | C32,C33 | CAP-SMD_BD5.0-L5.3-W5.3-LS6.3-FD | C2977553 | 2
RVT1H220M0605 | C36,C37 | CAP-SMD_BD6.3-L6.6-W6.6-FD | C72505 | 2
SMAJ6.0A | D3 | SMA_L4.3-W2.6-LS5.2-RD | C223993 | 1
SW_DPDT_FLAT | SW1,SW2 | SW-TH_DW3_DPDT_2MD1T1B1M2QES |  | 2 | no LCSC source -- hand solder
TFPUSH | J1 | TF-SMD_TF-PUSH | C393941 | 1
TL072_FLAT | U102,U103,U106,U202,U203,U206 | SOIC-8_L4.9-W3.9-P1.27-LS6.1-BL | C67473 | 6
TL074 | U302,U402 | SOIC-14_3.9x8.7mm_P1.27mm | C12594 | 2
TL084 | U301,U401 | SOIC-14_3.9x8.7mm_P1.27mm | C8956 | 2
TYPE-C-31-M-12 | J11 | USB-C_SMD-TYPE-C-31-M-12_1 | C165948 | 1
V3205SD | U101,U201 | DIP-8_SPECIAL_V3205SD |  | 2 | no LCSC source -- hand solder
VTL5C3 | VT301,VT302,VT401,VT402 | VACTROL-TH_VTL5C3 |  | 4 | no LCSC source -- hand solder, Xvive reissue
YLED0402Y | D1,D2 | LED0402-R-RD | C20608782 | 2

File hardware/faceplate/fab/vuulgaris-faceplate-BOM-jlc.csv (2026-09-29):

Comment | Designator | Footprint | LCSC Part #
100nF | C2 | C0603 | C14663
10uF | C1 | C0805 | C15850
1nF C0G | C4 | C0603 | C163508
1uF | C3 | C0805 | C28323
22pF C0G | C5,C6 | C0603 | C1653
32.768kHz FC-135 12.5pF | Y1 | XTAL-SMD_FC-135_3.2x1.5mm | C32346
470 | R11,R12,R13,R14,R21,R22,R23,R24,R31,R32,R33,R34,R41,R42,R43,R44 | R0603 | C23179
47k | R1,R2,R3 | R0603 | C25819
HX JN2.54-2x5P TP H8.9 | J1 | IDC-SMD_10P-P2.54_C41376028 | C41376028
MSP430FR2675TPT | U1 | LQFP-48_7x7mm_P0.5mm_PT0048A | C2052972
TPD1E10B06DPYR | D11,D12,D13,D14,D21,D22,D23,D24,D31,D32,D33,D34,D41,D42,D43,D44 | X1SON-2_DPY0002A | C48260

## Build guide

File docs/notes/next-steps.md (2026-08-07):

# Next steps

From `../design-state.md` section 12, reordered so the cheap thing that could invalidate
everything else comes first.

---

## 0. The one that gates the rest

**Validate the sensing concept cheaply before committing.**

Buy CAPTIVATE-PGMR, plus the FR2676 board and CAPTIVATE-BSWP. Make one cheap 2-layer JLC
board with **two pads in final tooth geometry, ~216mm long**. Roughly $50 and 2 weeks.

Measure: **scan time, jitter in counts at rest, linearity.** Then hear what it sounds like
driving sample position.

This tells you whether the interaction works before the faceplate exists. **If one pad
works, the remaining unknown is arithmetic on the measured number.** If it does not, you
have spent $50 instead of a faceplate spin.

**Lay out TWO pads on that board, not one.** The second pad costs almost nothing and answers
[Q17](open-questions.md) (how tight the inter-pad gap can be), which currently gates the panel
layout to the tune of up to 30mm of height. Include two or three candidate gap widths, with and
without a grounded guard strip.

Notes on the kit:
- CAPTIVATE-BSWP is listed as required for evaluating self-cap designs and gives a
  reference slider baseline worth having for comparison.
- The FR2676 board has a 48-pin sensor panel connector for plugging in your own test pad.
- FR2676 is the same silicon for touch purposes, just 64KB/8KB against the FR2675's 32KB/6KB.
- Design Center projects target a specific device. **Regenerate for FR2675 (PT/LQFP-48)**
  when moving to your own board. CAP pin *naming* carries over; physical pins do not.
- Design Center is 1.83.00.08, dated May 2020. Stale toolchain, and the release notes say
  to re-create projects made in earlier versions.

---

## Blocking layout

**Q2, Q3, Q4, Q6 are closed.** What is left before copper:

1. **Generate the slider electrode assignment in Design Center first**, then lay out the PCB
   to match. `RX0->E00, RX1->E01, RX2->E02, RX3->E03`. Swapped pins give garbage
   interpolation on a board that passes every electrical check.
2. **Cross-check the comb pad generator against SLAA891's OpenSCAD output.** Export DXF from
   TI's scripts, diff against the generator's SVG, before committing copper.
3. **Update `mockups/faceplate-mockup.html`.** It still draws the **3-zone / no-wraparound**
   electrode ramp (E1->E4). It needs the 4-zone RX0-wraparound pattern from
   [ADR 0003](../decisions/0003-comb-pad-rx0-wraparound.md) before it drives layout.
4. **Verify the LCSC C2052972 footprint against the datasheet PT package drawing.**
   A 10-minute check that prevents a dead board.
5. **Lay out per [../pin-allocation.md](../pin-allocation.md).** It is resolved and safe to
   build against. Do not forget **VREG on pin 31 needs an external decoupling cap** (it is the
   CapTIvate regulator output, not a supply input), and the **dividers on BSL RST/TEST**.

---

## Blocking BOM

6. **Second-source the display.** 27 units at LCSC is not a production quantity.
   [Q7](open-questions.md#q7-production-quantity-sourcing)
7. **Order the DPDT switches and bench-confirm their pinout with a multimeter** before
   silkscreening labels. Lever direction is inverted relative to the pin it selects.

---

## Firmware, can proceed in parallel

8. **Scope B5/B6 through the BSL dividers before writing any BSL code.**
   [Q13](open-questions.md#q13-do-the-gate-outputs-drive-bsl-cleanly-through-a-divider)
9. **Test the OLED + bootloader combination early.**
   [Q10](open-questions.md#q10-oled-dead-under-bootloader)
10. **Decide the sample-storage strategy concretely.** Factory samples in QSPI so the
    instrument makes sound with no card; user samples on SD; both into SDRAM at load; playback
    always from SDRAM. **Decide the advertised per-track length limit**, which is bounded by
    SDRAM, not card size.
11. **Use a SoftPot as a bench stand-in** to develop scrubbing feel and the sampler engine
    before cap-touch hardware exists. It is a bad product part and a fine dev tool.

---

## Not yet on any list

- **Enclosure.** Not in the BOM at all. The prior design was CNC walnut. This is cost lever #3
  and currently an unbounded number.
- **Vactrol bleed.** Solve it deliberately in the schematic rather than rediscovering it on
  assembled hardware.
- **Vactrol matching procedure.** Four cells matched in on-resistance *and* decay across L
  and R. Either a measurement-and-bin process, or VTL5C3/2 duals so each stereo pair comes
  from one package.
- **No CV or gate jacks, ever, without a respin.** All four gate pins are consumed by internal
  functions under [ADR 0009](../decisions/0009-io-plan-12-adc.md). Worth being sure about
  before the panel is drawn.

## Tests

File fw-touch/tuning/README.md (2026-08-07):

# Tuning logs

One dated file per session. The point is to be able to answer "did that get better or worse"
six months from now.

Template:

```markdown
# 2026-MM-DD - <board rev> - <what changed>

Hardware:  single-pad test board rev A / faceplate rev A
Overlay:   none (exposed copper, ENIG)
Env:       bench / in enclosure / in enclosure with PSU running

## Measured
Scan time, 4 sliders:     ___ ms      (Design Center reports directly)
Scan time, 1 slider:      ___ ms
Noise immunity:           on / off
Jitter at rest:           ___ counts  @ resolution ___
  -> usable positions:    ___         (resolution / jitter)
Linearity, worst dev:     ___ mm over 175mm
Lower_Trim / Upper_Trim:  ___ / ___
Dead zone measured:       ___ mm at each end

## Conclusion
Does it sound like an instrument when driving sample position? y/n
What to change next:
```

**The number that matters most is jitter in counts**, because usable resolution is
`resolution / jitter` and smoothing only trades it against latency, which is audible as lag.

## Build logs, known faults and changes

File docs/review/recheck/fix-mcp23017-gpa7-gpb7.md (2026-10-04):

# Fix: MCP23017 GPA7/GPB7 used as inputs

**Severity: kills the main board's controls.** This supersedes section 04's
BLOCKED item (U3.28, U3.8, U4.28) and should count as a DEFECT in
`00-summary.md`.

## Status, 2026-10-03

Done: steps 2-6 and step 8's docs. The schematic is regenerated and checked
956/956 with KiCad's own netlister (`netcheck.py`); the board is routed, DRC
has 0 errors, `boardcheck.py` has 0 parity mismatches, and the fab package is
rebuilt. Step 1 was done on 2026-10-04: `datasheets/` now holds DS20001952E,
downloaded from Microchip, and the three places quoted below were read in that
PDF (p1 Features; Table 2-1 on p11, rows GPB7 and GPA7; the Revision D entry in
the history on p39). They say what this note says. Not done: step 7 (firmware).

How the board got there, since none of it was routed by hand in one sitting:

- `ENC4_A`, `ENC4_B`, `ENC8_A`, `ENC8_B`: Freerouting 2.4.1, headless, every
  other track protected. It could not get all four out of U4 with the board's
  0.8/0.4 vias (0.05 mm short between two vias under the north row), so these
  four nets use **0.6/0.3 vias**, eight of them. That is inside the board's
  own minimum (0.5/0.3) and the faceplate already uses 0.5 and 0.6. About
  1.5 mm of `ENC8_B` at U4.6 is necked to 0.1874 mm by the router.
- `BTN4`: placed by hand after the router failed it. South out of U4.7, a
  0.6/0.3 via, B.Cu west at y 127.3, a second via beside its old In1 trunk.
- Ground ties: U3.8 and U3.28 by `gndvias.py`. U4.8 by a track under pad 9 to
  U4.10's existing via. U4.28 by a track to a 0.8/0.4 via at (172.25, 116.5),
  3.1 mm out, just past `gndvias.py`'s 3.0 mm reach.
- ENC8 stayed on GPB4/GPB5 and ENC4 on GPA2/GPA3. The swap this note offers
  below was trial-routed and did no better.

## What is wrong

Microchip's current MCP23017 datasheet says GPA7 and GPB7 are **output only**
on the MCP23017 (I2C part; the SPI MCP23S17 is not affected):

- DS20001952E (July 2026), page 1, Features: "16-Bit Remote Bidirectional I/O
  Port (Pins GPA7, GPB7 are output only for MCP23017)".
- Table 2-1, rows GPA7 and GPB7: "Output only (MCP23017)".
- The change first appeared in Revision D (June 2022). Revision E keeps it.

The reason Microchip gave, as relayed in [Adafruit issue
#57](https://github.com/adafruit/Adafruit_CircuitPython_MCP230xx/issues/57)
and [Hackaday](https://hackaday.com/2023/02/03/mcp23017-went-through-shortage-hell-lost-two-inputs/):
transitions on these pins while they are inputs can corrupt the I2C **SDA**
signal. Microchip has published no detailed mechanism. The silicon
was not changed; only the document was. Every MCP23017 you can buy has the
problem.

The repo's copy, `datasheets/Microchip-MCP23017-datasheet.pdf`, was Revision C
until 2026-10-04 (`fetch-datasheets.sh` fetched `20001952c.pdf`), which
predates the note. That is why the design used these pins. It is Revision E
now.

## Why it is worse than three dead inputs

U3 and U4 share one I2C bus with nothing else on it but the Daisy (`U1.B7`
SCL, `U1.B8` SDA) and the pull-ups R20/R21. A corrupted SDA does not stay on
one pin: it can garble any transaction to either expander, so all eight
parameter encoders, ENC0 and all six buttons are at risk.

## The three affected signals today

| net | part | pin | port bit |
|---|---|---|---|
| `ENC4_B` | U3 (0x20) | 28 | GPA7 |
| `ENC8_B` | U3 (0x20) | 8 | GPB7 |
| `BTN4` (SW7) | U4 (0x21) | 28 | GPA7 |

U3 is full (16 encoder lines), so the fix has to go through U4. U4's free pins
are GPB4 (5), GPB5 (6), GPB6 (7), GPB7 (8, also output only, so unusable),
GPA2 (23) and GPA3 (24): five usable.

## The move

Move **both** lines of ENC4 and ENC8, not just their B lines, so each encoder
is read from one port in one I2C read. A quadrature pair split across two
chips is sampled in two transactions, and the skew between them can drop or
reverse steps on a fast turn. Five signals, five usable pins: an exact fit.

| net | from | to | why there |
|---|---|---|---|
| `ENC4_A` | U3.27 GPA6 | **U4.23 GPA2** | GPA row faces the encoders (north side of U4) |
| `ENC4_B` | U3.28 GPA7 | **U4.24 GPA3** | same port as `ENC4_A` |
| `ENC8_A` | U3.7 GPB6 | **U4.5 GPB4** | same port as `ENC8_B`; port B is already polled at 2 kHz for ENC0 |
| `ENC8_B` | U3.8 GPB7 | **U4.6 GPB5** | |
| `BTN4` | U4.28 GPA7 | **U4.7 GPB6** | GPB row faces SW7 (south side of U4) |

After the move, U3.7 and U3.27 are unconnected. The four GPA7/GPB7 pins
(U3.8, U3.28, U4.8 and U4.28) must **not** be left floating; tie them to
`GND`. The reported trigger is a *transition* on one of these pins while it is
an input, and every MCP23017 pin is an input from power-up until firmware
writes IODIR. A floating pin can toggle in that window, and later too if
firmware ever leaves it an input. Tied to ground it cannot move. U4.8 is
already floating on the current board, so this applies even to the pin
nothing uses today. U4 then has no free GPIO left.

Board geometry for the routing (sheet mm): U3 at (151.0, 105.0) and U4 at
(183.2, 120.0), both on F.Cu. ENC4 is at (140.1, 84.6) and ENC8 at (184.1,
84.6), north of both. SW7 is at (134.3, 147.7), south-west of U4. U4's
GPA2/GPA3 pads are at y 114.94 (north row) and GPB4-GPB6 at y 125.06 (south
row). The ENC8 lines have to come round U4 to its south row; if that routes
badly, swap the assignments (ENC8 on GPA2/GPA3, ENC4 on GPB4/GPB5).
Whichever way, each pair stays on one port.

## Steps

1. **Datasheet.** Replace `datasheets/Microchip-MCP23017-datasheet.pdf` with
   DS20001952E and update the URL in `datasheets/fetch-datasheets.sh` (ask
   before downloading, per CLAUDE.md).
2. **Netmap.** In `hardware/kicad/tools/netmap.json`, reassign the five nets
   per the table, remove U3.7 and U3.27 from their nets, and put U3.8, U3.28,
   U4.8 and U4.28 on `GND`.
3. **Schematic.** From `hardware/kicad/`, run
   `python3 tools/mksch.py && python3 tools/netcheck.py` (with `set -o
   pipefail` if piped). Then F8 in Pcbnew to pull the new nets in.
4. **Board.** The five old tracks become ratsnest. Delete them, then route
   the new connections by hand (hand-routing is yours, per CLAUDE.md). No
   parts move.
5. **Checks.** `boardcheck.py`, `drc.py` (0 errors, 0 unconnected),
   `place.py --check`, `schdraw.py`, `gerbercheck.py`. Diff against HEAD for
   anything DRC cannot see.
6. **Fab package.** Regenerate the BOM, CPL, gerbers, drill files and
   `hardware/vuulgaris-v1-fab.zip` in the same commit (CLAUDE.md's command
   list).
7. **Firmware**, when written:
   - Set U3 GPA7/GPB7 and U4 GPA7/GPB7 as **outputs driven low** (IODIR bit
     0, OLAT bit 0), matching their ground tie. **Never drive them high**: that
     would short a driven output to GND. Leaving them as inputs is also safe
     once they are tied, because a grounded input never transitions.
   - Read ENC4 from U4 port A, ENC8 and BTN4 from U4 port B.
   - Poll U4 port B at 2 kHz as before (it now carries ENC0, ENC8 and BTN4).
     U4 port A at 500 Hz is enough for ENC4, as for the other parameter
     encoders.
8. **Docs** in the same commit:
   - `docs/pin-allocation.md`: the button table (SW7 to GPB6), the encoder
     tables, the "free GPIO" counts, and a line on why GPA7/GPB7 are unused.
   - `mockups/generate-faceplate.py` (the `GPIO` list near line 1641), then
     regenerate `hardware/placement-panel-facing.txt` and confirm
     `place.py --check` still says all 24 are on their holes. Only the note
     column should change.
   - `docs/design-state.md` "GPIO ... 7 pins still free" becomes 0.
   - `docs/review/recheck/04-digital-io.md` and `00-summary.md`: BLOCKED
     becomes DEFECT (kills), fixed in the commit that lands this.

## If boards are already built

There is no fix without a rework.
- **Firmware only:** configure the three pins (and U4 GPB7) as outputs. The
  bus is then safe once firmware runs, though not during the power-up
  window before it does. ENC4 and ENC8 lose direction sensing and BTN4 is
  dead.
- **Bodge:** cut the three traces at U3.28, U3.8 and U4.28, and wire them to
  U4.24, U4.6 and U4.7 (GPA3, GPB5, GPB6). That leaves each encoder split
  across two chips: acceptable for slow turns, and it can miss steps on fast
  ones.

## Sources

- [MCP23017/MCP23S17 datasheet DS20001952E](https://ww1.microchip.com/downloads/aemDocuments/documents/APID/ProductDocuments/DataSheets/MCP23017-MCP23S17-16-Bit-IO-Expander-with-Serial-Interface-DS20001952.pdf), page 1 and Table 2-1, revision history
- [Adafruit_CircuitPython_MCP230xx issue #57](https://github.com/adafruit/Adafruit_CircuitPython_MCP230xx/issues/57) (Microchip's SDA explanation, relayed)
- [RobTillaart/MCP23017_RT issue #40](https://github.com/RobTillaart/MCP23017_RT/issues/40)
- Board and netmap positions read from `hardware/kicad/vuulgaris.kicad_pcb` and `hardware/kicad/tools/netmap.json` at commit 95a5074.

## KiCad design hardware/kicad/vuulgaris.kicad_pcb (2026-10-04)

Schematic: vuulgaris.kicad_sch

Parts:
C20, C22, C24, C25, C29: CL21A106KAYNNNE; C0805
C21, C23, C26, C27, C44: CL05B104KO5NNNC; C0402
C28: CC0603JRNPO9BN103; C0603
C30: CC0805KKX7R9BB105; C0805
C31, C34, C35, C38, C39, C43: CC0603JRX7R8BB104; C0603
C32, C33: RVT1E470M0505_C2977553; CAP-SMD_BD5.0-L5.3-W5.3-LS6.3-FD
C36, C37: RVT1H220M0605; CAP-SMD_BD6.3-L6.6-W6.6-FD
C40, C41, C105, C106, C107, C108, C109, C111, C121, C122, C205, C206, C207, C208, C209, C211, C221, C222, C301, C302, C303, C304, C401, C402, C403, C404, C507, C508, C509, C510: 100nF; C0603
C42, C110, C210: 10uF; C0805
C113, C120, C213, C220, C306, C406, C501, C502, C503, C504, C505, C506, C511, C512: 1uF X7R 50V; C0805
C114, C214, C309, C409: 1nF C0G; C0603
C116, C216, C307, C407: 220pF C0G; C0603
C119, C219: 10nF C0G 0805; C0805
C305, C405: 2nF C0G; C0603
C308, C408: 4.7nF C0G; C0603
C310, C410: 22pF C0G; C0603
D1, D2: YLED0402Y; LED0402-R-RD
D3: SMAJ6.0A; SMA_L4.3-W2.6-LS5.2-RD
D103, D104, D105, D106, D107, D203, D204, D205, D206, D207, D302, D402: 1N4148W; SOD-123_L2.8-W1.8-LS3.7-RD
D301, D401: 3V9 zener; SOD-123_L2.7-W1.6-LS3.7-RD-1
DS1: HS242L01W4S01; LCD-TH_HS242L01W4S01
ENC0: EC11L1525G01; SW-TH_ALPS_EC11L1525G01
ENC1, ENC2, ENC3, ENC4, ENC5, ENC6, ENC7, ENC8: EC12E2430803; SW-TH_EC12EXXXX
F1: ASMD1812-300; F1812
FB1, FB2: BEAD0805S601A20T; R0805
J1: TFPUSH; TF-SMD_TF-PUSH
J2, J3, J4, J5, J6: PJ-376; AUDIO-TH_PJ-376
J7, J8, J9, J10: PJ-603_C41409498; AUDIO-TH_PJ-603
J11: TYPE-C-31-M-12; USB-C_SMD-TYPE-C-31-M-12_1
J12: FACEPLATE 2x5 IDC; IDC-TH_10P-P2.54_C5665
L1, L2: BLM18PG121SN1D_C14709; L0603
Q1, Q2: J113 / MMBFJ113; SOT-23-3_L2.9-W1.3-P1.90-LS2.4-BR
R20, R21: 0402WGF2201TCE; R0402
R22, R23: RT0603BRD075K1L; R0603
R24, R25: RT0603BRD072K2L; R0603
R104, R204: 0R (IN GAIN -- OPEN, see docs/bbd-mki.md); R0603
R106, R115, R116, R117, R122, R124, R125, R128, R130, R206, R215, R216, R217, R222, R224, R225, R228, R230, R305, R309, R310, R317, R318, R320, R323, R328, R330, R331, R333, R405, R409, R410, R417, R418, R420, R423, R428, R430, R431, R433, R509, R510, R519, R520: 100k; R0603
R107, R207, R315, R415, R503, R504, R514, R516, R517, R518: 1k; R0603
R110, R111, R129, R210, R211, R229: 22k; R0603
R112, R212: 82k; R0603
R113, R213, R506, R507, R508: 47k; R0603
R114, R214: 51k; R0603
R118, R126, R218, R226, R301, R302, R308, R314, R401, R402, R408, R414, R505: 10k; R0603
R119, R219: 4.7k; R0603
R120, R220: 62k; R0603
R121, R221, R334, R434: 2.2M; R0603
R123, R223: 39k; R0603
R127, R227: 6.2k; R0603
R131, R132, R231, R232, R306, R406: 470R; R0603
R303, R403: 150k; R0603
R304, R404: 470k; R0603
R307, R407: 33k; R0603
R311, R312, R411, R412: 15k; R0603
R313, R413: 4M7; R0603
R501, R502: 1M; R0603
R511, R512: 4R7; R0603
R513, R515: 1k2; R0603
R521, R522: 2k2; R0603
RT301, RT401, RT501, RT502, RT503, RT504: 20k trim; RES-ADJ-SMD_3224W
RV1: CUTOFF; RES-ADJ-TH_RK09L1240A12
RV2: RESONANCE; RES-ADJ-TH_RK09L1240A12
RV3: FILTER CV AMT; RES-ADJ-TH_RK09L1240A12
RV4: TIME; RES-ADJ-TH_RK09L1240A12
RV5: FEEDBACK; RES-ADJ-TH_RK09L1240A12
RV6: WET/DRY; RES-ADJ-TH_RK09L1240A12
SW1, SW2: SW_DPDT_FLAT; SW-TH_DW3_DPDT_2MD1T1B1M2QES
SW4, SW5, SW6, SW7, SW8, SW9: 12x12 tactile; KEY-TH_4P-L12.0-W12.0-P5.00-LS12.5
TP1: +12V; TestPoint_TH_D1.0mm
TP2: -12V; TestPoint_TH_D1.0mm
TP3: +5V; TestPoint_TH_D1.0mm
TP4: +5V BBD; TestPoint_TH_D1.0mm
TP5: GND; TestPoint_TH_D1.0mm
TP6: DRY L; TestPoint_TH_D1.0mm
TP7: DRY R; TestPoint_TH_D1.0mm
TP8: SIGIN L; TestPoint_TH_D1.0mm
TP9: SIGIN R; TestPoint_TH_D1.0mm
TP10: LED L; TestPoint_TH_D1.0mm
TP11: LED R; TestPoint_TH_D1.0mm
TP12: CLK L; TestPoint_TH_D1.0mm
TP13: CLK R; TestPoint_TH_D1.0mm
TP14: TIME CV; TestPoint_TH_D1.0mm
TP15: LPG ENV; TestPoint_TH_D1.0mm
U1: ES_DAISY_PATCH_SM_REV1; DAISY_PATCH_SM
U3, U4: MCP23017-E_SO; SOIC-28_L18.0-W7.5-P1.27-LS10.3-BL
U5, U6: AMS1117-3.3; SOT-223-3_L6.5-W3.4-P2.30-LS7.0-BR
U7: DKM10E-12; PWRM-TH_DKMW30F-12
U8: AMS1117-5.0; SOT-223-3_L6.5-W3.4-P2.30-LS7.0-BR
U9, U10: OPA1688_FLAT; SOP-8_L4.9-W3.9-P1.27-LS6.0-BL
U101, U201: V3205SD; DIP-8_SPECIAL_V3205SD
U102, U103, U106, U202, U203, U206: TL072_FLAT; SOIC-8_L4.9-W3.9-P1.27-LS6.1-BL
U104, U204: CD4046B; SO-16_L10.3-W5.3-P1.27-LS7.8-BL
U301, U401: TL084; SOIC-14_3.9x8.7mm_P1.27mm
U302, U402: TL074; SOIC-14_3.9x8.7mm_P1.27mm
VT301, VT302, VT401, VT402: VTL5C3; VACTROL-TH_VTL5C3

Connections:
/AUDIO_IN_L: R501.1, SW2.2 (A_COM), U1.B4 (AUDIO_IN_L)
/AUDIO_IN_R: R502.1, SW2.5 (B_COM), U1.B3 (AUDIO_IN_R)
/AUDIO_OUT_L: R301.1, R310.1, U1.B2 (AUDIO_OUT_L)
/AUDIO_OUT_R: R401.1, R410.1, U1.B1 (AUDIO_OUT_R)
/BBD_AC_L: C113.2, R124.1, U106.3 (1IN+)
/BBD_AC_R: C213.2, R224.1, U206.3 (1IN+)
/BBD_C1A_L: C114.1, U104.6 (CI(1))
/BBD_C1A_R: C214.1, U204.6 (CI(1))
/BBD_C1B_L: C114.2, U104.7 (CI(2))
/BBD_C1B_R: C214.2, U204.7 (CI(2))
/BBD_CLKN_L: U101.2 (CP2), U104.2 (PHASECOMPIOUT)
/BBD_CLKN_R: U201.2 (CP2), U204.2 (PHASECOMPIOUT)
/BBD_CLK_L: C116.1, TP12.1, U101.6 (CP1), U104.3 (COMPIN), U104.4 (VCOOUT)
/BBD_CLK_R: C216.1, TP13.1, U201.6 (CP1), U204.3 (COMPIN), U204.4 (VCOOUT)
/BBD_DRY_L: R104.1, RV6.1, TP6.1, U102.1 (1OUT), U102.2 (1IN-)
/BBD_DRY_R: R204.1, RV6.4, TP7.1, U202.1 (1OUT), U202.2 (1IN-)
/BBD_FB_L: R112.1, RV5.2
/BBD_FB_R: R212.1, RV5.5
/BBD_GAIN_L: R104.2, R114.1
/BBD_GAIN_R: R204.2, R214.1
/BBD_INF_L: R107.2, U102.3 (1IN+)
/BBD_INF_R: R207.2, U202.3 (1IN+)
/BBD_INH_L: D104.2 (A), D106.1 (K), R117.2, U104.5 (INHIBIT)
/BBD_INH_R: D204.2 (A), D206.1 (K), R217.2, U204.5 (INHIBIT)
/BBD_IN_L: R106.1, R107.1, R315.2
/BBD_IN_R: R206.1, R207.1, R415.2
/BBD_MIXW_L: RV6.2, U103.5 (2IN+)
/BBD_MIXW_R: RV6.5, U203.5 (2IN+)
/BBD_MIX_L: R131.1, U103.6 (2IN-), U103.7 (2OUT)
/BBD_MIX_R: R231.1, U203.6 (2IN-), U203.7 (2OUT)
/BBD_OUT_L: C503.1, C505.1, R131.2, R513.1
/BBD_OUT_R: C504.1, C506.1, R231.2, R515.1
/BBD_RAW_L: C113.1, R122.1, U101.4 (OUT2)
/BBD_RAW_R: C213.1, R222.1, U201.4 (OUT2)
/BBD_SH_FB_L: R129.1, R130.1, U106.6 (2IN-)
/BBD_SH_FB_R: R229.1, R230.1, U206.6 (2IN-)
/BBD_SH_G_L: D107.2 (A), Q1.3 (G), R128.2
/BBD_SH_G_R: D207.2 (A), Q2.3 (G), R228.2
/BBD_SH_HOLD_L: C119.1, Q1.2 (S), U106.5 (2IN+)
/BBD_SH_HOLD_R: C219.1, Q2.2 (S), U206.5 (2IN+)
/BBD_SH_IN_L: Q1.1 (D), R128.1, U106.1 (1OUT), U106.2 (1IN-)
/BBD_SH_IN_R: Q2.1 (D), R228.1, U206.1 (1OUT), U206.2 (1IN-)
/BBD_SIGIN_L: R118.2, TP8.1, U101.7 (IN), U103.1 (1OUT)
/BBD_SIGIN_R: R218.2, TP9.1, U201.7 (IN), U203.1 (1OUT)
/BBD_SUM_L: R112.2, R113.2, R114.2, R118.1, U103.2 (1IN-)
/BBD_SUM_R: R212.2, R213.2, R214.2, R218.1, U203.2 (1IN-)
/BBD_TIMEHI_L: R110.2, RV4.1
/BBD_TIMEHI_R: R210.2, RV4.4
/BBD_TIMELO_L: R111.1, RV4.3
/BBD_TIMELO_R: R211.1, RV4.6
/BBD_TIMEW_L: R115.1, RV4.2
/BBD_TIMEW_R: R215.1, RV4.5
/BBD_TRIGIN_L: C116.2, R127.1, U102.5 (2IN+)
/BBD_TRIGIN_R: C216.2, R227.1, U202.5 (2IN+)
/BBD_TRIGREF_L: R125.2, R126.1, U102.6 (2IN-)
/BBD_TRIGREF_R: R225.2, R226.1, U202.6 (2IN-)
/BBD_TRIG_L: D107.1 (K), U102.7 (2OUT)
/BBD_TRIG_R: D207.1 (K), U202.7 (2OUT)
/BBD_VCOCV_L: D103.2 (A), D105.1 (K), R115.2, R116.2, U104.9 (VCOIN)
/BBD_VCOCV_R: D203.2 (A), D205.1 (K), R215.2, R216.2, U204.9 (VCOIN)
/BBD_VCOR1_L: R123.1, U104.11 (R1TOVSS)
/BBD_VCOR1_R: R223.1, U204.11 (R1TOVSS)
/BBD_VCOR2_L: R121.1, U104.12 (R2TOVSS)
/BBD_VCOR2_R: R221.1, U204.12 (R2TOVSS)
/BBD_VGG_L: C110.1, R119.2, R120.1, U101.8 (VGG)
/BBD_VGG_R: C210.1, R219.2, R220.1, U201.8 (VGG)
/BBD_WETAC_L: C120.2, R132.1, RV5.3, RV6.3
/BBD_WETAC_R: C220.2, R232.1, RV5.6, RV6.6
/BBD_WETOUT_L: R132.2
/BBD_WETOUT_R: R232.2
/BBD_WET_L: C120.1, R130.2, U106.7 (2OUT)
/BBD_WET_R: C220.1, R230.2, U206.7 (2OUT)
/BTN1: SW4.3, U4.25 (GPA4)
/BTN2: SW5.3, U4.26 (GPA5)
/BTN3: SW6.3, U4.27 (GPA6)
/BTN4: SW7.1, U4.7 (GPB6)
/BTN5: SW8.3, U4.21 (GPA0)
/BTN6: SW9.1, U4.22 (GPA1)
/CC1: J11.A5 (CC1), R22.1
/CC2: J11.B5 (CC2), R23.2
/CVOUT_JACK: J2.3, R503.2
/CV_IN_JACK: J4.3, U1.C9 (CV8)
/ENC0_A: ENC0.A, U4.1 (GPB0)
/ENC0_B: ENC0.B, U4.2 (GPB1)
/ENC0_PUSH: ENC0.D, U4.3 (GPB2)
/ENC1_A: ENC1.A, U3.21 (GPA0)
/ENC1_B: ENC1.B, U3.22 (GPA1)
/ENC2_A: ENC2.A, U3.23 (GPA2)
/ENC2_B: ENC2.B, U3.24 (GPA3)
/ENC3_A: ENC3.A, U3.25 (GPA4)
/ENC3_B: ENC3.B, U3.26 (GPA5)
/ENC4_A: ENC4.A, U4.23 (GPA2)
/ENC4_B: ENC4.B, U4.24 (GPA3)
/ENC5_A: ENC5.A, U3.1 (GPB0)
/ENC5_B: ENC5.B, U3.2 (GPB1)
/ENC6_A: ENC6.A, U3.3 (GPB2)
/ENC6_B: ENC6.B, U3.4 (GPB3)
/ENC7_A: ENC7.A, U3.5 (GPB4)
/ENC7_B: ENC7.B, U3.6 (GPB5)
/ENC8_A: ENC8.A, U4.5 (GPB4)
/ENC8_B: ENC8.B, U4.6 (GPB5)
/EXT_AMP_IN_L: C511.2, R519.1, U10.3 (1IN+)
/EXT_AMP_IN_R: C512.2, R520.1, U10.5 (2IN+)
/EXT_AMP_OUT_L: C501.1, R302.1, RT503.1, U10.1 (1OUT)
/EXT_AMP_OUT_R: C502.1, R402.1, RT504.1, U10.7 (2OUT)
/EXT_FB_L: R521.1, RT503.2 (WIPER), RT503.3, U10.2 (1IN-)
/EXT_FB_R: R522.1, RT504.2 (WIPER), RT504.3, U10.6 (2IN-)
/EXT_IN_L: J7.4, R517.1
/EXT_IN_R: J8.4, R518.1
/EXT_PROT_L: C511.1, R517.2
/EXT_PROT_R: C512.1, R518.2
/GATEOUT_JACK: J3.3, R504.2
/GATE_IN: J5.3, U1.B10 (GATE_IN_1)
/GATE_OUT_1: R504.1, U1.B5 (GATE_OUT_1)
/GATE_OUT_2: R117.1, R217.1, U1.B6 (GATE_OUT_2)
/GND: C20.2, C21.2, C22.2, C23.2, C24.2, C25.2, C26.2, C27.2, C28.2, C29.2, C30.1, C31.1, C32.2, C33.1, C34.1, C35.2, C36.2, C37.1, C38.1, C39.2, C40.2, C41.2, C42.2, C43.2, C44.2, C105.2, C106.2, C107.2, C108.2, C109.2, C110.2, C111.2, C119.2, C121.2, C122.2, C205.2, C206.2, C207.2, C208.2, C209.2, C210.2, C211.2, C219.2, C221.2, C222.2, C301.2, C302.2, C303.2, C304.2, C307.2, C309.2, C401.2, C402.2, C403.2, C404.2, C407.2, C409.2, C507.2, C508.2, C509.2, C510.2, D1.2 (K), D2.1 (A), D3.2 (A), D105.2 (A), D106.2 (A), D205.2 (A), D206.2 (A), D301.1 (C), D401.1 (C), DS1.1 (GND), ENC0.6 (EH), ENC0.7 (EH), ENC0.C, ENC0.E, ENC1.C, ENC1.D, ENC1.E, ENC2.C, ENC2.D, ENC2.E, ENC3.C, ENC3.D, ENC3.E, ENC4.C, ENC4.D, ENC4.E, ENC5.C, ENC5.D, ENC5.E, ENC6.C, ENC6.D, ENC6.E, ENC7.C, ENC7.D, ENC7.E, ENC8.C, ENC8.D, ENC8.E, J1.6 (VSS), J1.10, J1.11, J1.12, J1.13, J2.1, J2.2, J3.1, J3.2, J4.1, J4.2, J5.1, J5.2, J6.1, J7.2, J7.3, J7.5, J8.2, J8.3, J8.5, J9.2, J9.5, J10.2, J10.5, J11.1 (EH), J11.2 (EH), J11.3 (EH), J11.4 (EH), J11.A1B12 (GND), J11.B1A12 (GND), J12.2, J12.4, J12.6, J12.8, J12.10, R22.2, R23.1, R106.2, R111.2, R120.2, R121.2, R122.2, R123.2, R124.2, R126.2, R127.2, R129.2, R206.2, R211.2, R220.2, R221.2, R222.2, R223.2, R224.2, R226.2, R227.2, R229.2, R308.2, R309.2, R310.2, R312.2, R313.2, R317.2, R318.2, R408.2, R409.2, R410.2, R412.2, R413.2, R417.2, R418.2, R501.2, R502.2, R514.2, R516.2, R519.2, R520.2, R521.2, R522.2, RT501.3, RT502.3, RV1.1, RV1.4, RV1.7, RV1.8, RV2.7, RV2.8, RV3.7, RV3.8, RV4.7, RV4.8, RV5.1, RV5.4, RV5.7, RV5.8, RV6.7, RV6.8, SW4.2, SW5.2, SW6.2, SW7.4, SW8.2, SW9.4, TP5.1, U1.A4 (GND), U1.A7 (GND), U3.8 (GPB7), U3.10 (VSS), U3.15 (A0), U3.16 (A1), U3.17 (A2), U3.28 (GPA7), U4.8 (GPB7), U4.10 (VSS), U4.16 (A1), U4.17 (A2), U4.28 (GPA7), U5.1 (GND), U6.1 (GND), U7.2 (-Vin), U7.4 (Common), U8.1 (GND), U101.1 (GND), U103.3 (1IN+), U104.8 (VSS), U201.1 (GND), U203.3 (1IN+), U204.8 (VSS), U302.3 (IN_A+), U302.5 (IN_B+), U302.10 (IN_C+), U302.12 (IN_D+), U402.3 (IN_A+), U402.5 (IN_B+), U402.10 (IN_C+), U402.12 (IN_D+)
/HP_BUF_L: R511.1, U9.1 (1OUT), U9.2 (1IN-)
/HP_BUF_R: R512.1, U9.6 (2IN-), U9.7 (2OUT)
/HP_DIV_L: R509.2, RT501.1
/HP_DIV_R: R510.2, RT502.1
/HP_IN_L: C505.2, R509.1
/HP_IN_R: C506.2, R510.1
/HP_OUT_L: J6.3, R511.2
/HP_OUT_R: J6.2, R512.2
/HP_W_L: RT501.2 (WIPER), U9.3 (1IN+)
/HP_W_R: RT502.2 (WIPER), U9.5 (2IN+)
/I2C_SCL: R20.1, U1.B7 (I2C1_SCL), U3.12 (SCL), U4.12 (SCL)
/I2C_SDA: R21.1, U1.B8 (I2C1_SDA), U3.13 (SDA), U4.13 (SDA)
/LED_NEG: D2.2 (K), R25.1
/LED_POS: D1.1 (A), R24.1
/LINE_OUT_L: J9.4, R513.2, R514.1
/LINE_OUT_R: J10.4, R515.2, R516.1
/LPG_ABUF_L: R311.1, U301.1 (OUT_A), VT301.3 (CELL1)
/LPG_ABUF_R: R411.1, U401.1 (OUT_A), VT401.3 (CELL1)
/LPG_AFB_L: R311.2, R312.1, U301.2 (IN_A-)
/LPG_AFB_R: R411.2, R412.1, U401.2 (IN_A-)
/LPG_BOUT_L: R306.1, U301.7 (OUT_B)
/LPG_BOUT_R: R406.1, U401.7 (OUT_B)
/LPG_BP_L: R308.1, U301.5 (IN_B+)
/LPG_BP_R: R408.1, U401.5 (IN_B+)
/LPG_C5_L: C305.2, R304.1
/LPG_C5_R: C405.2, R404.1
/LPG_CFB_L: R314.1, U301.9 (IN_C-)
/LPG_CFB_R: R414.1, U401.9 (IN_C-)
/LPG_CVC_L: R331.2, R333.1, U302.9 (IN_C-)
/LPG_CVC_R: R431.2, R433.1, U402.9 (IN_C-)
/LPG_CVD_L: R330.2, R331.1, U302.14 (OUT_D)
/LPG_CVD_R: R430.2, R431.1, U402.14 (OUT_D)
/LPG_CVI_L: R320.1, R323.2, U302.2 (IN_A-)
/LPG_CVI_R: R420.1, R423.2, U402.2 (IN_A-)
/LPG_CVW_L: R328.1, RV3.2
/LPG_CVW_R: R428.1, RV3.5
/LPG_CV_L: R304.2, R305.2, R333.2, U302.8 (OUT_C)
/LPG_CV_R: R404.2, R405.2, R433.2, U402.8 (OUT_C)
/LPG_ENV: R323.1, R423.1, R503.1, RV3.3, RV3.6, TP15.1, U1.C10 (CV_OUT_1)
/LPG_ENVN_L: R320.2, RV3.1, U302.1 (OUT_A)
/LPG_ENVN_R: R420.2, RV3.4, U402.1 (OUT_A)
/LPG_INF_L: C306.2, R309.1, U301.3 (IN_A+)
/LPG_INF_R: C406.2, R409.1, U401.3 (IN_A+)
/LPG_LDR_L: C309.1, R313.1, U301.10 (IN_C+), VT302.4 (CELL2)
/LPG_LDR_R: C409.1, R413.1, U401.10 (IN_C+), VT402.4 (CELL2)
/LPG_LEDD_L: D302.1 (K), R306.2
/LPG_LEDD_R: D402.1 (K), R406.2
/LPG_LEDK_L: D302.2 (A), R334.2, VT302.2 (K)
/LPG_LEDK_R: D402.2 (A), R434.2, VT402.2 (K)
/LPG_LEDM_L: VT301.2 (K), VT302.1 (A)
/LPG_LEDM_R: VT401.2 (K), VT402.1 (A)
/LPG_LED_L: D301.2 (A), R307.2, R317.1, R334.1, TP10.1, VT301.1 (A)
/LPG_LED_R: D401.2 (A), R407.2, R417.1, R434.1, TP11.1, VT401.1 (A)
/LPG_MID_L: C307.1, C308.1, VT301.4 (CELL2), VT302.3 (CELL1)
/LPG_MID_R: C407.1, C408.1, VT401.4 (CELL2), VT402.3 (CELL1)
/LPG_MIX_L: C306.1, R301.2, R302.2
/LPG_MIX_R: C406.1, R401.2, R402.2
/LPG_NC_L: U302.6 (IN_B-), U302.7 (OUT_B)
/LPG_NC_R: U402.6 (IN_B-), U402.7 (OUT_B)
/LPG_OFS_L: R303.1, RV1.2
/LPG_OFS_R: R403.1, RV1.5
/LPG_OUT_L: R314.2, R315.1, U301.8 (OUT_C), U301.12 (IN_D+)
/LPG_OUT_R: R414.2, R415.1, U401.8 (OUT_C), U401.12 (IN_D+)
/LPG_RESL_L: R318.1, RV2.3
/LPG_RESL_R: R418.1, RV2.6
/LPG_RESW_L: C310.1, RV2.2, U301.13 (IN_D-)
/LPG_RESW_R: C410.1, RV2.5, U401.13 (IN_D-)
/LPG_RES_L: C310.2, RV2.1, SW1.1 (A_NC), U301.14 (OUT_D)
/LPG_RES_R: C410.2, RV2.4, SW1.4 (B_NC), U401.14 (OUT_D)
/LPG_SUMCV_L: R328.2, R330.1, U302.13 (IN_D-)
/LPG_SUMCV_R: R428.2, R430.1, U402.13 (IN_D-)
/LPG_SUM_L: C305.1, R303.2, R305.1, RT301.1, U301.6 (IN_B-)
/LPG_SUM_R: C405.1, R403.2, R405.1, RT401.1, U401.6 (IN_B-)
/LPG_T1_L: R307.1, RT301.2 (WIPER), RT301.3
/LPG_T1_R: R407.1, RT401.2 (WIPER), RT401.3
/LPG_VCFSW_L: C308.2, SW1.2 (A_COM)
/LPG_VCFSW_R: C408.2, SW1.5 (B_COM)
/MSP430_RXD: J12.5, U1.A3 (UART_TX)
/MSP430_TXD: J12.7, U1.A2 (UART_RX)
/MSP_RST: J12.3, U4.4 (GPB3)
/MSP_TEST: J12.1
/NEG12V: C37.2, C39.1, C106.1, C108.1, C122.1, C206.1, C208.1, C222.1, C302.1, C304.1, C402.1, C404.1, C508.1, C510.1, L2.2, R25.2, R113.1, R213.1, TP2.1, U1.A1 (-12V), U9.4 (V-), U10.4 (V-), U102.4 (V-), U103.4 (V-), U106.4 (V-), U202.4 (V-), U203.4 (V-), U206.4 (V-), U301.11 (V-), U302.11 (V-), U401.11 (V-), U402.11 (V-)
/NEG12V_RAW: C33.2, C35.1, L2.1, U7.5 (-Vout)
/OLED_CS: DS1.7 (CS1), U1.D1 (SPI_NSS)
/OLED_DC: DS1.6 (DC), U1.D2 (SDMMC_D3)
/OLED_FONTCS: DS1.9 (CS2), R505.1
/OLED_MOSI: DS1.4 (SDA), U1.D9 (SPI_MOSI)
/OLED_RES: DS1.5 (RES), U1.A9 (USB_DP)
/OLED_SCK: DS1.3 (SCL), U1.D10 (SPI_SCK)
/P3V3_DAISY: C26.1, C27.1, C44.1, J1.4 (VDD), R20.2, R21.2, R506.2, R507.2, R508.2, U1.A10 (+3V3), U3.9 (VDD), U3.18 (~RESET), U4.9 (VDD), U4.15 (A0), U4.18 (~RESET)
/P3V3_MSP430: C22.1, C23.1, J12.9, U6.2 (VOUT), U6.4 (VOUT)
/P3V3_OLED: C20.1, C21.1, DS1.2 (VCC), R505.2, U5.2 (VOUT), U5.4 (VOUT)
/P5V: FB1.1, FB2.1, TP3.1, U1.A6 (+5V)
/P5V_BBD: C41.1, C42.1, C109.1, C111.1, C209.1, C211.1, D103.1 (K), D104.1 (K), D203.1 (K), D204.1 (K), R119.1, R219.1, TP4.1, U8.2 (VOUT), U8.4 (VOUT), U101.5 (VDD), U104.14 (SIGNALIN), U104.16 (VDD), U201.5 (VDD), U204.14 (SIGNALIN), U204.16 (VDD)
/P5V_MSP: C25.1, FB2.2, U6.3 (VIN)
/P5V_OLED: C24.1, FB1.2, U5.3 (VIN)
/POS12V: C36.1, C38.2, C40.1, C105.1, C107.1, C121.1, C205.1, C207.1, C221.1, C301.1, C303.1, C401.1, C403.1, C507.1, C509.1, L1.2, R24.2, R110.1, R125.1, R210.1, R225.1, RV1.3, RV1.6, TP1.1, U1.A5 (+12V), U8.3 (VIN), U9.8 (V+), U10.8 (V+), U102.8 (V+), U103.8 (V+), U106.8 (V+), U202.8 (V+), U203.8 (V+), U206.8 (V+), U301.4 (V+), U302.4 (V+), U401.4 (V+), U402.4 (V+)
/POS12V_RAW: C32.1, C34.2, L1.1, U7.3 (+Vout)
/SD_CLK: J1.5 (CLX), U1.D6 (SDMMC_CK)
/SD_CMD: J1.3 (CMD), R506.1, U1.D7 (SDMMC_CMD)
/SD_D0: J1.7 (DAT0), R507.1, U1.D5 (SDMMC_D0)
/SD_DAT3: J1.2 (CD/DAT3), R508.1
/SRC_EXT_L: C501.2, SW2.1 (A_NC)
/SRC_EXT_R: C502.2, SW2.4 (B_NC)
/SRC_RSMP_L: C503.2, SW2.3 (A_NO)
/SRC_RSMP_R: C504.2, SW2.6 (B_NO)
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

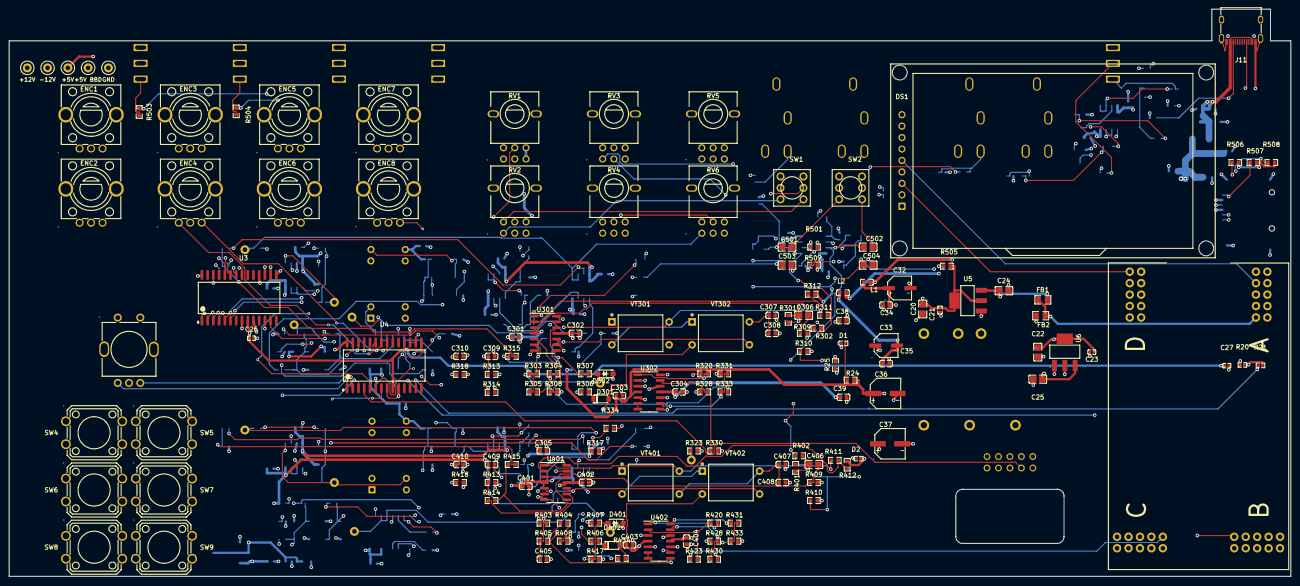
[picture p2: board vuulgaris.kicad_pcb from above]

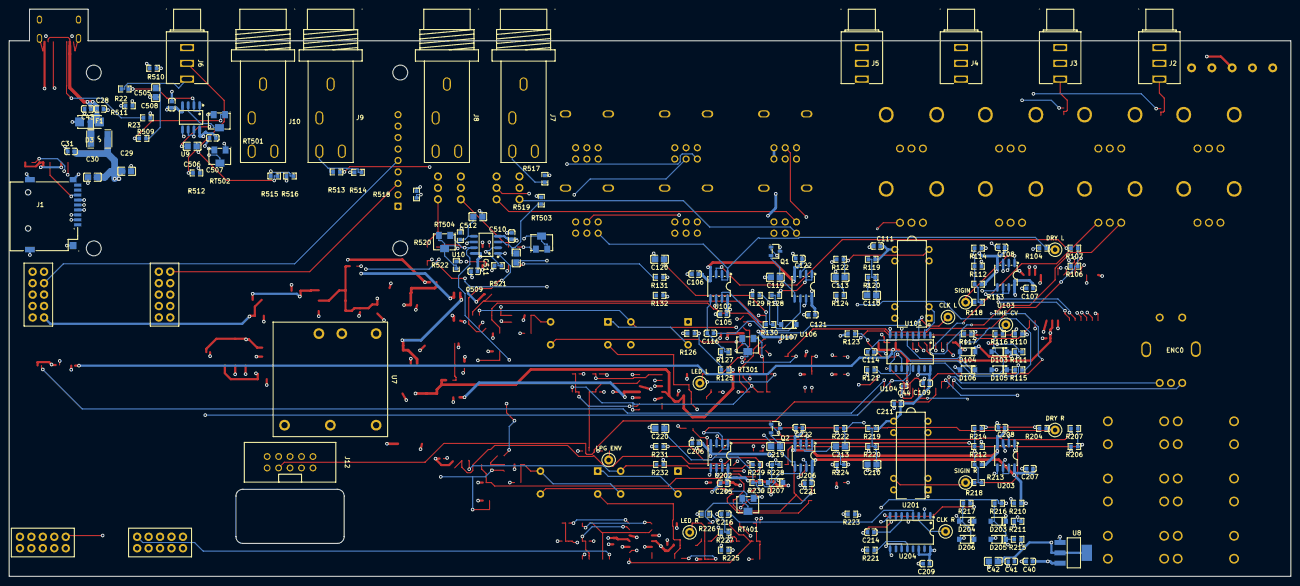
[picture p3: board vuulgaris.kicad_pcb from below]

Board: 4 copper layers, 284.3 x 125.8 mm, 321 parts (168 on the bottom side), 222 nets.

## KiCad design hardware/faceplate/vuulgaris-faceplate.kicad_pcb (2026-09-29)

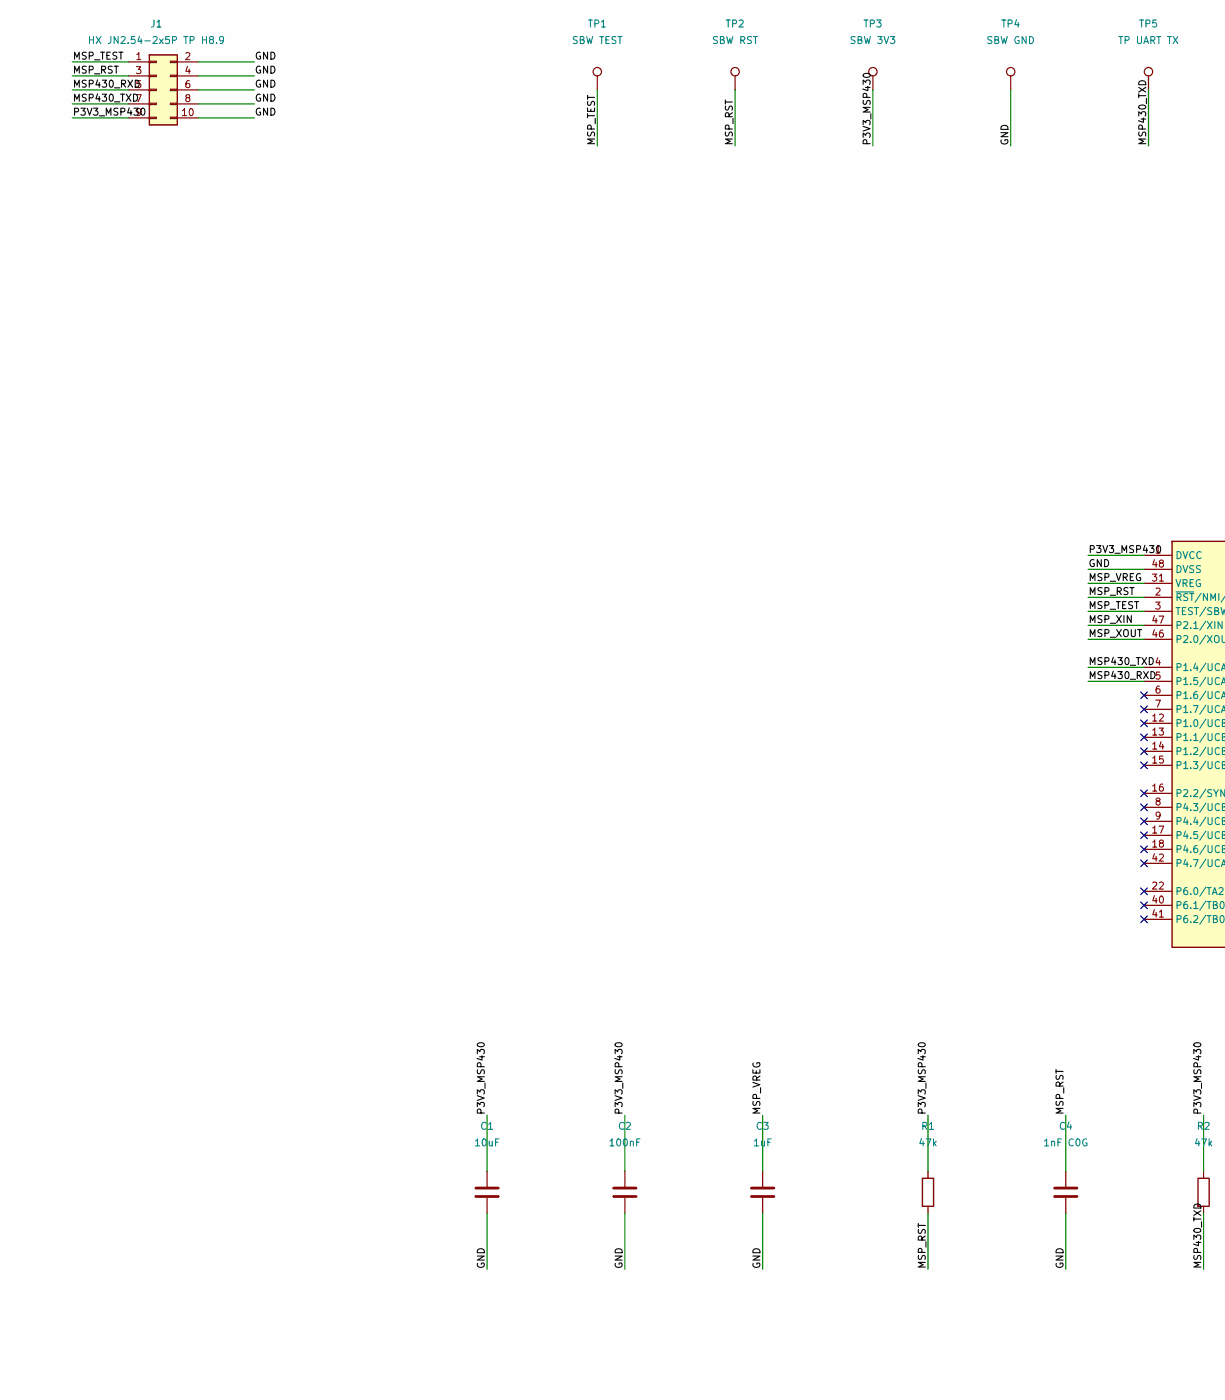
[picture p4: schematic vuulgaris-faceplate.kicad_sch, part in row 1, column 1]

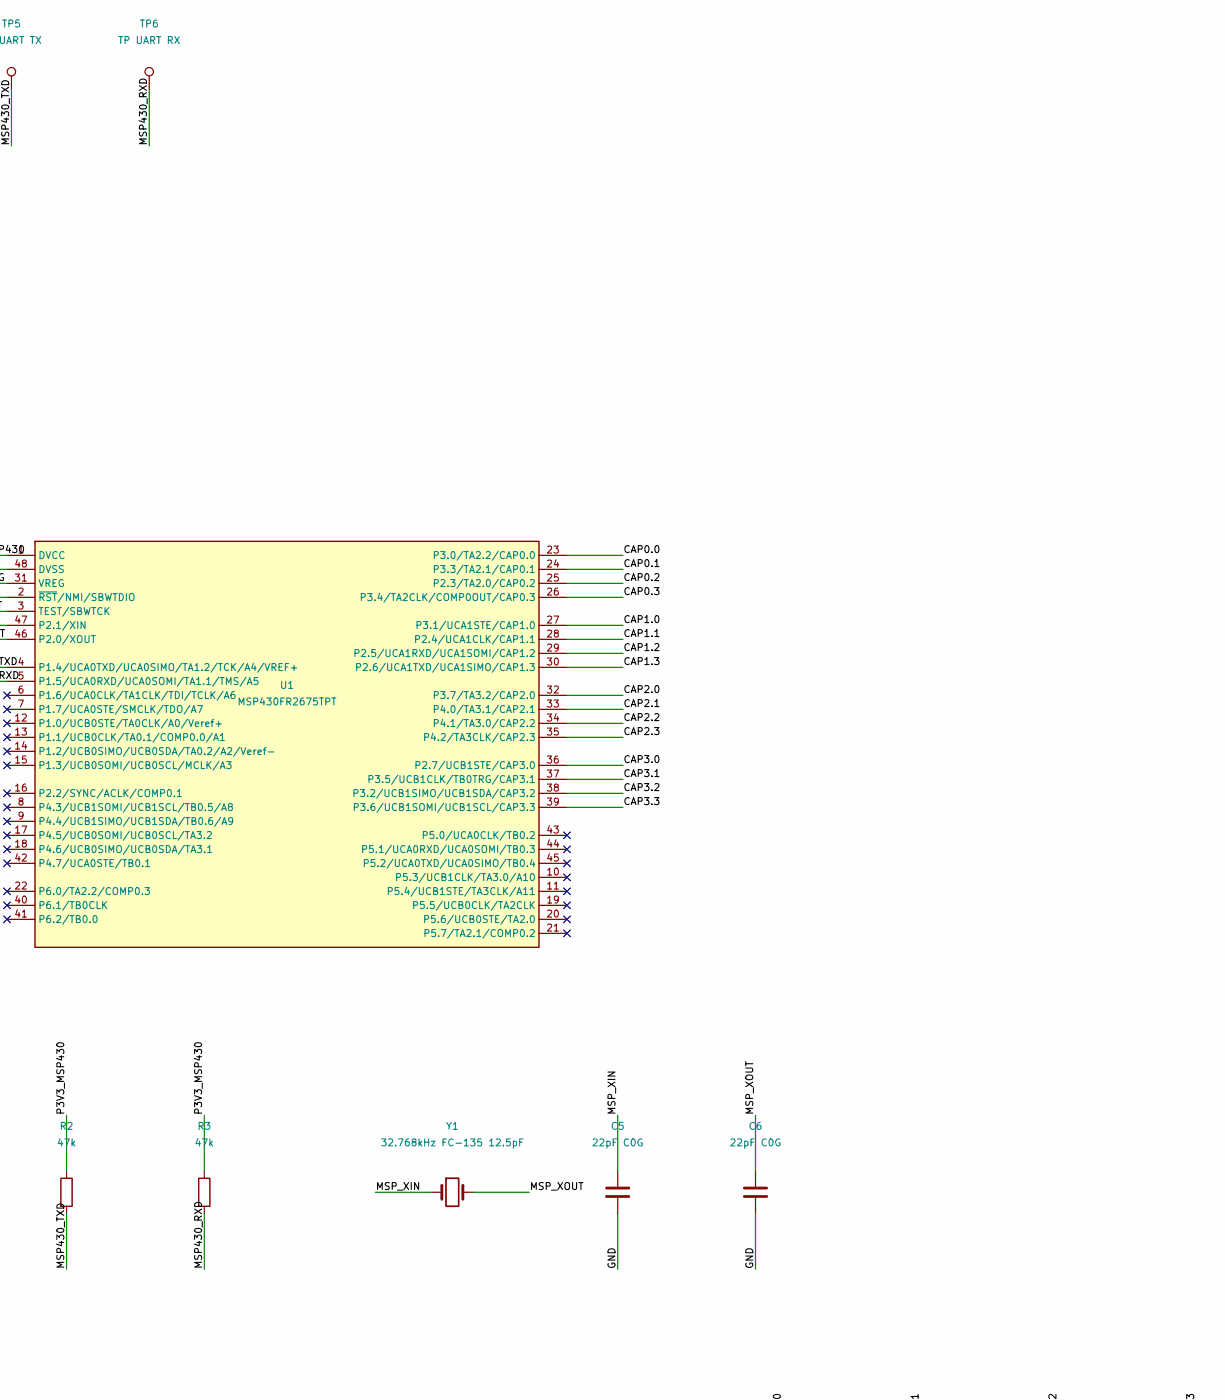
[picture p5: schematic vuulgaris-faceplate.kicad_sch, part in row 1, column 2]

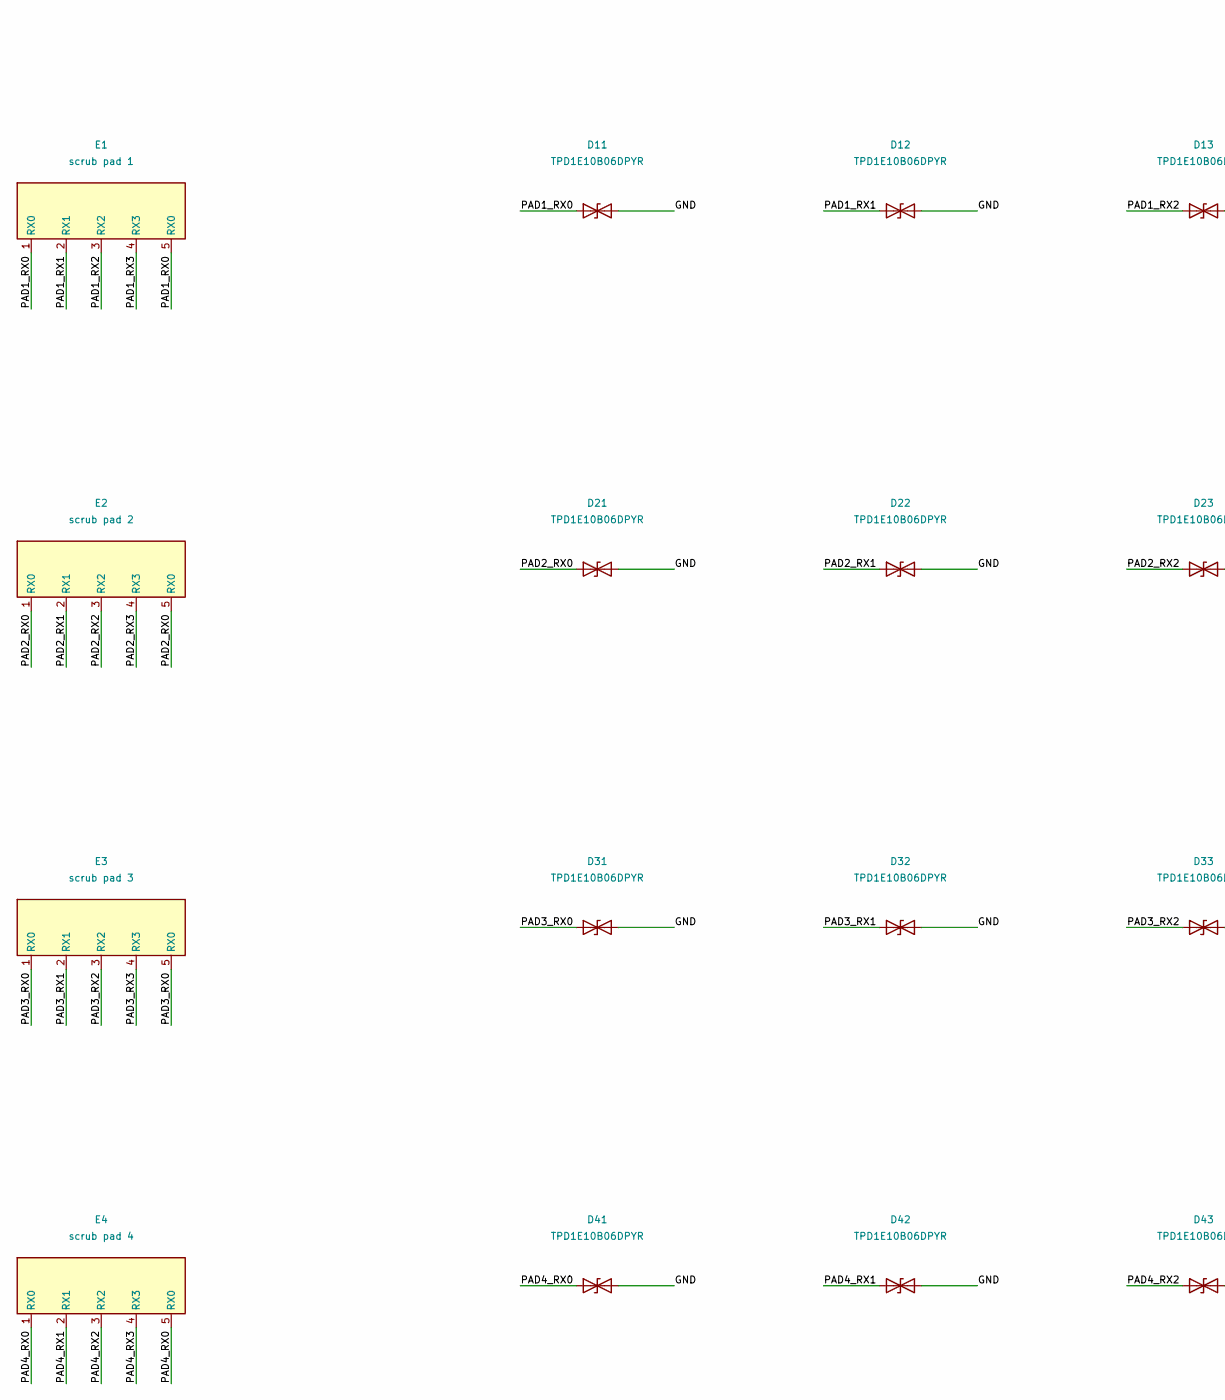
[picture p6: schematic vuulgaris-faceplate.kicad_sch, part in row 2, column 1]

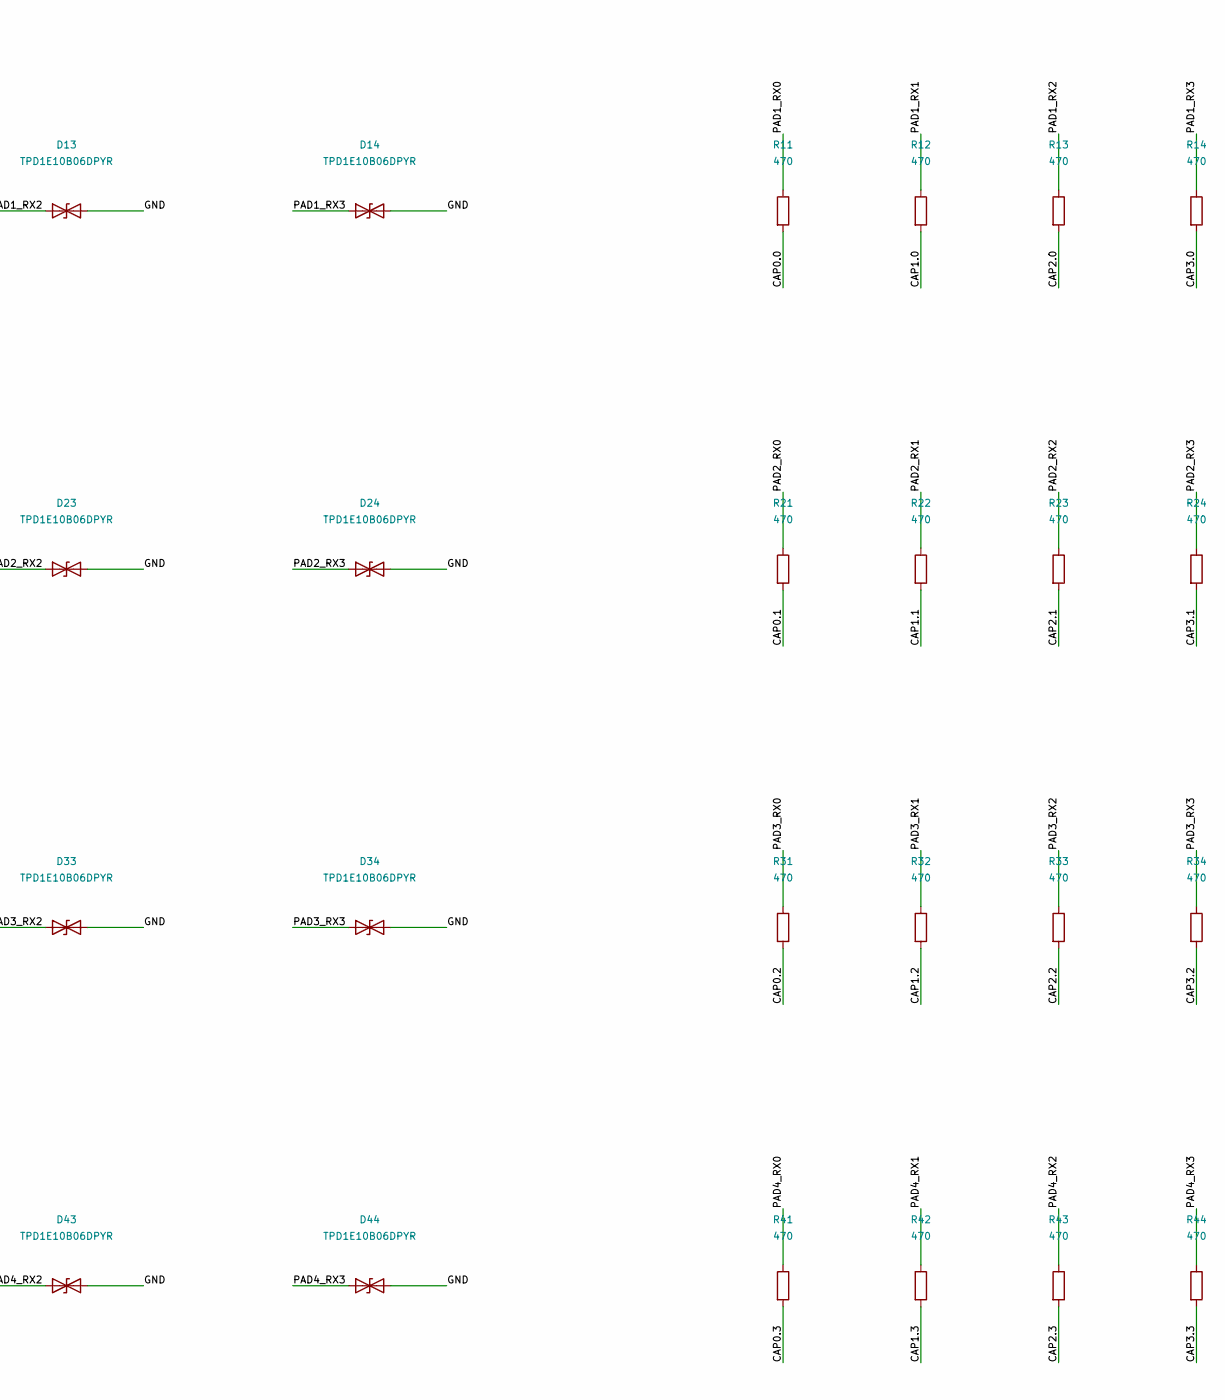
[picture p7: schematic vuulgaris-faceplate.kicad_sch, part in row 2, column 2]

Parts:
C1: 10uF; C0805
C2: 100nF; C0603
C3: 1uF; C0805
C4: 1nF C0G; C0603
C5, C6: 22pF C0G; C0603
D11, D12, D13, D14, D21, D22, D23, D24, D31, D32, D33, D34, D41, D42, D43, D44: TPD1E10B06DPYR; X1SON-2_DPY0002A
E1: scrub pad 1; SCRUB_PAD_216x10_P1
E2: scrub pad 2; SCRUB_PAD_216x10_P2
E3: scrub pad 3; SCRUB_PAD_216x10_P3
E4: scrub pad 4; SCRUB_PAD_216x10_P4
J1: HX JN2.54-2x5P TP H8.9; IDC-SMD_10P-P2.54_C41376028
R1, R2, R3: 47k; R0603
R11, R12, R13, R14, R21, R22, R23, R24, R31, R32, R33, R34, R41, R42, R43, R44: 470; R0603
TP1: SBW TEST; TestPoint_Pad_D1.5mm
TP2: SBW RST; TestPoint_Pad_D1.5mm
TP3: SBW 3V3; TestPoint_Pad_D1.5mm
TP4: SBW GND; TestPoint_Pad_D1.5mm
TP5: TP UART TX; TestPoint_Pad_D1.5mm
TP6: TP UART RX; TestPoint_Pad_D1.5mm
U1: MSP430FR2675TPT; LQFP-48_7x7mm_P0.5mm_PT0048A
Y1: 32.768kHz FC-135 12.5pF; XTAL-SMD_FC-135_3.2x1.5mm

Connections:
/CAP0.0: R11.2, U1.23 (P3.0/TA2.2/CAP0.0)
/CAP0.1: R21.2, U1.24 (P3.3/TA2.1/CAP0.1)
/CAP0.2: R31.2, U1.25 (P2.3/TA2.0/CAP0.2)
/CAP0.3: R41.2, U1.26 (P3.4/TA2CLK/COMP0OUT/CAP0.3)
/CAP1.0: R12.2, U1.27 (P3.1/UCA1STE/CAP1.0)
/CAP1.1: R22.2, U1.28 (P2.4/UCA1CLK/CAP1.1)
/CAP1.2: R32.2, U1.29 (P2.5/UCA1RXD/UCA1SOMI/CAP1.2)
/CAP1.3: R42.2, U1.30 (P2.6/UCA1TXD/UCA1SIMO/CAP1.3)
/CAP2.0: R13.2, U1.32 (P3.7/TA3.2/CAP2.0)
/CAP2.1: R23.2, U1.33 (P4.0/TA3.1/CAP2.1)
/CAP2.2: R33.2, U1.34 (P4.1/TA3.0/CAP2.2)
/CAP2.3: R43.2, U1.35 (P4.2/TA3CLK/CAP2.3)
/CAP3.0: R14.2, U1.36 (P2.7/UCB1STE/CAP3.0)
/CAP3.1: R24.2, U1.37 (P3.5/UCB1CLK/TB0TRG/CAP3.1)
/CAP3.2: R34.2, U1.38 (P3.2/UCB1SIMO/UCB1SDA/CAP3.2)
/CAP3.3: R44.2, U1.39 (P3.6/UCB1SOMI/UCB1SCL/CAP3.3)
/GND: C1.2, C2.2, C3.2, C4.2, C5.2, C6.2, D11.2 (A2), D12.2 (A2), D13.2 (A2), D14.2 (A2), D21.2 (A2), D22.2 (A2), D23.2 (A2), D24.2 (A2), D31.2 (A2), D32.2 (A2), D33.2 (A2), D34.2 (A2), D41.2 (A2), D42.2 (A2), D43.2 (A2), D44.2 (A2), J1.2, J1.4, J1.6, J1.8, J1.10, TP4.1, U1.48 (DVSS)
/MSP430_RXD: J1.5, R3.2, TP6.1, U1.5 (P1.5/UCA0RXD/UCA0SOMI/TA1.1/TMS/A5)
/MSP430_TXD: J1.7, R2.2, TP5.1, U1.4 (P1.4/UCA0TXD/UCA0SIMO/TA1.2/TCK/A4/VREF+)
/MSP_RST: C4.1, J1.3, R1.2, TP2.1, U1.2 (~RST/NMI/SBWTDIO)
/MSP_TEST: J1.1, TP1.1, U1.3 (TEST/SBWTCK)
/MSP_VREG: C3.1, U1.31 (VREG)
/MSP_XIN: C5.1, U1.47 (P2.1/XIN), Y1.1
/MSP_XOUT: C6.1, U1.46 (P2.0/XOUT), Y1.2
/P3V3_MSP430: C1.1, C2.1, J1.9, R1.1, R2.1, R3.1, TP3.1, U1.1 (DVCC)
/PAD1_RX0: D11.1 (A1), E1.1 (RX0), E1.5 (RX0), R11.1
/PAD1_RX1: D12.1 (A1), E1.2 (RX1), R12.1
/PAD1_RX2: D13.1 (A1), E1.3 (RX2), R13.1
/PAD1_RX3: D14.1 (A1), E1.4 (RX3), R14.1
/PAD2_RX0: D21.1 (A1), E2.1 (RX0), E2.5 (RX0), R21.1
/PAD2_RX1: D22.1 (A1), E2.2 (RX1), R22.1
/PAD2_RX2: D23.1 (A1), E2.3 (RX2), R23.1
/PAD2_RX3: D24.1 (A1), E2.4 (RX3), R24.1
/PAD3_RX0: D31.1 (A1), E3.1 (RX0), E3.5 (RX0), R31.1
/PAD3_RX1: D32.1 (A1), E3.2 (RX1), R32.1
/PAD3_RX2: D33.1 (A1), E3.3 (RX2), R33.1
/PAD3_RX3: D34.1 (A1), E3.4 (RX3), R34.1
/PAD4_RX0: D41.1 (A1), E4.1 (RX0), E4.5 (RX0), R41.1
/PAD4_RX1: D42.1 (A1), E4.2 (RX1), R42.1
/PAD4_RX2: D43.1 (A1), E4.3 (RX2), R43.1
/PAD4_RX3: D44.1 (A1), E4.4 (RX3), R44.1

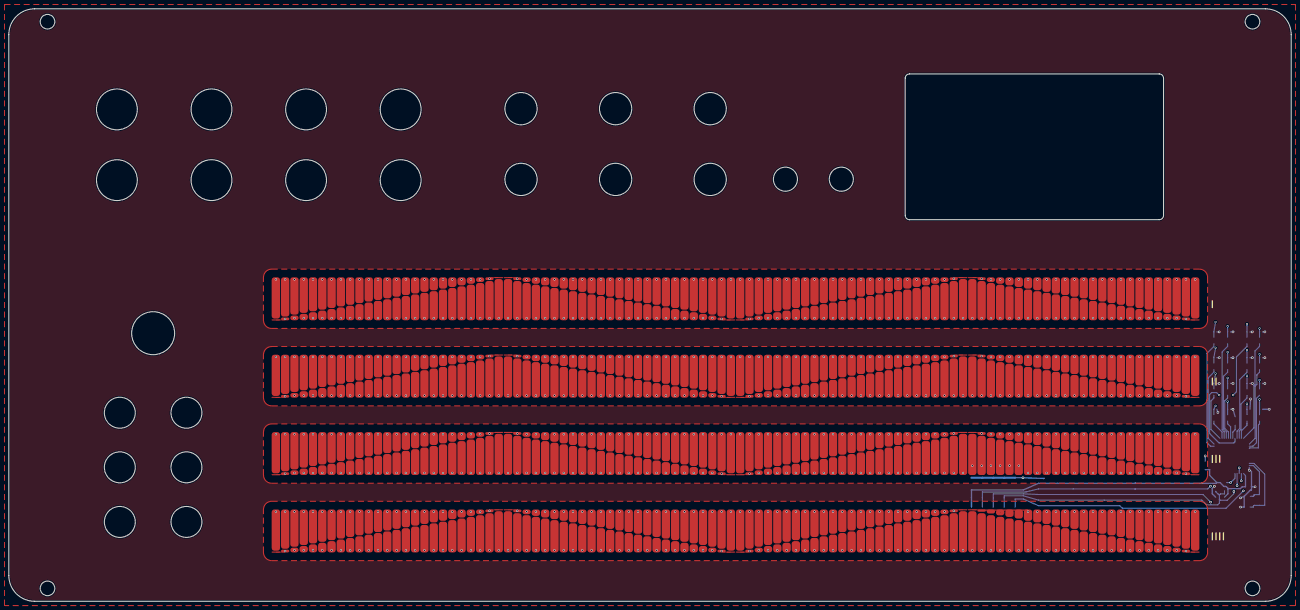
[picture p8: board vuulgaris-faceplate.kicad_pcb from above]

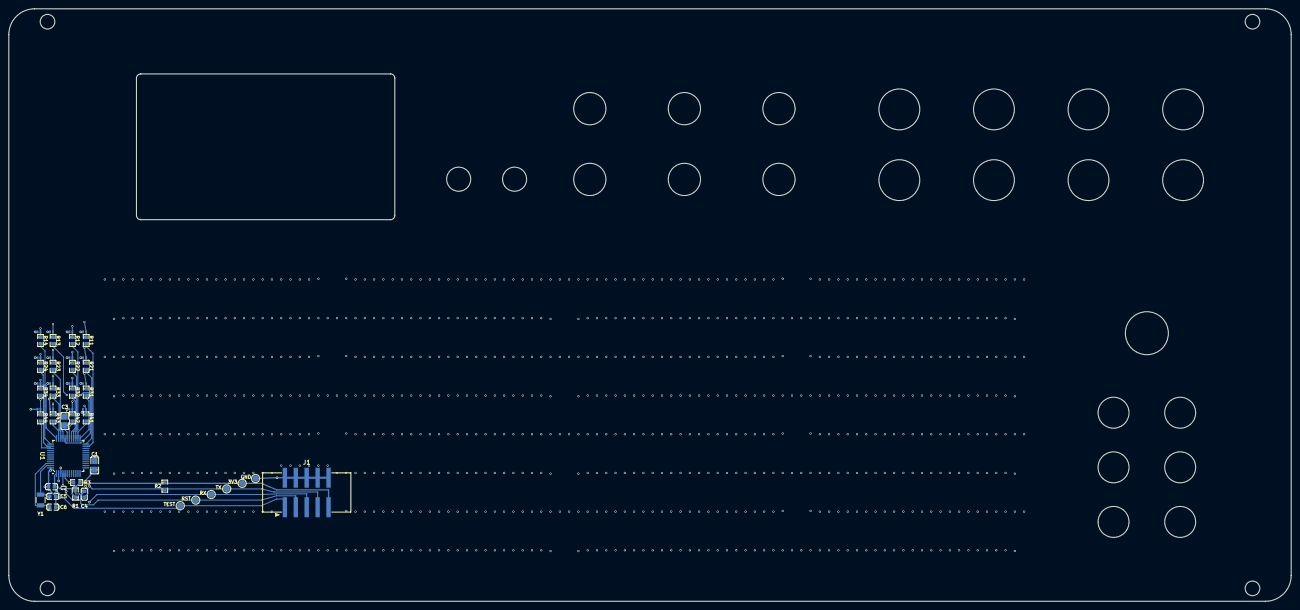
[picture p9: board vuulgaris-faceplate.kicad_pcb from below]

Board: 4 copper layers, 298.3 x 137.8 mm, 54 parts (50 on the bottom side), 41 nets.

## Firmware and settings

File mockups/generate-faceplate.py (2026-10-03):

#!/usr/bin/env python3
"""
Vuulgaris V1 faceplate generator.

Emits a TRUE-SCALE SVG in millimetres (1 user unit = 1mm) of the Salamis Tablet
faceplate, including the real comb-tooth electrode geometry per ADR 0003.

    python3 generate-faceplate.py               > faceplate.svg   # fills the view
    python3 generate-faceplate.py --fab         > faceplate.svg   # exact mm, for the fab
    python3 generate-faceplate.py --check                  # verification report, no SVG
    python3 generate-faceplate.py --set pad_length_mm=264  # one-off override

Both outputs carry the SAME geometry in millimetre coordinates. The only
difference is the wrapper: the default emits width="100%" with a margin so it
displays large and centred, --fab emits explicit mm with flush edges.

EVERYTHING tweakable lives in CFG below. To change the layout, change a number
there. Do not go hunting through the drawing code.
"""
import math
import sys

# =============================================================================
# CFG - the only thing you should need to edit
# =============================================================================
CFG = {
    # ---- pads: the geometry everything else follows from --------------------
    # pad_length and pad_gap are INDEPENDENT. The 12:1 pad-length-to-pitch ratio
    # measured off the reference sketch was an artefact of that sketch drawing
    # pads as single strokes with no thickness. Discarded 2026-08-06.
    "pad_length_mm":     216.0,
    "pad_width_mm":       10.0,   # ADR 0003 says 10-12mm is the useful band
    # DO NOT REDUCE. design-state wants >=10mm closest approach for crosstalk,
    # and 9mm was already a compromise. Crosstalk between adjacent pads is the
    # untested failure mode in Q1, so this is the wrong place to buy millimetres.
    "pad_gap_mm":          8.0,   # was 9.0; 1mm off each of 3 gaps to fit
                                  # the shorter panel. Width stays 10.0 --
                                  # that is the sensitivity number, ADR 0003 floor.
    # Depth. The COMPOSITION is laid out in this frame and every panel part's y
    # comes out of it, scaled, so changing it RE-FLOWS the panel and moves all
    # 24 panel parts on a routed main board. None = the original Salamis 1.933:1
    # ratio (154.29mm). 129 was chosen 2026-08-09 to shrink the footprint without
    # touching the gap; 130.81 on 2026-08-26 as board + 14 (board then 116.81).
    "composition_h_mm":  130.81,
    # Size changes since then go on OUTSIDE the frame, as pure extensions.
    # +2 at the top (jack) edge, 2026-09-27: the main board's top edge and the
    # wall moved out 2mm on 2026-09-23. Every panel y grows by exactly this, and
    # place.py's OY is 7.000 + this. --check proves the offset is pure.
    "panel_top_extra_mm":    2.0,
    # +5 at the bottom (back) edge, 2026-09-27: the board slides 6mm along y to
    # clear the jacks, so the cavity is 1 + 118.81 + 6 = 125.81, not board + 2,
    # and the panel covers the box to both outer faces. Moves nothing.
    "panel_bottom_extra_mm": 5.0,

    # ---- copper: comb teeth -------------------------------------------------
    "teeth_per_zone":       25,   # x4 zones = 100 teeth/pad
    "tooth_gap_mm":       0.21,
    "top_bottom_gap_mm":  0.20,
    "min_copper_mm":      0.15,   # fab floor; slivers are dropped, not drawn
    # Fillet on every tooth's OWN four corners. Softens the outline, including
    # the pad's four extreme corners, without shortening anything. Sharp
    # corners on exposed copper are where etch undercut starts, so this helps
    # the process as well as the look. Clamped per tooth at render time.
    "tooth_fillet_mm":     0.6,   # 0 restores hard corners; max useful = T_WIDTH/2

    # Fillets remove copper from every tooth, and position is read from the
    # AREA ratio between the top and bottom bars. A fixed area loss on both
    # bars therefore bends the position curve: at 0.6mm the worst error is
    # 2.33mm on a 216mm pad. Pre-compensating the bar HEIGHTS so the filleted
    # AREAS stay linear removes it, and costs nothing but this arithmetic.
    "compensate_fillet_area": True,

    # Taper the pad ENDS along an arc by shortening the teeth near them.
    # Different thing entirely, and off: it makes the last teeth shorter
    # rather than just softening their corners.
    "pad_corner_r_mm":     0.0,

    # ---- connecting the bars ------------------------------------------------
    # Every bar is its own island of copper: nothing joins them on L1. Each
    # one takes an open through-via (decided 2026-09-28, not filled or capped)
    # down to its net's bus on L2. The project's minimum via, JLC standard.
    # The hole is copper the finger does not see, so it goes into the same
    # area compensation as the fillets. A bar too short to hold the via's pad
    # (only the 0.197mm slivers beside each zone boundary) instead gets a
    # BRIDGE across the tooth gap to its same-net neighbour, at the pad edge,
    # and gives back the bridge's copper by shortening. See connections().
    "via_drill_mm":        0.3,
    "via_dia_mm":          0.5,
    "via_inset_mm":        0.5,   # via centre from the bar's OUTER edge (pad edge)
    "bridge_h_mm":         0.3,   # bridge strip height, or the thinner bar's if less
    # Through vias come out on the BACK, so they must clear whatever sits
    # there over the pads. Only J1 does: the hanxia 2x5's pads at panel
    # (228.995, 112.5), rows over the edges of pads 3 and 4 (hanxia drawing;
    # mkboard.py placed it). tools/panelcheck.py derives these rectangles
    # from J1's real pads on the board and fails if they differ.
    "via_keepouts_mm": ((223.405, 106.75, 234.585, 111.4),
                        (223.405, 113.6, 234.585, 118.25)),
    "via_keepout_clear_mm": 0.2,  # project Default clearance

    # ---- pad markings -------------------------------------------------------
    "n_ticks":              13,   # 13 marks = 12 intervals = a TRUE centre mark
    "cross_at":     (4, 7, 10),   # 1-indexed. Centre +/-3, lands on 1/4, 1/2, 3/4.
    # The printed scale stops this far inside each end of the copper (ADR 0003,
    # "Endpoint trim": extend the copper past the printed scale). A finger's
    # centroid cannot reach the copper's end, and how far it falls short depends
    # on the finger. 6 is a large fingertip's contact radius: a finger centred on
    # the first or last mark is wholly on copper, so it reads true, and every
    # mark sits in the well-behaved middle. The scale's ends are the sample's.
    # 216 - 2 x 6 = 204mm, 17mm a division. Moves only the ink, never the copper.
    "scale_inset_mm":      6.0,
    # Pad bottom to the top of the scale's ink (a cross's upright): the crosses
    # hang from the pad's mask frame, and the ticks start 0.5 below, on the gold.
    "scale_top_mm":        2.0,

    # ---- the face (2026-09-29, ADR 0013) --------------------------------------
    # The front is exposed ENIG on a GND copper face, and every printed mark is
    # black soldermask on it (the fab prints no silk on bare copper). Each pad sits
    # in a mask frame this wide, from its copper to the gold: the gap between the
    # sensors and the grounded face. Right of the pads one small masked patch covers
    # the routing vias, flush with the frames; the right-hand numerals are silk on
    # it. hardware/faceplate/design/mkface.py builds all of it on the board.
    "pad_frame_mm":        2.0,
    # The frames and the patch are one block of mask, filleted: its outer corners by the
    # frame's own width, so the frame runs 2mm round each pad's corner too (the arcs
    # centre on the pad's corners); its inner ones, where the gaps between the pads meet
    # the patch, by less than half the 4mm gap, or the gap would close.
    "mask_fillet_mm":      2.0,
    "mask_fillet_inner_mm": 1.0,
    # the patch's right edge: past the network grid's last vias (their copper ends at
    # x 293.5, hardware/faceplate/design/mkcells.py) and their mask margin
    "via_patch_x1_mm":   294.5,
    "numeral_side_mm":     2.8,   # pad end to the side numerals: clear of the frame;
                                  # the right-hand ones, silk on the patch, clear of its vias

    # ---- upper region controls ----------------------------------------------
    "knob_r_mm":           8.0,   # 16mm knob
    "knob_pitch_mm":      22.0,
    "offset_knob_r_mm":   10.0,   # dual-gang ANALOG pot, deliberately larger
    # TWO switches, doing two DIFFERENT jobs. Both are DPDT, both are one pole
    # per stereo side ganged on one actuator, both are analog routing on the LPG
    # board, both cost zero Daisy pins.
    #   slot 1  LPG MODE    stereo VCF or stereo VCA
    #   slot 2  SOURCE      resample or external input
    # There is NOT a separate VCF/VCA switch per channel. The LPG is one stereo
    # unit, so mode is a single decision applied to both sides. Clarified
    # 2026-08-07 after that was described wrongly.
    "n_switches":            2,
    "switch_reserve_slots":  2,   # hold the row where it was; see ui_w
    # Dailywell 2MD1T1B1M2QES (Thonk DW3): the panel opening is a ROUND bushing
    # hole, not a slot. switch_w/h stay as the LAYOUT footprint the switch
    # occupies in the row; switch_hole_d_mm is what actually gets cut.
    # 5.6, not Dailywell's 4.95 (2026-09-28): the bushing is 10-48 UNS, 4.83mm
    # over the thread, and 4.95 is the drawing's hole for a switch HUNG from the
    # panel by its nut. Ours is soldered to the main board AND passes the
    # faceplate, so the hole takes up the bushing's +-0.25 position tolerance
    # (drawing) and the faceplate's +-0.25 float on the pots: 0.385 a side.
    "switch_hole_d_mm":    5.6,
    # Drop the switch pair below rule 3. Centred on R3 their through-holes land
    # inside the 1/4" jack footprints, and J8's pad 5 sits BETWEEN SW2's two pad
    # columns -- nowhere to nudge it, J7 blocks left and DS1/J9 block right.
    # 8.2mm puts them clear of the jacks (which end at pcb y 25) and level with
    # the lower pot row, which reads fine.
    "switch_y_shift_mm":   8.2,
    # Nudge the pair LEFT. At 0 SW2's body sits 0.33mm off the OLED.
    "switch_x_shift_mm":  -4.0,
    "switch_w_mm":         9.0,
    "switch_h_mm":        20.0,
    "oled_w_mm":          70.0,
    # Nudge the OLED left of where the composition flow puts it. At 0 its pads
    # collide with the SD socket and the USB-C, which live in the top-right
    # corner of the board -- a board-side constraint the composition cannot see.
    "oled_x_shift_mm":    -6.1,
    "oled_h_mm":          42.0,
    # ---- the OLED WINDOW (2026-09-28) ---------------------------------------
    # The cut is sized from the module, not from the oled_w/h box above -- that
    # box is a layout stand-in anchored on the header column. HS242L01W4S01
    # drawing (datasheets/HS242L01W4S01-OLED.pdf, section 1.4): PCB 72 x 43
    # (the spec table's "68 x 43" is the hole pitch), the 9-pin header 2.5mm in
    # from the left edge. Along the long axis the glass (FRAME 62.1), VA (57)
    # and AA (55.01) are centred, at 4.95 / 7.5 / 8.5 from each end. Across it
    # they are not: AA 5.11 below the top edge and 10.4 above the bottom, glass
    # 2.1 from the top and 1.05 from the bottom. The wide black band -- where
    # the flex bonds -- is on the player's side, which is the side that needs
    # the viewing margin. The main board's DS1 matches: holes 68 x 39 apart,
    # header at the left edge, pin 1 at the bottom.
    "oled_hdr_to_edge_mm":  2.5,
    "oled_aa_mm":    (8.5, 5.11, 55.01, 27.49),    # x from left edge, y from top edge, w, h
    "oled_glass_mm": (4.95, 2.1, 62.1, 39.85),
    # Stack-up: the pots are the datum, outer face 11.6mm above the main board;
    # the display face at lift + 4.2 (module height). The lift is not chosen yet
    # -- 3-5mm on a 1x9 socket and nylon standoffs (hardware/faceplate/README.md
    # section 4) -- so the window is sized at the DEEPEST, 3mm, and only gets
    # better if the module ends up higher.
    "panel_outer_mm":       11.6,
    "oled_module_h_mm":      4.2,
    "oled_lift_min_mm":      3.0,
    # How far past the active area the window opens, at that depth. The window
    # never opens nearer the glass edge than oled_glass_margin_mm (placement:
    # the faceplate locates on 7.5mm holes round M7 pots, +-0.25), so beyond the
    # AA it shows black glass, never the module's PCB.
    "oled_view_player_deg": 45.0,   # toward the player (+y): whole AA seen at 45 deg
    "oled_view_side_deg":   30.0,   # left, right and far, as far as the black glass allows
    "oled_glass_margin_mm":  1.0,
    "oled_window_r_mm":      1.0,   # corner radius: JLC routes internal corners round anyway
    "encoder_r_mm":        9.2,
    # Controls live in ONE column in the left margin: encoder, shift, then the
    # four channel buttons. Decided 2026-08-17. The pad block is pushed right to
    # open that margin; every panel-facing coordinate moves with it.
    "controls_left":      True,
    "pad_x_shift_mm":     20.0,
    "n_buttons":             4,
    "button_r_mm":         3.5,
    # Six UI buttons, 12x12 through-hole tactile, 2 wide x 3 tall. Was four
    # Cherry MX until 2026-09-06: six MX at 18mm caps on 19.05 pitch will not fit
    # the same panel area. The tactile's pads splay to 14.7mm, so the COLUMNS
    # keep the 19.05 pitch and only the ROWS tighten, to 12.7mm. Net effect on
    # the cluster envelope is 0.2mm, so ENC0 above it does not move.
    # 2026-09-08: no cap. TS1103S-12X12X14DIP (LCSC C54573007) is 14.0mm tall
    # against a panel outer face at 11.6mm, so its plunger stands 2.4mm proud and
    # IS the button face. A separate snap-on cap was only ever needed because the
    # old 7.3mm part could not reach the panel at all.
    "mx_buttons":         True,
    "mx_plunger_mm":       6.2,      # the plunger IS the button; nothing sits on the panel
    "mx_pitch_mm":        15.50,     # column pitch; floor is ~15.0, the TH pads collide below that
    "mx_row_pitch_mm":    12.7,      # bodies are 12.0 square, so 0.7mm between them
    "mx_rows":               3,
    # LAYOUT radius of a button opening: the control column's spacing was built
    # on it, so changing it re-flows SW4-SW9 on the routed main board. Was 2.25
    # (4.5mm) when a 3.8mm SQUARE stem was assumed. The hole actually cut is
    # mx_cut_d_mm, below.
    "mx_hole_r_mm":        3.30,
    # The cut, 2026-09-28: 7.2mm. TS1103S drawing: the plunger is 6.2 at our
    # 14mm height, and one-decimal dimensions there are +-0.2, so up to 6.4 --
    # which left 0.1 a side in the old 6.6 hole, less than the faceplate's own
    # +-0.25 float on the pots. A plunger that touches its hole is a sticky
    # button. 0.5 a side nominal, 0.4 at the worst plunger.
    "mx_cut_d_mm":         7.2,
    "mx_plunger_tol_mm":   0.2,

    # Shift button, directly below the encoder in the right margin. Wired to
    # A9 (PB15) on the Daisy, not to the MSP430. Tactile switch on the MAIN
    # PCB with a tall plunger through the faceplate, same standoff as the
    # encoder. Deliberately smaller than the encoder so the hierarchy reads.
    "shift_button":      False,
    "shift_r_mm":          4.0,   # 8mm cap
    "shift_gap_mm":        5.0,   # clear space below the encoder
    # Centre the encoder + button as ONE group on the pad block, rather than
    # centring the encoder and letting the button hang below it.
    "center_encoder_pair": True,
    "group_gap_mm":        6.0,   # between upper-region groups

    # ---- Salamis inscription -----------------------------------------------
    # Read directly off the photographed inscription: PLAIN SINGLE LETTERS.
    # An earlier pass theorised these were compound PI-nesting numerals; that
    # was over-reading. They are simple incised letterforms, a few strokes each.
    #   T  tau     P rho    X chi     F digamma-like    H eta
    #   A  alpha   N pi     G gamma   C lunate sigma
    # LEFT MARGIN ONLY.
    # OFF 2026-08-09. The monoline stroke glyphs running down the left margin
    # did not read well at 4.4mm. The letterforms are kept here rather than
    # deleted, so turning this back on restores them unchanged.
    "salamis_marks":     False,
    "inscription":        "TPXFHFANGFCTX",
    "inscription_h_mm":    4.4,
    "inscription_below_divider": True,   # never in the control strip
    "inscription_left_only":     True,

    # ---- placement ----------------------------------------------------------
    "encoder_lower_right": True,  # False puts it back in the upper strip
    "straight_divider":    True,  # False restores the irregular crack line
    # Push the divider rule DOWN from where the reference composition puts it.
    # Also buys the OLED headroom, since the screen centres in the strip above.
    "divider_nudge_mm":    4.0,

    # ---- how the SVG presents itself ----------------------------------------
    # The panel geometry is IDENTICAL either way. This only changes the wrapper.
    # ---- enclosure -----------------------------------------------------------
    # The panel screws down ON TOP of the cheeks, so the cheeks sit UNDER the
    # panel's outer edge. Anything on the main PCB must clear them, and the main
    # PCB is therefore narrower than the panel by 2x this plus assembly slop.
    # At 15mm the upper assembly clears by only 1.14mm; at 20mm it collides.
    "enclosure_wall_mm":   6.0,
    "wall_clearance_mm":   2.0,   # minimum air between wall and nearest part
    # The composition is INSET from the panel edge by wall+clearance, so the
    # main PCB and everything on it lives inside the cavity. Without this the
    # OLED sat 4mm from the panel edge and the top wall went straight through
    # it. That bug predated the depth change; it was never caught because
    # nothing checked against an enclosure.
    "inset_composition": True,
    "panel_screw_inset_mm": 3.0,  # from panel edge, into the wall top
    # Panel corners, filleted 2026-09-28 (Dylan: a rounder feel). The enclosure's
    # outer corners take the same radius. At the wall thickness the cavity keeps
    # square inside corners, so the main board's outline is untouched; any bigger
    # and the cavity -- and the board -- would need rounding too. The cost: a
    # screw can no longer sit in the corner. At 3mm in, its head has to clear the
    # arc, so corner screws go at least panel_screw_corner_min_mm along the edge.
    "panel_corner_r_mm":    6.0,
    "panel_screw_corner_min_mm": 9.0,
    # The panel screws (2026-09-28): M3, clearance 3.4 (ISO 273 medium), down into
    # the wall tops. Four, one at each corner (Dylan: "only needs four, on the corners"):
    # on the long edges, panel_screw_corner_min_mm from the corner -- as close as the r6
    # corner lets an M3 pan head sit -- 3mm in. Ten until the same day. The enclosure's
    # inserts go under them.
    "panel_screw_d_mm":     3.4,
    "panel_screw_head_d_mm": 5.5,   # M3 pan head: the art draws it, the checks clear it
    "panel_screws_long":    2,
    "panel_screws_short":   0,
    # What the cavity has to hold along y (design-state "Assembly"): the jack
    # wall's 1mm assembly gap, the main board, and the travel it slides to put
    # its jacks through that wall. --check asserts the panel covers exactly this.
    "front_gap_mm":        1.0,
    "main_pcb_h_mm":     118.81,  # 2026-09-23, after the 2mm top-edge extension
    "slide_travel_mm":     6.0,

    "fab_output":        False,   # True = explicit mm size, flush edges
    "view_margin_mm":     10.0,   # breathing room around the panel on screen

    # ---- vertical margins in the lower region -------------------------------
    # True centres the pad block between the divider rule and the bottom edge.
    # The numeral row then sits in the space below rather than being reserved
    # out of the centring, which is what was pushing the pads high.
    "center_pads_in_region": True,
    "numeral_row_mm":      7.8,   # pad bottom to numeral baseline: under the crosses,
                                  # which hang from the pad's frame
    "numeral_pt_mm":       2.7,   # glyph size (was a hardcoded 3.2)
    "bottom_margin_mm":    8.0,
    "below_divider_mm":    5.5,
}

NET_COLOR = {0: "#D85A30", 1: "#1D9E75", 2: "#378ADD", 3: "#7F77DD"}
NET_NAME = {0: "RX0", 1: "RX1", 2: "RX2", 3: "RX3"}
INK, INK2, INK3 = "#5F5E5A", "#888780", "#B4B2A9"
GOLD, MASK_INK, SILK_INK = "#D8B868", "#161616", "#F2EFE6"   # ENIG, black mask, white silk
KNOB_INK, OFFSET_INK = "#534AB7", "#993C1D"
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

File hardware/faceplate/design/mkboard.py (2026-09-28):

"""Bootstrap hardware/faceplate/vuulgaris-faceplate.kicad_pcb. ONE-SHOT.

    KPY=/Applications/KiCad/KiCad.app/Contents/Frameworks/Python.framework/Versions/3.9/bin/python3
    $KPY hardware/faceplate/design/mkboard.py            # refuses if the board exists

Runs under KiCad's Python (it needs pcbnew). It writes the skeleton the
verification loop starts from, and after that the board is edited like the
main board's: scripted through pcbnew (LoadBoard -> edit -> SaveBoard) or by
hand in Pcbnew. It is not a generator to re-run, and it will not overwrite.

What it puts on the board, all derived rather than typed:

  * 4 copper layers, 1.6mm, ENIG (ADR 0004), the main board's stackup.
  * The outline: the generator's panel, W x H, at FACE_ORG. Square corners for
    now; the enclosure decides the rest.
  * J1 on the back, pad centroid on the main board's J12 cutout centre carried
    into panel coordinates, turned so its pad 1 sits in the same direction
    from its centre as J12's (pin 1 at +x, odd row toward +y). Nets from
    design/netmap.json.
  * J1's five GND pads joined on B.Cu, pad to pad along their row. Same net,
    one connector -- and without it the skeleton fails DRC on unconnected
    pads. Everything else is left for layout.
"""
import json
import os
import sys

HERE = os.path.dirname(os.path.abspath(__file__))
FACE = os.path.dirname(HERE)
sys.path.insert(0, os.path.join(os.path.dirname(FACE), "kicad", "tools"))
sys.argv[1:1] = ["--project", "faceplate"]
import proj            # noqa: E402
import panelgeo as pg  # noqa: E402
import pcbnew          # noqa: E402

P = proj.P
MAIN = proj.PROJECTS["main"]
STOCK_FP = "/Applications/KiCad/KiCad.app/Contents/SharedSupport/footprints"
mm = pcbnew.FromMM

if os.path.exists(P.pcb) and "--force" not in sys.argv:
    sys.exit(f"{P.pcb} exists. This is a one-shot bootstrap; edit the board instead.")

HEADER = """(kicad_pcb (version 20221018) (generator pcbnew)

  (general
    (thickness 1.6)
  )

  (paper "A3")
  (title_block
    (title "Vuulgaris V1 faceplate")
    (rev "0")
  )

  (layers
    (0 "F.Cu" signal)
    (1 "In1.Cu" signal)
    (2 "In2.Cu" signal)
    (31 "B.Cu" signal)
    (32 "B.Adhes" user "B.Adhesive")
    (33 "F.Adhes" user "F.Adhesive")
    (34 "B.Paste" user)
    (35 "F.Paste" user)
    (36 "B.SilkS" user "B.Silkscreen")
    (37 "F.SilkS" user "F.Silkscreen")
    (38 "B.Mask" user)
    (39 "F.Mask" user)
    (40 "Dwgs.User" user "User.Drawings")
    (41 "Cmts.User" user "User.Comments")
    (42 "Eco1.User" user "User.Eco1")
    (43 "Eco2.User" user "User.Eco2")
    (44 "Edge.Cuts" user)
    (45 "Margin" user)
    (46 "B.CrtYd" user "B.Courtyard")
    (47 "F.CrtYd" user "F.Courtyard")
    (48 "B.Fab" user)
    (49 "F.Fab" user)
  )

  (setup
    (stackup
      (layer "F.SilkS" (type "Top Silk Screen"))
      (layer "F.Paste" (type "Top Solder Paste"))
      (layer "F.Mask" (type "Top Solder Mask") (color "Green") (thickness 0.01))
      (layer "F.Cu" (type "copper") (thickness 0.035))
      (layer "dielectric 1" (type "prepreg") (thickness 0.2104) (material "FR4") (epsilon_r 4.5) (loss_tangent 0.02))
      (layer "In1.Cu" (type "copper") (thickness 0.0152))
      (layer "dielectric 2" (type "core") (thickness 1.065) (material "FR4") (epsilon_r 4.5) (loss_tangent 0.02))
      (layer "In2.Cu" (type "copper") (thickness 0.0152))
      (layer "dielectric 3" (type "prepreg") (thickness 0.2104) (material "FR4") (epsilon_r 4.5) (loss_tangent 0.02))
      (layer "B.Cu" (type "copper") (thickness 0.035))
      (layer "B.Mask" (type "Bottom Solder Mask") (color "Green") (thickness 0.01))
      (layer "B.Paste" (type "Bottom Solder Paste"))
      (layer "B.SilkS" (type "Bottom Silk Screen"))
      (copper_finish "ENIG")
      (dielectric_constraints no)
    )
    (pad_to_mask_clearance 0)
    (aux_axis_origin %(ox)s %(oy)s)
    (grid_origin %(ox)s %(oy)s)
  )

  (net 0 "")
)
""" % {"ox": pg.FACE_ORG[0], "oy": pg.FACE_ORG[1]}

open(P.pcb, "w").write(HEADER)
b = pcbnew.LoadBoard(P.pcb)

# ---- outline: the generator's panel
_, g = pg.generator()
W, H = g["PANEL_W"], g["PANEL_H"]
r = pcbnew.PCB_SHAPE(b)
r.SetShape(pcbnew.SHAPE_T_RECT)
x0, y0 = pg.face_sheet((0.0, 0.0))
x1, y1 = pg.face_sheet((W, H))
r.SetStart(pcbnew.VECTOR2I(mm(x0), mm(y0)))
r.SetEnd(pcbnew.VECTOR2I(mm(x1), mm(y1)))
r.SetLayer(pcbnew.Edge_Cuts)
r.SetWidth(mm(0.1))
b.Add(r)
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

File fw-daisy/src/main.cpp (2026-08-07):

// Vuulgaris V1 - Daisy Patch SM firmware
//
// Skeleton. Brings up the Patch SM and an audio callback, and stubs the touch link.
// Nothing here is tuned; it exists so the toolchain can be proven before the hardware
// arrives. See docs/notes/next-steps.md.
//
// Build:  make libs   (once)
//         make
// Flash:  make program-dfu

#include "daisy_patch_sm.h"
#include "daisysp.h"

using namespace daisy;
using namespace patch_sm;
using namespace daisysp;

DaisyPatchSM hw;

// ---------------------------------------------------------------------------
// Sample buffer
//
// MUST live in SDRAM: scrubbing is arbitrary random access, so the whole sample has
// to be resident. SDRAM objects are declared globally with DSY_SDRAM_BSS and cannot
// have meaningful constructors, hence a plain static array.
//
// 64MB total. Four tracks. Sizing below is a placeholder: decide the advertised
// per-track length limit deliberately, since it is bounded by SDRAM, not card size.
// See docs/decisions/0008-boot-sram-not-qspi.md.
// ---------------------------------------------------------------------------
static constexpr size_t kNumTracks    = 4;
static constexpr size_t kMaxTrackLen  = 48000 * 20;  // 20s mono @48k, placeholder

float DSY_SDRAM_BSS sample_buf[kNumTracks][kMaxTrackLen];
static size_t       sample_len[kNumTracks] = {0, 0, 0, 0};

// ---------------------------------------------------------------------------
// Touch link
//
// The MSP430FR2675 on the faceplate reports one position per pad. Transport is UART
// (A2/A3) or I2C (B7/B8), which are alternate mappings of the same peripheral, plus an
// IRQ line signalling data-ready so we do not poll.
//
// Position is 0..resolution-1 across 175mm. Resolution is configurable in Design Center;
// 1000 gives 0.175mm per step. The real limit is jitter, not resolution: if the reported
// value wanders N counts at rest, usable points = 1000/N. Measure it.
// See docs/decisions/0003-comb-pad-rx0-wraparound.md.
// ---------------------------------------------------------------------------
struct TouchState
{
    float position[kNumTracks];  // 0.0 .. 1.0, normalised
    bool  touched[kNumTracks];
};

static TouchState touch;

static void TouchInit()
{
    for(size_t i = 0; i < kNumTracks; i++)
    {
        touch.position[i] = 0.f;
        touch.touched[i]  = false;
    }
    // TODO: bring up UART/I2C to the MSP430, and the IRQ pin.
    // TODO: BSL flashing path over RST + TEST. Wait ~300ms after entry invocation
    //       before the first command; this BSL version is slow to initialise and
    //       skipping the wait looks exactly like a hardware fault.
    //       See docs/decisions/0005-bsl-over-daisy-uart.md.
}

static void TouchPoll()
{
    // TODO: read from the MSP430 when IRQ asserts.
    //
    // Smoothing goes here, and it is a direct latency tradeoff: scrub position jitter
    // becomes audible warble, but filtering it costs responsiveness. Do not pick a
    // filter constant before measuring real jitter on real copper.
}

// ---------------------------------------------------------------------------
// Audio
// ---------------------------------------------------------------------------
void AudioCallback(AudioHandle::InputBuffer  in,
                   AudioHandle::OutputBuffer out,
                   size_t                    size)
{
    hw.ProcessAllControls();
    TouchPoll();

    for(size_t i = 0; i < size; i++)
    {
        float sig = 0.f;

        // TODO: per-track machine (sampler or synth). Plaits is the synth engine.
        // Sampler reads sample_buf[track] at touch.position[track] * sample_len[track],
        // interpolated, with the read head following the finger.

        out[0][i] = sig;
        out[1][i] = sig;
    }

    // CV outs drive the LPG vactrols. 12-bit, and they can run at audio rate if written
    // per-sample here, though the vactrol's own lag dominates anyway.
    // hw.WriteCvOut(CV_OUT_1, v1);
    // hw.WriteCvOut(CV_OUT_2, v2);
}

int main(void)
{
    hw.Init();
    hw.SetAudioBlockSize(48);
    hw.SetAudioSampleRate(SaiHandle::Config::SampleRate::SAI_48KHZ);

    TouchInit();

    hw.StartAudio(AudioCallback);

    while(1)
    {
        // Display refreshes belong HERE, never in the audio callback.
        // CV output timing is documented as degradable by OLED and MIDI activity.
        // No full-frame redraws during timing-sensitive CV.
        // See docs/decisions/0006-ssd1309-oled.md.
    }
}

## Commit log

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2026-08-09 faceplate: shift button below the encoder
    8mm cap, centred on the encoder axis at 277.71, 117.88mm, 5mm below the
    encoder body. Tactile switch on the MAIN PCB with a tall plunger through
    the faceplate, same standoff as the encoder. Wired to A9 (PB15).
    Four new checks: on the encoder axis, clears the encoder, clears the pads,
    clears the right-side numerals, inside the panel. 26 checks pass.
    The numeral check initially failed on Y proximity alone, which was a bad
    test: the numerals sit 8.81mm left of the button in X, so being on the
    same row is not a collision. Rewritten to test actual 2D overlap.
    [generate-faceplate.py]
2026-08-09 faceplate: rounded pad ends, and pads centred below the divider
    Rounded ends, r=2.5mm, as REAL geometry: each tooth near an end is
    shortened to follow the arc. Not an SVG clip path, which may not survive
    the trip into a PCB tool. Sharp corners on exposed copper are also where
    etch undercut starts, so this is not purely cosmetic.
    Pads moved down 5.76mm. Centring previously subtracted the numeral row
    before centring, leaving 5.6mm above the block and 17.1mm below. Now
    11.36 above / 11.36 below, with the numeral row living in the space
    beneath (numeral_row_mm 9.0 -> 5.5 so it still fits).
    The copper checks were rewritten to inspect the emitted geometry instead
    of recomputing from presences(),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
    [generate-faceplate.py]
2026-08-09 faceplate: fillet each tooth's own corners, undo the end taper
    Corrected. The previous commit tapered the pad ENDS along an arc, which
    shortened the last teeth. What was wanted was the teeth's own corners
    softened, leaving every tooth full length.
    tooth_fillet_mm = 0.35, emitted as rx on each rect and clamped per tooth
    to half the smaller dimension. 8 of 200 teeth hit the clamp, the 0.236mm
    bars, which get 0.118mm instead. Without the clamp those degenerate into
    lozenges.
    pad_corner_r_mm set to 0.0. The arc-taper code stays as an option since
    it works, it just was not the ask.
    Full-length teeth are back: 11.564mm at the pad ends. 32 checks pass.
    [generate-faceplate.py]
2026-08-09 faceplate: heavier tooth fillet, with area pre-compensation
    tooth_fillet_mm 0.35 -> 0.6 for a visibly softer outline.
    Fillets remove copper, and position is read from the AREA ratio between
    the top and bottom bars, so a bigger fillet bends the position curve:
    2.30mm of error on a 216mm pad at r=0.6, rising to 5.28mm at the maximum
    useful 0.975. Bar heights are now pre-compensated so the FILLETED areas
    stay linear. Error goes to 0.00mm at every radius tested.
    Two bugs found on the way, both by the new checks:
    The first compensation used a closed form assuming both bars lose the
    same copper. They do not: a short bar has its fillet clamped to h/2, so
    the loss is smaller, and the assumption o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
    [generate-faceplate.py]
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2026-08-10 faceplate: check the main PCB fits inside the enclosure walls
    Dylan asked whether the 298x129 panel accounted for the motherboard
    having to be narrower to clear the cheeks. It did not, and it is tight.
    The panel screws down ON TOP of the cheeks, so the cheeks sit under the
    panel's outer edge and everything on the main PCB has to clear them. The
    upper assembly spans x 16.14 to 282.14, i.e. only 16.14mm of margin.
    cheek clearance to knobs/OLED
    6mm 10.14mm OK
    10mm 6.14mm OK <- chosen
    15mm 1.14mm TIGHT
    20mm -3.86mm COLLIDES
    So the wall thickness is bounded by the CONTROL STRIP, not the pads,
    which have 41mm of margin. 20mm cheeks are not an op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
    [generate-faceplate.py]
2026-08-10 faceplate: inset the composition so an enclosure actually fits
    Dylan asked whether the panel size accounted for the PCB below needing
    clearance for the walls. It did not, and chasing it found a bug that had
    been there the whole time.
    The rules scale WITH the panel, so rule 1 always sat ~7mm from the top
    edge and the OLED hung 2mm above that, i.e. 4mm from the panel edge. Any
    top wall went straight through the screen. At the original 154mm depth
    the OLED top was 5.19mm, so this was never about the depth reduction.
    Nothing caught it because nothing checked against an enclosure.
    Fixes:
    - composition INSET from every panel edge by wall + clearance
    - OLED CENTRED in the upper strip instead of h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
    [generate-faceplate.py]
2026-08-10 faceplate: nudge the divider rule down 4mm
    divider_nudge_mm pushes the rule below where the reference composition
    puts it, independently of the panel scaling. 53.10 -> 57.10.
    It also buys headroom in both directions, because the OLED centres in the
    strip above the rule:
    OLED to divider +1.55 -> +3.55mm
    cavity TOP +3.55 -> +5.55mm
    pads above/below 9.45 -> 7.45mm
    Bounded by the pad block plus the numeral row still fitting below: 71.5mm
    of content in 81.9mm of region, and the bottom numerals now sit at 136.05
    of 139.00. Roughly 6mm of nudge left before that binds.
    44 checks pass.
    [generate-faceplate.py]
2026-08-10 faceplate: turn off the left-margin inscription glyphs
    The monoline stroke letterforms running down the left margin did not read
    well at 4.4mm. salamis_marks -> False.
    The glyph drawing code and the TPXFHFANGFCTX sequence stay in the file
    rather than being deleted, so flipping the flag back restores them
    unchanged if a better treatment turns up. Six checks that only exist to
    police the inscription drop out with it.
    38 checks pass.
    [generate-faceplate.py]
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2026-08-18 hardware: KiCad project for the main PCB, migrated off EasyEDA
    43 components, 160 connections, 58 nets, all 43 footprints placed.
    The EasyEDA version was abandoned because its API repeatedly reported success
    for writes it had not performed, and produced a board where P3V3_DAISY was
    shorted to I2C_SDA across 9 pads with both LDO outputs on GND. No ERC flags any
    of that, because every one of those is an electrically legal connection. It was
    only ever caught by diffing pad nets against an explicit intended map.
    So the design is generated from tools/netmap.json and verified against it:
    (a) every intended pin carries its net 160/160
    (b) no net carries an unintended pin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
    [vuulgaris.kicad_pcb, vuulgaris.kicad_sch]
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2026-08-18 hardware: Daisy on the right wall for USB, jacks along the top edge
    The Daisy is rotated 90 degrees hard against the right wall, putting its USB-C at
    (282.5, 85.2), 1.8mm inside the edge. That reverses the recorded decision that USB
    access meant unscrewing the module, and it costs no pins: DFU and USB MIDI device
    both run on the module's own connector, so A8/A9 stay free as already decided.
    Only the right wall works. USB, the D header and the C header are all on the same
    long edge of the module, so whichever wall the USB faces the SD and CV face too.
    The left is blocked by ENC0 and the MX cluster -- about 16mm clear against the
    module's 68mm -- and the top 47mm is entirely panel controls.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
    [vuulgaris.kicad_pcb, vuulgaris.kicad_sch]
2026-08-18 hardware: right-angle 3.5mm jacks so the CV/gate IO can exit an edge
    J2-J5 were WQP-PJ398SM, a vertical Thonkiconn: three pads in a line, no barrel
    overhang, plug axis PERPENDICULAR to the board. It mounts through a front panel
    and cannot exit a board edge at all, which is why they were still parked at the
    bottom edge -- the one edge nothing is allowed to come out of.
    PJ-376 (C22355746) replaces it: through-hole right angle, 16.5 x 9.2mm with an
    8.5mm barrel overhang past the pads, so the plug axis runs parallel to the board
    and exits the top edge like the 1/4" jacks. Three contacts -- tip, sleeve, switch
    -- uniquely numbered, and the symbol's pin numbers equal the footprint's pad names
    as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
    [vuulgaris.kicad_sch]
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2026-08-19 hardware: SD card to the back as well
    J1 moves to B.Cu, rotated 90 so that after mirroring the card slot still faces
    left into open board rather than at the Daisy 2.5mm away. Position unchanged at
    (236, 100).
    Flipping in the file means three things, not one: every F.* layer token becomes
    B.* (103 of them here), and mirroring negates each pad's relative angle, so the
    absolute angle is fp_angle MINUS the library angle. The local pad coordinates are
    NOT rewritten -- KiCad stores them unmirrored and applies the mirror when it
    renders, which is why the earlier flipped jacks still read as their library
    coordinates.
    Verified four ways: no F.* tokens left in the block, 156 non-circular pads at the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
    [vuulgaris.kicad_pcb]
2026-08-19 hardware: bring every jack forward so the barrels reach through the wall
    The barrels were stopping at board y +0.50 -- half a millimetre INSIDE the board
    edge, 7.5mm short of daylight. Nothing would have plugged in.
    Geometry, board coordinates: edge at y 0, a 1.0mm assembly gap, then 6.0mm of
    wall, so the outer face is y -7.00.
    J2-J5 origin y 5.00 barrel tip -7.00 flush with the outer face
    J7-J10 origin y 15.05 barrel tip -9.00 2.00mm proud
    The 1/4" jacks have room to spare and could reach 8.20mm proud. The 3.5mm jacks
    are at their limit: PJ-376's barrel is 12.00mm from origin to tip while its pads
    reach 4.30mm the other way, so flush is the most it can do without walking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
    [vuulgaris.kicad_pcb]
2026-08-19 hardware: arrange the support parts by what they actually serve
    J1 first: its body sat 0.91mm from the Daisy's A header, whose through-hole pins
    protrude to the back face where J1 now lives. Moved up 8mm -- clearance 8.91mm to
    the body, 10.65mm pad to pad -- for 3.2mm on the worst SD trace (39.50 -> 42.72).
    Then everything that is not panel-facing, placed from the netlist rather than by
    eye. Two rails leave U1.A6:
    P5V --+-- FB1 -- C24 -- U5 -- C21, C20 --> DS1.2
    +-- FB2 -- C25 -- U6 -- C23, C22 --> the faceplate PCB (no consumer yet)
    Both LDOs sit with their input from the right and their TAB facing the load: on a
    SOT-223 the tab is Vout and sits opposite the input pin, so the c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
    [vuulgaris.kicad_pcb]
2026-08-19 hardware: SD slot faces up, so the card drops in from above
    J1 rotated to 0 on the back, which points the slot at the top edge. Rotating also
    swaps the socket's aspect -- 15mm wide becomes 16.1mm -- which pushed it into U1's
    pads, so it moves left to x232 with 4.41mm of clearance.
    Costs about 7mm on the SD traces, worst case 42.7 -> 50.5mm. Acceptable for 1-bit
    SDMMC over a ground plane.
    Checked that the card can actually go in: an 11mm-wide path with 18mm of travel
    straight up from the mouth is clear of every other back-side part. R20 and R21 lie
    under that path in plan view but are on the front face, so the card rides past
    them.
    Back-side rotation rule again: the transform is front(lx,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
    [vuulgaris.kicad_pcb]
2026-08-19 hardware: flip J1 180 degrees
    Card entry now at the bottom of the socket, contacts at the top.
    body y[86.70, 101.70]
    contacts y 85.90
    entry y 101.70
    Clearances unchanged: 7.28mm to the Daisy's A header, 4.41mm to its pads in x.
    156 non-circular pads at library orientation, 0 pad overlaps, all 20 panel parts
    on their holes.
    [vuulgaris.kicad_pcb]
2026-08-19 docs+hardware: main encoder moves to U4, and poll Port B at 2kHz
    ENC0's A, B and push go to U4 GPB0-2 instead of the Daisy's D3, D4 and B9. U4's
    Port B was entirely unused; U3 is full at 16/16.
    ENC0_A 255.0 -> 74.6 mm
    ENC0_B 249.7 -> 71.0 mm
    ENC0_PUSH 223.9 -> 75.2 mm about 508mm of trace saved
    This reverses a recorded decision -- pin-allocation said the main encoder stayed
    on the Daisy for latency -- and the revision explains why that holds. The real
    constraint was never latency but the 500Hz poll rate: a 3-5 rev/sec flick is
    288-480 quadrature transitions/s, which 500Hz samples only 1-2 times per
    transition. At 2kHz it is 4-7, and one GPIOB read at 400kHz is ~100us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
    [vuulgaris.kicad_sch]
2026-08-19 docs: reconcile the poll-rate figures, and correct the stale control layout
    Two inconsistencies, both pre-existing.
    The document carried "500Hz ... catching 125 transitions per second against the
    20-30 hands produce" alongside the new 2kHz requirement for ENC0. Those cannot both
    describe the same thing. 20-30 edges/sec is about 0.25 rev/sec, too slow even for a
    deliberate twist, and it is what made 500Hz look sufficient everywhere. Replaced
    with the arithmetic: edges/sec is rev/sec x PPR x 4, so 96 edges per revolution on
    a 24-PPR part.
    deliberate twist ~1 rev/s ~96 edges/s 500Hz = 5 samples/edge
    fast menu flick 3-5 rev/s 288-480/s 500Hz = 1-2, 2kHz = 4-7
    ENC1-ENC1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
    [generate-faceplate.py]
2026-08-20 hardware: power input stage — 12V barrel in, -12V from a flipped isolated module
    POS12V and NEG12V had one node each (U1.A5, U1.A1) and nothing driving them. This
    fills that.
    +12V comes straight off the barrel. The negative rail uses a 1W isolated 12V-to-12V
    module with its +Vout tied to ground, so the floating output sits at -12V. Topology
    follows mesotokyo/cheap-power-board (CC-BY 4.0), which does the same with a 10W TDK
    CC10; the forced deviations are no NJM2396 (12V in leaves no headroom to
    linear-regulate +12V), no LM7805 (the Daisy supplies 5V), the far smaller module,
    and a bleeder their part does not need.
    J11 DC-005-20A C130239 $0.14
    D1 SS34 series C8678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
    [vuulgaris.kicad_pcb, vuulgaris.kicad_sch]
2026-08-20 hardware: place the power input stage in the left-edge pocket
    All 15 parts placed on the front, x 3..40, y 41..64 -- the one region of the board
    outside the capacitive electrodes, which span x 54-270, and diagonally opposite the
    audio path in the top-right quadrant.
    J11 (3.8, 48) barrel tip lands at x -7.00, flush with the wall's outer face
    D1 L1 C29 C30 D3 y 45, the input chain left to right
    L2 C31 C32 D2 y 51, the output chain
    C28 U7 y 59, the two tall through-hole parts
    R22-R24 x 39.5, the bleeder string
    Two collisions found and fixed while placing. The first row sat at y 41 and clashed
    with ENC2 and ENC4, whose pads reach y 41.4 -- the encoder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
    [vuulgaris.kicad_pcb]
2026-08-20 hardware: power stage to the back, right of the 1/4in jacks
    The audio jacks shift left to open the space: J7/J8 into the RV1-to-OLED window at
    x 163-194, J9/J10 hard left under the OLED at x 206-235. They cannot be one run --
    the OLED's 9-pin column at x 202.75-205.55 is a wall through the middle of the top
    edge.
    The power stage follows them on B.Cu, x 240-277, y 14-42, under the OLED. It had to
    go to the back: the front is fully committed there, with the OLED body down to y 47.6
    and the Daisy from y 54. That also fixes the height worry from the previous placement
    -- C28's 12.5mm can was marginal against the ~12-13mm faceplate gap -- and puts the
    switching module on the opposite face from t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
    [vuulgaris.kicad_pcb]
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2026-08-20 hardware: J11 pad was 0.30mm over the board edge
    Pad 2 ran to y -0.30 against a top edge at y 0. The outline is milled, so that pad
    would have been cut through. Moved J11 down 1.2mm; pad 2 now starts at y +0.90.
    The barrel tip goes from y -7.00 to -5.80, so it now sits 4.80mm into the 6mm wall
    rather than flush with its outer face. Still well within a clearance hole and easily
    reached by a plug.
    The checker missed it because EDGE_OK exempted the whole of J11 from the
    body-vs-outline test -- correct for the barrel, which is meant to overhang, but it
    took the pads with it. Pads may never cross the outline, so there is now a separate
    pad-vs-outline check with no exemptions at all.
    That is th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
    [vuulgaris.kicad_pcb]
2026-08-20 hardware: J11 pad really was over the edge, and add a Gerber-based check
    The pad was still 0.40mm past the milled outline after the previous "fix", and
    place.py reported it clean both times.
    Root cause: KiCad REWRITES a footprint's local pad coordinates when you flip it --
    negating local Y and swinging pad angles 180. J11's library pads are at y -2.35,
    -2.35, +2.35; on the board they are +2.35, +2.35, -2.35. Every calculation here
    assumed the library values, so the pads were computed in the wrong place. place.py
    uses the same arithmetic that positioned the part, so it agreed with the mistake.
    J11 moved y 5.0 -> 6.2. The barrel tip is now 3.6mm into the 6mm wall, still well
    inside a clearan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
    [vuulgaris.kicad_pcb]
2026-08-23 hardware: swap the power stage to USB-C + DKM10E-12
    Reverses the 2026-08-20 barrel decision. The barrel stage was cheaper and
    smaller but had never been built -- it was invented here from a datasheet plus
    an adaptation of someone else's topology, and it needed a bleeder network to
    work around a minimum-load problem that no single 0402 could legally dissipate.
    This circuit has been built and run. It was not re-derived: the EasyEDA .eprj is
    a SQLite database, and the routed board `postpcb` stores PAD_NET records -- pad
    to net, already resolved by EasyEDA. The 23-part power block was read straight
    out of those and transcribed, so what is in the repo is what works, rather than
    a fresh reading o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
    [vuulgaris.kicad_sch]
2026-08-23 hardware: generate the power block from the .eprj instead of typing it
    Asked whether the transcription was exactly the EasyEDA circuit, and it was not.
    Nine two-terminal parts came across with pins 1 and 2 swapped -- C82, C100,
    C102, C104, C113, C112, R439, R440, R441. All six ceramics and all three
    resistors, so non-polar, so electrically identical; every polarised part was
    already correct, including all five electrolytics, both LEDs and the DKM.
    Harmless, but the whole argument for preferring this circuit over the barrel one
    is that it is the circuit that has been built and works. That argument is only
    as good as the fidelity of the copy, so "close enough" is the wrong standard
    here even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
    [vuulgaris.kicad_sch]
2026-08-24 hardware: move the Daisy to the bottom wall, power stage down the right edge
    The DKM10E-12 is 25.4mm square and through-hole. The B1212S it replaced was
    11.5 x 6.1mm and lived under the OLED without complaint; this one cannot.
    Worth being precise about what actually had to move. Only two parts in the power
    stage have through-hole pins -- U7 and the USB-C's four shell legs. The other 21
    are SMD on the back, and the screen is on the front, so the board separates them
    and they stay put. It was never the parts under the screen, it was the pins
    coming through it.
    What decides the rest is a constraint that was not written down anywhere: the
    capacitive scrub pads cover pcb x 54-270, y 57.5-124.5,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
    [vuulgaris.kicad_pcb]
2026-08-25 hardware: place the Daisy for the signals, and fix place.py's mirror flag
    MIDI is dropped -- firmware goes on by opening the box -- so the micro-USB no
    longer has to reach a wall and the Daisy's placement is unconstrained. It goes in
    the dead band between the pot row and the electrodes, x[125.5,193.5] y[42.5,82.5].
    Not beside the power stage. That is the intuitive answer and it is backwards:
    weighting wire length by how much length actually hurts each signal, sitting on
    the power stage scores 11875 against 5611. It does buy the shortest rails, 109mm
    against 355mm, and that is worth almost nothing -- they are DC, so widen the
    trace and the loss is millivolts. It pays for them with 244mm of e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
    [vuulgaris.kicad_pcb]
2026-08-25 hardware: flip the Daisy to the back, move the SD clear of it
    U1 goes to B.Cu. On the front it was competing for the gap between the main PCB
    and the faceplate, directly under the electrodes, which is the worst place for
    it. Position is unchanged at x[125.5,193.5] y[42.5,82.5] -- the carrier's pad set
    is symmetric in Y, so mirroring does not move its outline.
    J1 moves to x[129.7,146.4] y[93.9,109.7]. The slot mouth is local +y, so the card
    ejects toward the bottom edge; with U1 now on the same face the socket needs
    clearance in front of the mouth rather than merely no overlap. It gets 15.3mm to
    the board edge and 11.4mm back to the Daisy.
    Flagging an open bug found while verifying this, in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
    [vuulgaris.kicad_pcb]
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2026-08-27 hardware: shrink the board to 116.81mm and reflow the faceplate onto it
    Adopts the layout from vuulgaris2.kicad_pcb wholesale -- 43 footprints moved,
    nothing routed in either file so nothing was lost. It checks clean: no pad
    overlaps, no same-face body overlaps, 201 pads correctly oriented.
    Then moves U1 up 4.79mm. The OLED was the binding part at 5.79mm of silk gap,
    not the SD at 7.14mm. Because U1 was the lowest thing on the board, that alone
    took the achievable height from 121.59 to 116.81 -- 8.19mm rather than the "few"
    expected. Edge.Cuts redrawn to 284.30 x 116.81, panel to 298.286 x 130.810.
    The pads survive untouched: still 216 x 10mm on 19mm pitch with 9mm gaps.
    pad_width_mm was a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
    [vuulgaris.kicad_pcb]
2026-08-27 faceplate: shrink the pad gaps and numerals to fit the shorter panel
    pad_gap 9.0 -> 8.0 (pitch 19 -> 18), numeral_row 4.5 -> 3.6, glyph 3.2 -> 2.7.
    Clears the last FAIL: the bottom numeral baseline lands at 128.05 of 130.81
    against a 2mm requirement, was 130.45.
    pad_width_mm stays at 10.0. Width is the sensitivity number and 10 is the floor
    of ADR 0003's 10-12mm band, so the fit came out of the gaps instead -- those cost
    crosstalk margin between adjacent electrodes, which is the cheaper thing to spend
    here. Pad length and count are untouched: still 4 x 216 x 10mm, 100 comb teeth
    each.
    Shortening the block by 3mm also re-centres it with 6.36mm above and below
    instead of 4.86, so the numeral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
    [generate-faceplate.py]
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2026-08-27 hardware: replace the two DPDT panel toggles with DG419 analog switches
    SW1 and SW2 are gone. In their place, U8-U11: four Vishay DG419 SPDT analog
    switches, C6581, 2467 in stock. Four SPDT is exactly two DPDT -- U8/U9 are the
    MODE switch's L and R poles, U10/U11 the SOURCE switch's -- and sharing one GPIO
    per pair gangs them, which is what the mechanical version achieved with a single
    actuator. Thrown from MCP23017 U4 GPB3 and GPB4, two of the five spare pins.
    This deletes the problem rather than working around it. The blocker was that
    every DPDT footprint KiCad ships is a sub-miniature slide switch that cannot
    reach a faceplate ~10mm above the board, and the toggles that can are either ou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
    [vuulgaris.kicad_sch]
2026-08-27 hardware: SW1/SW2 back to mechanical -- Dailywell DW3, footprint from the drawing
    Reverts the DG419 analog switches. U8-U11 and their eight decoupling caps are
    gone, U4 GPB3/GPB4 are spare again, and SW1/SW2 are mechanical DPDT toggles.
    The part is a Dailywell 2MD1T1B1M2QES, DPDT ON-ON, PC pin -- Thonk sell it as
    DW3. It is the Eurorack DIY standard, used by Music Thing and Zlob among others,
    and Thonk's own note is what settles the question that blocked this all
    afternoon: soldered into a PCB these "sit at a height that matches box-style
    3.5mm sockets and PCB mounting pots", which is exactly this board's geometry.
    That is the reach problem answered by the part rather than worked around.
    T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
    [vuulgaris.kicad_sch]
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
